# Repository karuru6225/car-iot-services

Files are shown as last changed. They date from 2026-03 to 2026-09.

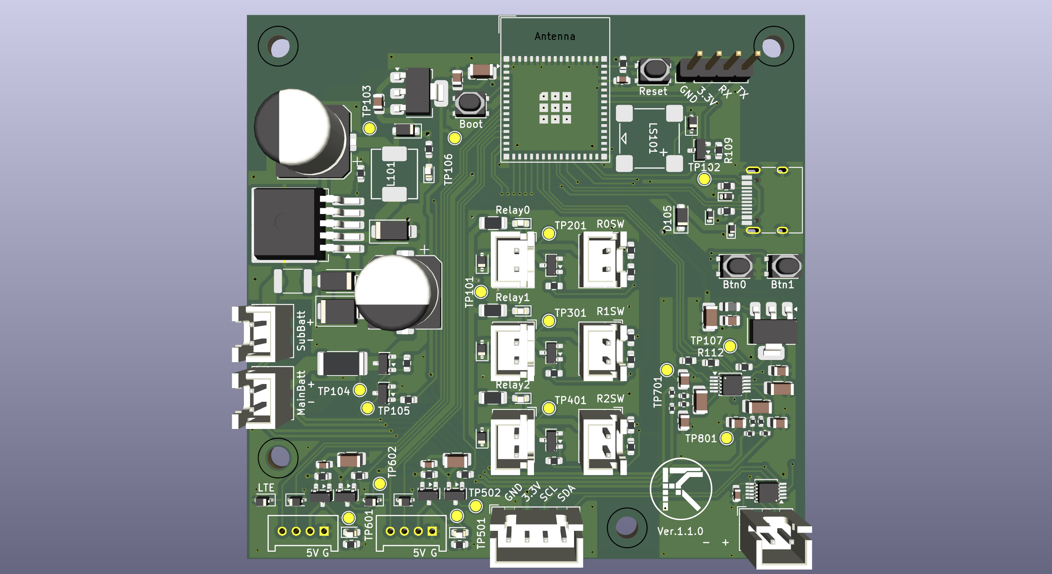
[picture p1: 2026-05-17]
test_board/m5atom_power_adc.png

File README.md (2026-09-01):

# car-iot-services

車載 IoT システム。ESP32-S3 が車載バッテリー電圧・電流・電力を計測し、
SORACOM Cat-M 経由で AWS IoT Core に送信する。
クラウド側では S3 + Athena でデータを蓄積し、CloudFront ホスティングの Web 管理画面でグラフ表示・削除操作を行える。

## システム構成

```text
ESP32-S3-MINI-1 (esp32_iot_gateway)
  ├── ADS1115 で 2 系統バッテリー電圧測定（サブ / メイン）
  ├── INA228 でサブバッテリー電流・電力・温度測定
  └── BLE スキャンで SwitchBot センサー（温湿度計 / CO2）受信
        ↓ MQTT over TLS
  SIM7080G (SORACOM Cat-M)
        ↓
  AWS IoT Core
  ├── Topic Rule → Lambda (ingest) → S3 (raw/year=.../month=.../day=.../hour=.../)
  │                                         ↓ Glue + Athena
  │                                   API Gateway → Lambda (query / delete)
  │                                         ↑ CloudFront → Web 管理画面 (index.html)
  ├── Shadow (desired/delta) → デバイス設定変更（充電制御・閾値等）
  └── IoT Jobs → OTA ファームウェア更新

  ※ 上記の LTE 経路とは別に、車内では BLE でスマートフォンと直接つながる
ESP32-S3-MINI-1 (esp32_iot_gateway)
        ↓ BLE (GATT Notify: 計測値・OBD-II)
  Android アプリ (car_iot_android)
    ├── Foreground Service で接続維持（アプリを閉じても受信継続）
    ├── Room に蓄積 → API Gateway へバッチアップロード（Cognito 認証）
    └── バッテリー / OBD / メーター表示・PiP
```

## ハードウェア

| 項目 | 内容 |
| ---- | ---- |
| MCU | ESP32-S3-MINI-1-N8（`m5atom_power_adc` 基板直付け） |
| ADC | ADS1115（I2C: SDA=GPIO17, SCL=GPIO18, ADDR=0x48） |
| 電流計 | INA228（I2C: SDA=GPIO17, SCL=GPIO18, ADDR=0x40） |
| OLED | SSD1306 128×64（I2C: SDA=GPIO17, SCL=GPIO18, ADDR=0x3C） |
| BLE | SwitchBot WoIOSensor（温湿度計）/ CO2センサー（アドバタイズ受信） |
| ボタン | GPIO26（Btn0）/ GPIO33（Btn1） |
| LTE | M5Stack U128（SIM7080G CAT-M/NB-IoT）、SORACOM SIM |
| 電源 | 車載 12V → LM2596（12V→5V）→ AMS1117-3.3（5V→3.3V）→ ESP32 |

## リポジトリ構成

```text
car-iot-services/
├── esp32_iot_gateway/     ESP32-S3-MINI-1 ゲートウェイ（アクティブ）
│   ├── ARCHITECTURE.md    レイヤー構成・依存ルール
│   ├── CONTEXT.md         実装詳細・設計決定・TODO
│   ├── OTA.md             OTA 仕様
│   ├── RELEASE.md         リリース手順（GitHub Actions）
│   └── MENU.md            OLED メニュー仕様
├── m5atom_iot_gateway/    M5Atom S3 ゲートウェイ（段階的廃止予定）
├── car_iot_android/       Android アプリ（Kotlin + Jetpack Compose、BLE 受信・アップロード）
│   └── CONTEXT.md         実装状態・実機検証メモ・UIデザインの設計判断
├── m5atom_power_adc/      新 PCB KiCad プロジェクト（電源・ADC・リレー・ESP32-S3 直付け）
│   ├── HARDWARE.md        ハードウェア設計仕様（BOM・回路・PCB レイアウト）
│   ├── CIRCUIT.md         回路設計仕様書
│   └── *.kicad_sch        階層シート構成（メイン + GroveUnit / RelayControl / VoltageSense）
├── infra/                 クラウドインフラ（Terraform）
│   ├── manage.ps1         デプロイスクリプト（plan / apply）
│   └── lambda_src/        Lambda ソースコード
│       └── TESTING.md     Lambdaユニットテストの実行方法（Docker + moto + pytest）
├── ops/                   運用スクリプト
│   ├── provision_device.ps1  ESP32 初回プロビジョニング（証明書発行・SPIFFS 書き込み）
│   ├── gen_certs.ps1      証明書生成
│   └── send_command.ps1   IoT Jobs コマンド送信
├── web/
│   ├── index.html         Web 管理画面（グラフ表示・データ削除）
│   └── admin.html         管理画面（デバイス一覧・Shadow 設定・充電制御）
├── docs/                  調査・設計メモ
├── tools/                 開発補助ツール（KiCad MCP サーバー等）
├── rtx830_filter_updater/ RTX830 フィルタ更新スクリプト
├── ARCHITECTURE.md
├── CONTEXT.md             開発引き継ぎ資料
└── SIM7080G.md            SIM7080G AT コマンドリファレンス
```

## デプロイ

### 前提

- Terraform >= 1.5
- AWS CLI（認証済み）
- 以下のファイルを `infra/` に配置（gitignore 済み）:
  - `backend.tfbackend` — S3 バックエンド設定
  - `terraform.tfvars` — 変数定義（`hosted_zone_id`, `web_subdomain` 等、`terraform.tfvars.example` を参照）

### インフラ + Lambda

`infra/` ディレクトリで PowerShell を実行:

```powershell
# 変更確認
.\manage.ps1 plan

# 適用（確認プロンプトあり）
.\manage.ps1 apply

# 確認なしで即適用
.\manage.ps1 apply -AutoApprove

# AWS プロファイルを指定する場合
.\manage.ps1 apply -Profile myprofile
```

Lambda コード（`lambda_src/`）の変更も `apply` で自動デプロイされる（`archive_file` の `source_code_hash` で変更検知）。

### Web 管理画面

`index.html` は `aws_s3_object` で Terraform 管理されているため、`manage.ps1 apply` で自動アップロードされる。
API エンドポイント・Cognito 設定はデプロイ時に Terraform が HTML 内のプレースホルダーを置換して埋め込む。

CloudFront のキャッシュ TTL はデフォルト 300 秒。URL は apply 後に確認できる:

```powershell
cd infra
terraform output web_url
```

## デバイスファームウェア

PlatformIO でビルド・書き込み。`esp32_iot_gateway/` を参照。

### 初回プロビジョニング

```powershell
cd ops
.\provision_device.ps1 -Port COM3
# AWS プロファイルを指定する場合
.\provision_device.ps1 -Port COM3 -Profile myprofile
# m5atom_power_adc v2 基板の場合（未指定時は v1 = 1）
.\provision_device.ps1 -Port COM3 -BoardVersion 2
```

スクリプトが MAC アドレスからデバイス ID（`esp32-gw-xxxxxxxxxxxx`）を生成し、AWS IoT Core に Thing を登録・証明書を発行・SPIFFS に書き込む。基板バージョンは NVS（`device/board_version`）にも書き込まれる。

同時に `-BoardVersion` に応じた Thing グループ（`ota-target-car-iot-gw-v1` または `-v2`）へも自動登録され、OTA の配信対象になる。グループに入っていないデバイスには OTA ジョブが届かない。

### OTA リリース

`vX.Y.Z` タグを push すると GitHub Actions が自動でビルド・S3 アップロード・IoT Job 作成・GitHub Release を実行する。MAJOR桁は基板シリーズ固定（1=v1基板、2=v2基板）。`src/config.h` の `FIRMWARE_VERSION_BASE` が正で、タグの数字と一致しないとビルドはエラーで停止する（先に `config.h` を更新してからタグを打つ）。

```powershell
git tag v1.2.3
git push origin main --tags
```

詳細は [esp32_iot_gateway/RELEASE.md](esp32_iot_gateway/RELEASE.md) および [esp32_iot_gateway/OTA.md](esp32_iot_gateway/OTA.md) を参照。

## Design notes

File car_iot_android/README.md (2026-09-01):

# car_iot_android

ESP32-S3ゲートウェイ（`esp32_iot_gateway`）とBLEで通信するAndroidネイティブアプリ（Kotlin + Jetpack Compose）。
バッテリー電圧・OBD-IIデータの表示に加え、Foreground Service化によりアプリを閉じてもBLE受信・データ
アップロードを継続する。Flutter版`mobile/`の後継（移植元として当面`mobile/`は残す）。

## 特徴

- **アプリを閉じてもBLE接続・受信が継続**（`CarIotForegroundService`、connectedDevice|location型）
- **CDM(Companion Device Manager)連携**でESP32のBLEアドバタイズを検知し、killed状態からでも自動起動
- **Room永続化**によるアップロードキュー（`CarIotUploadService`、dataSync型、Service強制終了への耐性）
- Cognito（Google連携）認証、位置情報付きOBD-IIデータのAPI Gatewayアップロード
- 4タブ構成（接続/バッテリー/OBD/メーター）、メータータブはゲージ4種・設定のJSON入出力に対応
- **ピクチャーインピクチャー(PiP)** 表示、計器盤ベースのナイト/デイ2テーマ

設計判断の経緯・実機検証メモは[CONTEXT.md](CONTEXT.md)、UIデザインの指針は[DESIGN.md](DESIGN.md)、
全体アーキテクチャ・フェーズ分割の計画書は[docs/car_iot_android_plan.md](../docs/car_iot_android_plan.md)を参照。

## 必要環境

- Android Studio（JBR同梱、Gradle実行に使う）
- Android実機またはエミュレータ（**BLE機能の検証には実機が必須**。エミュレータは物理Bluetoothアダプタを持たない）
- `minSdk = 36`（CompanionDeviceManagerの新API`startObservingDevicePresence(ObservingDevicePresenceRequest)`がAPI36必須のため）

## セットアップ

### 1. `infra/`を先にterraform applyしておく

Cognito（`mobile/`と同じApp Clientを共用）・API Gatewayエンドポイント一式が必要。`infra/README`または
`infra/manage.ps1`を参照。GoogleフェデレーテッドログインのOAuthクライアント作成手順は
[mobile/README.md](../mobile/README.md)の該当セクションを参照（`mobile/`と設定を共有するため一度作れば両方で使える）。

### 2. `AppConfig.kt`を作成

`app/src/main/kotlin/info/karuru/cariot/AppConfig.kt.example`をコピーして`AppConfig.kt`を作成し、
`terraform output`の値を埋める（`AppConfig.kt`はgitignore対象、実値をコミットしない）。

```bash
cd infra && ./manage.ps1 output -Profile default
```

必要な値: `cognito_mobile_client_id` / `aws_region` / `cognito_user_pool_id` / `api_endpoint`

### 3. ビルド

```bash
cd car_iot_android
./gradlew.bat assembleDebug
```

Gradle実行にはJDK（javacコンパイラ込み）が必要。システムの`JAVA_HOME`がJREのみの場合は`gradle.properties`の
`org.gradle.java.home`でAndroid Studio同梱のJBRを指す設定済み。

### 4. ユニットテスト

```bash
./gradlew.bat testDebugUnitTest
```

BLE非依存の純粋ロジック層（CRC8、OBDパーサー、チャンク再構成、アップロードスロットリング判定等）はTDDで実装済み。

### 5. 実機で起動

実機を接続し、Android Studioから実行するか：

```bash
./gradlew.bat installDebug
```

## 実車がなくてもBLE〜アップロードまで検証する（fakeobd）

OBD-IIケーブルを車両に物理接続していない環境でも、ESP32側に固定値+ランダムなダミーOBDデータを
BLE Notifyで送出させる派生env（`esp32-s3-devkitc-1-v1-develop-fakeobd`）が用意されている。

```bash
cd esp32_iot_gateway
~/.platformio/penv/Scripts/pio.exe run -e esp32-s3-devkitc-1-v1-develop-fakeobd -t upload
```

BLE接続・ゲージ表示・PiP・バックグラウンド継続・アップロードは、この構成で実機検証済み
（詳細は[CONTEXT.md](CONTEXT.md)の実機テスト結果を参照）。**実車のOBD-IIポートに接続しての動作確認はまだ**。
本番ファームに戻す時は`esp32-s3-devkitc-1-v1-develop`envで書き込み直すこと。

## 開発方針

- Android API非依存の純粋ロジック層（`obd/`, `ble/ObdChunkAssembler.kt`, `upload/`のスロットリング判定等）は
  TDD（Red→Green→Refactor）で実装する
- UI(Compose)描画・BLE実機接続・Foreground Serviceのライフサイクルは自動テストでの検証が困難なため、
  実機での動作確認を主軸とする

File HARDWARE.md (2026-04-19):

# ハードウェア設計メモ

## 概要

12V 車載バッテリー（サブバッテリー）から電源を取り、2系統のバッテリー電圧を監視する基板。
**案B（ESP32-S3-MINI-1 基板直付け）で設計確定。**

| 案 | MCU | 接続方式 | 状態 |
| -- | --- | --- | ---- |
| 案A（従来） | M5Atom S3（外付け） | Grove ケーブル 1 本（5V / GND / SDA / SCL） | 廃案 |
| **案B** | ESP32-S3-MINI-1-N8（基板直付け） | カステレーションはんだ付け | **採用** |

---

## システム構成

### 案A（M5Atom S3 外付け）

```text
[12V サブバッテリー]
        ↓
[本基板]
  保護回路（F1 → TVS1 → D1）
        ↓
  LM2596（12V → 5V）
        ↓
  CN4-A: GROVE コネクタ（5V + GND + SDA + SCL）
        ↓
[M5Atom S3] ← Grove ケーブル 1 本
  └── UART（GPIO5/6）→ U128（SIM7080G）← 別途 Grove 4線接続

[メインバッテリー +] → 分圧回路 → ADS1115 AIN0/AIN1
[サブバッテリー +]  → 分圧回路 → ADS1115 AIN2/AIN3
```

### 案B（ESP32-S3-MINI-1 基板直付け）

```text
[12V サブバッテリー]
        ↓
[本基板]
  保護回路（F1 → TVS1 → D1）
        ↓
  LM2596（12V → 5V）
        ↓
  ESP32-S3-MINI-1-N8（基板直付け）
    I2C ──→ ADS1115
    UART ──→ CN4-B: Grove コネクタ → U128（SIM7080G）

[メインバッテリー +] → 分圧回路 → ADS1115 AIN0/AIN1
[サブバッテリー +]  → 分圧回路 → ADS1115 AIN2/AIN3

[CN5: リレー出力] ←── FET × 3（GPIO 制御）※案B のみ
```

---

## 部品表（BOM）

### 電源回路（両案共通）

| Ref | 種別 | 仕様 | 数量 | 備考 |
| --- | ---- | ---- | ---- | ---- |
| F1 | ポリヒューズ | 1.5A | 1 | 過電流保護 |
| TVS1 | TVS ダイオード | P6KE18A | 1 | 車サージ対策（ロードダンプ最大60V） |
| D1 | ショットキーダイオード | SB360 | 1 | 逆接保護 |
| U1 | DC-DC コンバーター | LM2596-5.0 | 1 | 12V → 5V 固定出力 |
| L1 | インダクタ | 68μH / 1.5A 以上 | 1 | LM2596 必須部品 |
| D2 | ショットキーダイオード | SS34（3A/40V） | 1 | フリーホイールダイオード |
| C1 | 電解コンデンサ | 100μF / 35V | 1 | 入力平滑 |
| C2 | 電解コンデンサ | 220μF / 16V | 1 | 出力平滑 |
| C3 | セラミックコンデンサ | 100nF | 1 | 入力バイパス |
| C4 | セラミックコンデンサ | 100nF | 1 | 出力バイパス |

### 3.3V LDO 回路（両案共通）

| Ref | 種別 | 仕様 | 数量 | 備考 |
| --- | ---- | ---- | ---- | ---- |
| U3 | LDO レギュレーター | XC6206P332MR（SOT-23） | 1 | 5V → 3.3V、ADS1115 VDD・I2C プルアップ用 |
| C9 | セラミックコンデンサ | 100nF | 1 | U3 入力パスコン |
| C10 | セラミックコンデンサ | 100nF | 1 | U3 出力パスコン |

> 代替品: AMS1117-3.3（SOT-223）。XC6206 の方が Iq が低く（約 1μA）省電力。
> 案B では ESP32-S3-MINI-1 の 3V3 ピン（最大 ~700mA）で代替も可能だが、アナログ回路への影響を考慮して独立 LDO を推奨。

### MCU（案B のみ）

| Ref | 種別 | 仕様 | 数量 | 備考 |
| --- | ---- | ---- | ---- | ---- |
| U4 | MCU モジュール | ESP32-S3-MINI-1-N8 | 1 | LCC パッケージ、基板直付け（カステレーション） |
| R7 | チップ抵抗 | 10kΩ | 1 | EN ピンプルアップ（3.3V → EN）。省略すると起動しない |

### ADS1115 回路（両案共通）

| Ref | 種別 | 仕様 | 数量 | 備考 |
| --- | ---- | ---- | ---- | ---- |
| U2 | ADC | ADS1115 SSOP-10 | 1 | ADDR → GND でアドレス 0x48 |
| R1, R3 | チップ抵抗 | 680kΩ **1%** | 2 | 分圧上側（ch1 / ch2） |
| R2, R4 | チップ抵抗 | 22kΩ **1%** | 2 | 分圧下側（ch1 / ch2） |
| R5, R6 | チップ抵抗 | 10kΩ | 2 | SDA / SCL プルアップ（**3.3V = U3 出力**） |
| C5, C6 | セラミックコンデンサ | 100pF | 2 | AIN-GND ノイズフィルタ |
| C7 | セラミックコンデンサ | 100nF | 1 | VDD デカップリング |
| C8 | 電解 / タンタル | 10μF / 10V | 1 | VDD デカップリング |

### リレー制御回路（案B のみ）

外部リレー（最大 3 個）を GPIO で制御するための NPN BJT ドライバ回路。

| Ref | 種別 | 仕様 | 数量 | 備考 |
| --- | ---- | ---- | ---- | ---- |
| Q3, Q4, Q7 | NPN BJT | MMBT2222A（SOT-23） | 3 | hFE ≥ 100、Vceo = 40V |
| R（ベース） | チップ抵抗 | 1kΩ | 3 | Ib = (3.3−0.7)/1kΩ = 2.6mA、コイル電流 100mA に対して十分な飽和 |
| D（コイル並列） | 小信号ダイオード | 1N4148 | 3 | フライバックダイオード（リレーコイル並列、逆向き） |

```text
GPIO ──[1kΩ]──→ Base
                MMBT2222A
                Collector ──→ リレーコイル低電位側（コイル高電位側: +12V）
                Emitter  → GND

リレーコイル: +12V ─── コイル ─── Collector
                           │
                        [1N4148 逆向き]（フライバック）
```

### パワースイッチ回路（LTE モジュール・Grove 予備コネクタ電源）

AO3401A（P-ch MOSFET）+ MMBT2222A（NPN レベルシフタ）で 5V ラインを ESP32 GPIO でスイッチする。

```text
+5V ─── AO3401A(S) ─── AO3401A(D) ─── 負荷（LTE / Grove）
           ↑ Gate
         MMBT2222A(C) ── 10kΩ ── +5V
         MMBT2222A(B) ── 1kΩ ── ESP32 GPIO
         MMBT2222A(E) → GND
```

GPIO HIGH → MMBT2222A ON → Gate ≈ 0V（Vgs < −Vth）→ AO3401A ON → 電源供給  
GPIO LOW → MMBT2222A OFF → Gate ≈ +5V（Vgs = 0V）→ AO3401A OFF → 電源遮断

### ブザー回路（案B のみ）

AO3401A（P-ch MOSFET）ハイサイドスイッチで電磁パッシブブザーを駆動。

```text
+3.3V（U5出力） ─── Source(AO3401A/Q10)
                        │
                     Drain ─── LS1(+) ─── LS1(−) ─── GND
                                    │
                                [D19: 1N4148（フライバック）]
                                カソード → LS1(+)/Drain 側
                                アノード → LS1(−)/GND 側

GPIO34(SPEAKER) ──[R39: 10kΩ]──→ Gate(Q10)
```

GPIO LOW → Gate = 0V、Vgs = −3.3V → AO3401A ON → ブザー発音（**負論理**）  
GPIO HIGH → Gate = +3.3V、Vgs = 0V → AO3401A OFF → 消音

| 部品 | 値 | 備考 |
| ---- | -- | ---- |
| Q10 | AO3401A（SOT-23） | 既存 BOM 流用 |
| R39 | 10kΩ | ゲート直列抵抗（プルアップ兼用） |
| D19 | 1N4148（SOD-323 等） | フライバック保護 |
| LS1 | MLT-8530（LCSC: C94599） | 電磁パッシブ、8.5×8.5mm SMD、2.5〜4.5V |
| 電源 | +3.3V（U5 出力） | U3（+3.3VA）には接続しない |
| GPIO | GPIO34 | LEDC PWM 対応 |

**駆動条件（最大音量）：** 2700Hz（機械的共振周波数）、50% デューティ  
**最大電流：** 3.3V / ~52.6Ω（実効インピーダンス）≈ 63mA（MLT-8530 定格範囲内）

### リレーコイルセンシング回路

リレーに並列接続された外部スイッチによる ON をセンシングする分圧回路。

```text
+12V ─── 100kΩ ─── Vsense ─── 27kΩ ─── GND
                      │
               ESP32 GPIO（入力）
```

| 状態 | Vsense | 論理 |
| ---- | --- | ---- |
| リレーOFF（コイル断） | 12 × 27/(100+27) ≈ **2.55V** | HIGH（VIH = 2.475V ✓） |
| リレーON（Collector 引き込み） | ≈ 0V | LOW |

**負論理**（HIGH = リレー OFF）。コイル未接続時も 0V になる点に注意。

### コネクタ

| Ref | 種別 | 数量 | 案A | 案B | 備考 |
| --- | ---- | ---- | --- | --- | ---- |
| CN1 | JST-XH 2ピン | 1 | ○ | ○ | 12V 電源入力（+ / GND） |
| CN2 | JST-XH 2ピン | 1 | ○ | ○ | バッテリー 1 電圧入力（メインバッテリー） |
| CN3 | JST-XH 2ピン | 1 | ○ | ○ | バッテリー 2 電圧入力（サブバッテリー） |
| CN4-A | HY2.0-4P（Grove） | 1 | ○ | — | M5Atom S3 接続（5V / GND / SDA / SCL） |
| CN4-B | HY2.0-4P（Grove） | 1 | — | ○ | U128 接続（5V / GND / TX / RX） |
| CN5 | JST-XH 4ピン | 1 | — | ○ | リレー出力 × 3 + 予備 1 |

---

## 分圧回路

### 定数

| 定数 | 値 |
| ---- | -- |
| R1（上側） | 680kΩ 1% |
| R2（下側） | 22kΩ 1% |
| 分圧比 | 22k / (680k + 22k) ≒ 0.0313（1/31.9） |
| ADS1115 ゲイン | GAIN_EIGHT（±0.512V） |
| 理論分解能 | 約 1mV / LSB（バッテリー端換算） |

### 対応電圧範囲

- 最大: 約 16.4V（ADS1115 入力 0.512V = FSR）
- LiFePO4 4S: 10.0V（放電）～ 14.6V（充電）→ 0.313V ～ 0.457V
- 鉛バッテリー 12V: 10.5V ～ 14.7V → 0.329V ～ 0.460V

どちらも ±0.512V レンジ内に収まる。

---

## Grove コネクタ ピン配置

### CN4-A — M5Atom S3 接続（案A）

M5Atom S3 の Port A（HY2.0-4P）に直結する。

| ピン | 信号 | 備考 |
| ---- | ---- | ---- |
| 1 | GND | |
| 2 | VCC | 5V（LM2596 出力） |
| 3 | SDA | ADS1115 SDA（G38） |
| 4 | SCL | ADS1115 SCL（G39） |

Port A の VCC は 5V 出力であることを実機で確認済み。

### CN4-B — U128 接続（案B）

U128（SIM7080G）に Grove ケーブル 1 本で電源と UART を供給する。

| ピン | 信号 | 備考 |
| ---- | ---- | ---- |
| 1 | GND | |
| 2 | VCC | 5V（LM2596 出力） |
| 3 | TX | ESP32-S3 → U128 RXD |
| 4 | RX | ESP32-S3 ← U128 TXD |

---

## 消費電流（案B 参考値）

5V ラインのピーク電流（LTE 送信中 + BLE スキャン中の同時発生時）：

| 機器 | ピーク電流 |
| ---- | --- |
| ESP32-S3-MINI-1 | ~240mA |
| U128（SIM7080G） | ~250mA |
| ADS1115 | ~0.2mA（無視可） |
| **合計** | **~500mA** |

12V 入力電流（LM2596 効率 80% 想定）：約 260mA。F1 ポリヒューズ 1.5A は余裕あり。

---

## 予備 GPIO ジャンパランド（案B のみ）

ESP32-S3-MINI-1 の未使用 GPIO を将来の拡張向けにジャンパランドとして基板上に引き出す。
通常はオープン。使用時にハンダブリッジで導通させる。

| ランド | 想定用途 |
| --- | --- |
| JP1 | リレー 1 制御（Q1 GPIO） |
| JP2 | リレー 2 制御（Q2 GPIO） |
| JP3 | リレー 3 制御（Q3 GPIO） |
| JP4 | 予備 |
| JP5 | 予備 |

---

## PCB レイアウト指針

### ゾーン分離

```text
┌──────────────────────────────────────────────────┐
│ [CN1: 12V入力]                                   │
│      ↓                                           │
│ F1 → TVS1 → D1                                  │
│                                                  │
│ ┌─[スイッチング領域]──┐    ┌─[アナログ領域]──────┐ │
│ │ LM2596             │    │ ADS1115            │ │
│ │ L1（スイッチングノード近傍）│ │ C7/C8（VDD直近）  │ │
│ │ D2                 │    │ R5/R6（プルアップ） │ │
│ │ C1 / C2            │    │                    │ │
│ └────────────────────┘    └────────────────────┘ │
│           ↑ GND は 1 点で結合                     │
│                                                  │
│ [CN2: BAT1] → R1/R2 → ADS1115 AIN0/1            │
│ [CN3: BAT2] → R3/R4 → ADS1115 AIN2/3            │
│                                                  │
│ [CN4-A: Grove → M5Atom S3]  ※案A               │
│ [ESP32-S3-MINI-1 + CN4-B: Grove → U128]  ※案B  │
└──────────────────────────────────────────────────┘
```

### 重要ルール

1. **LM2596 のスイッチングノード**（L1・D2 が接続されるノード）のパターンは短く・面積を小さく保つ。最もノイズを放射する箇所。
2. ADS1115 は LM2596 から**基板の反対側**に配置する。
3. 分圧抵抗（R1～R4）は ADS1115 の近くに置き、パターンを短くする。
4. C7/C8（デカップリング）は ADS1115 の VDD ピン直近に配置する。
5. GND プレーン（ベタ）を使う場合も、スイッチング領域とアナログ領域の GND を **1 点で接続**する（スター GND）。
6. 案B: ESP32-S3-MINI-1 の**全 GND ピンは基板 GND に接続**する（放熱・ノイズ対策）。

---

## ファームウェアとの対応

| 設定 | 案A（M5Atom S3） | 案B（ESP32-S3-MINI-1） |
| ---- | --- | --- |
| I2C アドレス | `0x48`（ADDR → GND） | 同左 |
| SDA ピン | G38 | 要確定（ピン割り当てによる） |
| SCL ピン | G39 | 要確定（同上） |
| LTE RX ピン | GPIO6 | 要確定 |
| LTE TX ピン | GPIO5 | 要確定 |
| ゲイン | `GAIN_EIGHT`（±0.512V） | 同左 |
| 差動入力 ch1 | `readADC_Differential_0_1()` | 同左 |
| 差動入力 ch2 | `readADC_Differential_2_3()` | 同左 |

> 案B でピン番号確定後、`config.h` の `LTE_RX_PIN`, `LTE_TX_PIN` および I2C ピン定義を更新する。

---

## 精度向上のための推奨事項

- 分圧抵抗は **1% 精度品**を使用（5% 品は不可）
- 同一温度ドリフト品の抵抗を近傍配置してペア動作させる
- 必要に応じてソフトウェアでキャリブレーション補正を追加する
- 高精度が必要な場合は変換レートを 8SPS に設定し複数サンプル平均化を行う

---

## USB-C 受電回路

PC や充電器から 5V を受電するための USB-C レセプタクル回路。

| Ref | 種別 | 仕様 | 備考 |
| --- | ---- | ---- | ---- |
| CN_USB | USB-C レセプタクル | USB 2.0 | SBU1/SBU2 は NC |
| R_CC1, R_CC2 | チップ抵抗 | 5.1kΩ | CC1/CC2 → GND プルダウン（UFP 識別） |
| D_ESD | ESD 保護 | LESD5D5.0CT1G（SOT-23） | VBUS-GND 間 TVS、D+/D− 保護内蔵 |
| C_ESD | セラミックコンデンサ | 100nF | TVS と並列（高周波 ESD バイパス） |
| D4 | ショットキーダイオード | SSL36 | OR ダイオード（12V 電源と USB-C の電源切替） |

```text
USB-C VBUS ─── D_ESD ─── C_ESD(並列) ─── D4(SSL36) ─── +5V バス
                                              ↑
                              LM2596 出力も同じノードに接続（OR 接続）

CC1 ─── 5.1kΩ ─── GND
CC2 ─── 5.1kΩ ─── GND
```

USB-C から給電時は D4 のアノード側が VBUS 電圧、カソード側が +5V バス。  
LM2596 が動作中は +5V > VBUS の場合 D4 が逆バイアスになり USB-C 側への逆流を防ぐ。

---

## 回路検証結果（m5atom_power_adc.kicad_sch）

### リレー駆動トランジスタ（Q3/Q4/Q7）

MMBT2222A、`(mirror y)` 配置。ピン位置を座標計算で検証済み。

- **E（pin2） → GND2**（コモンエミッタ確認）
- **C（pin3） → リレーコイル低電位側 + LED陰極**
- LED点灯電流：I = (12 - Vce_sat - Vf) / 5.1kΩ ≈ **1.9mA**（正常点灯）

> kicad-happy / kicad-netlist-tool の解析ツールは `mirror` + `angle` 組み合わせ時に
> E/C を誤判定するバグがある。実回路はコモンエミッタで正しい。

### RelayXSense 回路（R27-R32）

| 状態 | V_sense | 論理 |
| ---- | --- | ---- |
| リレーOFF（コイル接続時） | 約 2.55V | HIGH |
| リレーON（Q または手動SW） | 約 0V | LOW |

**負論理**（HIGH=OFF）。コイル未接続時も 0V になる点に注意。

### USB-C SBU1/SBU2 ピン

USB 2.0 用途のみのため **NC（未接続）** が正しい。

---

## ADS1115 チャンネル割り当て

| チャンネル | 用途 | 測定方式 | ゲイン |
| --- | ---- | --- | --- |
| AIN0/AIN1 差動 | サブバッテリー電圧（J5） | 差動 | GAIN_EIGHT (±0.512V) |
| AIN2/AIN3 差動 | 車メインバッテリー電圧（J6） | 差動 | GAIN_EIGHT (±0.512V) |

分圧比: 22k / (680k + 22k) ≈ 0.0313。12V → 376mV、15V → 470mV（FSR内）。

複数チャンネル読み取り時は**チャンネル切り替え後に変換完了を待ってから読む**こと（`readADC_Differential_X_Y()` はシングルショットのため自動待機）。

---

## 拡張予定回路

### サブバッテリー電流計測・残量積算（LTC2944）

INA226 を廃案とし、LTC2944 を採用。DeepSleep 中もハードウェアでクーロン積算が継続できる。

| 項目 | 内容 |
| ---- | ---- |
| IC | **LTC2944IDD**（Industrial、−40〜85°C、DFN-10 3×3mm） |
| 接続 | ハイサイド（Battery+ と負荷の間）、既存 SDA/SCL に並列追加 |
| シャント | 0.625mΩ（±50mV / 80A） |
| 想定電流 | 最大 80A（常用 40A） |
| 特徴 | 16bit クーロンカウンタ、電圧・温度も計測、DeepSleep 中も積算継続 |
| フットプリント | `Package_DFN_QFN:DFN-10-1EP_3x3mm_P0.5mm_EP1.75x2.4mm` |
| 露出パッド | GND 接続必須（機械的固定）、サーマルビア 1〜2 本で GND プレーンへ |

```text
Battery(+) ─── R_SHUNT(0.625mΩ) ─── LTC2944(SENSE+/SENSE−) ─── 負荷
```

> IC の発熱は最大 1.8mW（20V × 90μA）のため、サーマルビアは熱対策ではなく機械的固定目的。

### サブ → メインバッテリー緊急充電回路

メインバッテリー電圧低下時にサブから一時的に補充する回路。

**回路構成（AO3401A + MMBT2222A 流用）：**

```text
Sub(+) ─── AO3401A(P-ch) ─── Schottkyダイオード ─── R_limit ─── Main(+)
               ↑ MMBT2222Aレベルシフタ経由
           ESP32 GPIO
```

| 部品 | 値 | 備考 |
| ---- | -- | ---- |
| Q（Pch MOSFET） | AO3401A | 既存 BOM 流用 |
| レベルシフタ | MMBT2222A | 既存 BOM 流用 |
| R_limit | **4.7Ω 3W**（C3924519、2512 SMD） | TE Connectivity 35224R7JT |

**制御ロジック：**

```text
開始: V_main < 11.5V かつ V_sub > 13.0V
停止: V_main > 12.3V または 経過時間 > 20分（安全タイマー）
間欠動作: 電圧差（ΔV = V_sub − V_main）に応じて ON 時間を変化（すべて 60秒 ON で統一可）
```

最大電流: 2.5V / 4.7Ω ≈ **0.53A**（ΔV_max = 14V - 11.5V 想定）。
最大発熱: 0.53² × 4.7 ≈ **1.3W**（定格 3W に対して余裕率 2.3 倍）。

充電電流は測定しない。制御はすべて ADS1115 で読んだ電圧値（V_main / V_sub）のみで行う。
LTC2944 はサブバッテリーの全出力電流（残量積算）を監視するが、充電回路の制御には使わない。

> 充電電流の推定値は `I ≈ ΔV / 4.7Ω` で計算できる（センサー実測ではなく計算値）。

### CAN Bus（将来検討）

ESP32-S3 内蔵 TWAI（CAN 2.0B）を使用。外付けトランシーバーのみ追加。

| 部品 | 内容 |
| ---- | ---- |
| トランシーバー | SN65HVD230（3.3V 動作、レベル変換不要） |
| 接続 | GPIO 2 本（TX/RX）+ CANH/CANL コネクタ（2 ピン） |
| 保護 | PESD1CAN 相当の TVS ダイオード推奨 |
| 終端 | 車両 CAN バスに既存終端があるため追加不要 |

---

## LED 選定

| 用途 | Ref | 色 | 選定品 | 動作電流 | 備考 |
| ---- | --- | -- | --- | --- | ---- |
| 電源インジケーター | D8 | 緑 | Würth 150060GS75000 | (5.0−3.2)/1kΩ = **1.8mA** | +5V ラインから給電、R16=1kΩ |
| リレーインジケーター | D15/D16/D18 | 黄 | Würth 150060YS75000 | (12−2.1)/5.1kΩ ≈ **1.9mA** | +12V ラインから給電、リレーコイル並列 |
| 汎用インジケーター | — | 赤 | XL-1608SURC-06（JLCPCB: C965799） | (12−2.3)/2kΩ ≈ **4.85mA** | +12V ラインから給電、1kΩ×2直列、225mcd@20mA |

> Würth 150060 シリーズ（0603）: Vf(green)=3.2V、Vf(yellow)=2.1V（typ, 20mA 時）。
> 動作電流が 2mA 前後のため、カタログ輝度（通常 20mA 時）の約 10% しか出ない。
> 明るい室内（30〜100mcd 必要）で視認するには **定格 300mcd 以上**の品を選ぶこと。
> XL-1608SURC-06（赤）は 5mA 時 ~54mcd。1kΩ を 2 個直列（各 23.5mW）で 0603 サイズ対応。

---

## PCB 配線太さ・ビアサイズ（電流パス）

1oz 銅箔（標準）、外層、温度上昇 10°C 基準。

### トレース幅

| レール / 用途 | 最大電流 | 推奨トレース幅 |
| --- | --- | --- |
| 充電回路 | ~0.5A | **0.5mm** |
| +12V 入力・LM2596 周辺 | ~1A | **1.5mm** |
| LM2596 スイッチングノード（出力ピン〜D2〜L1） | ~1A ピーク | **1.5mm**（ループ面積を最小に） |
| +5V バス | ~500mA | **0.8mm** |
| +3.3V デジタル | ~350mA | **0.5mm** |
| +3.3VA アナログ・信号・GPIO | <5mA | **0.3mm** |

### ビアサイズ

| 電流 | 穴径 | ランド径 | 備考 |
| ---- | ---- | --- | ---- |
| ~500mA | 0.4mm | 0.8mm | 充電回路 |
| ~1A | 0.4mm | 0.8mm | +12V・スイッチングノード |
| ~500mA | 0.4mm | 0.8mm | +5V バス |
| <100mA | 0.3mm | 0.6mm | 信号線・+3.3V |

### LM2596 スイッチングノードの注意

スイッチングノード（LM2596 出力ピン〜D2〜L1 の三角ループ）はノイズのアンテナになるため、**ループ面積を最小化**することを最優先にする。トレース幅よりもパターンの短さ・小ささが重要。

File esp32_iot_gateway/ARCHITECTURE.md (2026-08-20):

# アーキテクチャ概要

## 層構成

3層アーキテクチャ（device / domain / service）で `src/` 以下を管理する。

```
src/
├── main.cpp          エントリポイント。各層を組み合わせてユースケースを実行する
├── config.h          全層から参照可能な定数・宣言（FIRMWARE_VERSION, SLEEP_INTERVAL_SEC 等。FIRMWARE_VERSIONはBOARD_VERSIONで基板シリーズ別に分岐）
├── config.cpp        config.h の実装（デバイスID取得, NVS アクセス等）
├── board_pins.h      全層から参照可能なピン配置（BoardPins構造体、boardPins()）。BOARD_VERSIONに応じてboard_pins_v1.h/v2.hをinclude
├── board_pins_v1.h   m5atom_power_adc v1基板の実ピン値
├── board_pins_v2.h   m5atom_power_adc v2基板の実ピン値
├── logger.h/.cpp     全層から参照可能なシリアルデバッグ出力（横断的関心事。実装はservice/log_storage.hに委譲）
├── provision.cpp     プロビジョニング専用（provision env のみビルド。通常ビルドから除外）
├── device/           ハードウェアドライバ層
├── domain/           ビジネスロジック層
└── service/          ユースケース層
```

---

## 各層の役割

### device/

ハードウェアへの直接アクセス。I2C / UART / GPIO / ATコマンドの制御を担う。
上位層（domain / service）を include してはいけない。

| ファイル | 役割 |
|---|---|
| `lte.h/.cpp` | SIM7080G ATコマンド制御（GPRS接続, 証明書アップロード, 電源管理, ファイル読み取り・削除） |
| `ble_scan.h/.cpp` | BLE スキャナー（SwitchBot Manufacturer Data 受信、FreeRTOS キュー経由で domain に渡す）。`start()`はブロッキング版（menu.cppのBLE登録画面用）、`startAsync()`/`isScanning()`/`stop()`は非同期版（monitor.cpp/main.cppが使用） |
| `ble_peripheral.h/.cpp` | `BlePeripheral` クラス。GATT Peripheral（計測値 Notify + 設定 R/W）、Passkey ペアリング |
| `ads.h/.cpp` | ADS1115 I2Cドライバ（`adsReadDiffMain()` = AIN0/AIN1 = メイン、`adsReadDiffSub()` = AIN2/AIN3 = サブ） |
| `ina228.h/.cpp` | `Ina228` クラス。INA228 I2Cドライバ（電流・電力・温度・積算電荷量の読み取り、電荷リセット） |
| `oled.h/.cpp` | SSD1306 OLEDドライバ（表示制御） |
| `speaker.h/.cpp` | ブザー / スピーカードライバ（tone PWM制御） |
| `button.h/.cpp` | デバウンス・長押し検出（`ButtonEvent`: BTN0_SHORT / BTN0_LONG / BTN1_SHORT / BTN1_LONG）、ピンは`begin()`で`boardPins()`から取得 |
| `can.h/.cpp` | GU0コネクタ経由のTWAI（CAN）ドライバ。Honda N-VAN OBD-II Mode 01（29bit拡張アドレッシング）の送受信、バスオフリカバリ。ISO-TP（ISO 15765-2）マルチフレーム受信（Flow Control自動送信）、複数PIDをまとめて1フレームで要求する多PID送信に対応 |

### domain/

ハードウェアにもネットワークにも依存しないビジネスロジック。
device / service を include してはいけない。標準ライブラリのみ使用可。

| ファイル | 役割 |
|---|---|
| `measurement.h` | 計測値の構造体（VoltageReading, PowerReading） |
| `telemetry.h/.cpp`  | `buildConfigPayload`（Shadow reported用JSON）+ `ITelemetryEncoder`（テンプレートメソッド。`JsonTelemetryEncoder`/`MsgPackTelemetryEncoder`が`encodeBattery`/`encodeThermometer`/`encodeCo2`を提供）。MsgPack版は`[magic 0xC1][version][本体][CRC32 4B]`でラップしパケット破損を検知する |
| `sensor.h` | BLE センサー共通構造体（SensorBase） |
| `thermometer.h/.cpp`| SwitchBot 温湿度計パーサー（ThermometerData / ThermometerParser）|
| `co2meter.h/.cpp` | SwitchBot CO2センサーパーサー（Co2MeterData / Co2MeterParser）|
| `sensor_factory.h/.cpp` | センサー種別振り分け（SensorVariant = std::variant） |
| `ble_targets.h/.cpp`| 監視対象 BLE アドレスの NVS 永続化（BleTargets、NS: "switchbot"）|
| `sensor_filter.h/.cpp` | BLE センサー値のメディアンフィルタ（`BLE_MEDIAN_FILTER`ビルドフラグ時のみ有効、直近3件のアドレス別履歴を保持）|
| `obd.h/.cpp` | OBD-II Mode 01 PID（全29種）の構造体（`OBDReading`）とデコード関数群。BLE送信用の固定レイアウト構造体（`ObdBlePacket`）と変換関数、多PID応答をPIDセグメント単位に分解する`obdParseMultiResponse()`も含む |
| `charging.h/.cpp` | 充電ヒステリシス判定（`decideCharging()`）。電圧・現在の充電状態・閾値から次の充電状態を返す純粋関数。`main.cpp`の`updateChargingState()`から呼ばれる |
| `url.h/.cpp` | URL文字列をhost/pathに分解する`parseUrl()`。`service/https.cpp`から呼ばれる |

### service/

ユースケースの実装。device と domain を組み合わせて目的を達成する。
同層間（service ↔ service）の参照は許容する。

| ファイル | 役割 |
|---|---|
| `mqtt.h/.cpp` | MQTT publish / subscribe / pollMqtt（device/lte をトランスポートとして使用） |
| `https.h/.cpp` | HTTPS GET（AT+SH* ストリーミング）/ ファイルダウンロード（AT+HTTPTOFS → SIM FS） |
| `jobs.h/.cpp` | AWS IoT Jobs プロトコル層（subscribe / get-next / report）。OTA・コマンド共通 |
| `ota.h/.cpp` | OTA 固有ロジック（ファームウェア適用・ロールバック管理・前回結果報告）。Jobs プロトコルは jobs.h に委譲 |
| `command.h/.cpp` | Jobs コマンドのディスパッチと実行（`ah_reset`、`charge_main_batt`） |
| `shadow.h/.cpp` | Shadow config publish・delta subscribe・設定変更の適用 |
| `monitor.h/.cpp` | 計測サイクル（`measure()`＝非同期BLEスキャン開始＋アナログ計測 / `collectBle()`＝スキャン完了時のみ収集 / `publishBattery()` / `publishBle()`）・`MeasureResult` 定義 |
| `menu.h/.cpp` | OLED + 2ボタン設定メニュー、`enterMenuMode()` → `OperationMode` を返す |
| `menu_util.h/.cpp` | メニュー用パスユーティリティ（pathPush / pathPop / pathTitle 等） |
| `obdpoll.h/.cpp` | `obdPoll()`。全29PIDを6PIDずつ計5リクエストにバッチ化して問い合わせ（`canInit()`済み前提）。CONTINUOUSモードの1秒ティックから呼ばれる。末尾でMode22 UDS単発リクエスト（DID 0x2201 ATF油温）も実行する |
| `diddscan.h/.cpp` | `didScanRun()`。Mode22 (UDS) DID総当たりスキャン。指定範囲を`22XXYY`で問い合わせ、正常応答とNRC 0x22/0x33ヒットのみ記録する。燃料残量・油温等の未確定DIDを探すための一時的な調査機能で、OLEDメニュー「OBD > DID Scan」から手動実行する |
| `operation_mode.h/.cpp` | `IOperationModeHandler`（`beforeRun()`/`run()`を持つ抽象ハンドラ）+ `OperationModeManager`。`OperationMode` ごとにハンドラインスタンスを登録・ディスパッチするレジストリ（`main.cpp`のloop()分岐を集約）。モード状態自体は持たず`OperationModeContext`を参照する |
| `mode_context.h/.cpp` | `OperationModeContext`。動作モードハンドラ間で共有する実行時状態（現在モード・直近計測値・BLE昇格フラグ等）。状態遷移系プロパティはsetter経由でのみ変更させ、変更時に`[MODE_CTX]`ログを出す |
| `mode_common.h/.cpp` | 複数モードハンドラから呼ばれる横断ヘルパー（`updateChargingState()`/`secsToNextBoundary()`/`pollBleCollect()`/`checkAndHandleJob()`） |
| `mode_deep_sleep.h/.cpp` | `DeepSleepModeHandler`。BLE接続によるCONTINUOUSへの自動昇格判定（`beforeRun()`）とDeepSleep突入処理（`run()`） |
| `mode_continuous_base.h/.cpp` | `ContinuousModeHandlerBase`。CONTINUOUS/TIMED_CONTINUOUS共通の5分待機ループ（`continuousLoopCore()`）とBLE切断による降格判定（`beforeRun()`） |
| `mode_continuous.h/.cpp` | `ContinuousModeHandler`（`ContinuousModeHandlerBase`派生）。無期限CONTINUOUS |
| `mode_timed_continuous.h/.cpp` | `TimedContinuousModeHandler`（`ContinuousModeHandlerBase`派生）。`OperationModeContext`の継続期限まで繰り返し、期限到達で自動DEEP_SLEEP |
| `pubqueue.h/.cpp` | オフラインバッファ（RTC メモリ + SPIFFS）・MQTT publish キュー管理 |
| `log_storage.h/.cpp` | デバッグログの SPIFFS 保存（起動ごと1ファイル、最大12ファイルのリングバッファ）。`logger.h/.cpp`（src直下、横断的関心事）から呼ばれる |

---

## 依存ルール

**上位層が下位層を参照する。逆方向は禁止。**

```
main.cpp
   ↓ 全層を参照可
service/  ←→  service/ （同層間は可）
   ↓
device/
   ↓
config.h / board_pins.h / logger.h  （全層から参照可）

domain/   （どこからでも参照可。自身は何にも依存しない）
```

### include の向き（具体例）

```cpp
// service/mqtt.cpp — OK
#include "mqtt.h"
#include "../device/lte.h"   // 下位層を参照
#include "../config.h"        // 横断的定数を参照

// device/lte.cpp — OK
#include "lte.h"
#include "../config.h"
#include "../logger.h"         // 横断的関心事を参照

// device/lte.cpp — NG
#include "../service/mqtt.h"  // 上位層の参照は禁止
```

---

## 命名規則

| 対象 | 規則 | 例 |
|---|---|----|
| ファイル名 | `snake_case` | `battery.h`, `ota.cpp` |
| クラス名 | `PascalCase` | `Lte`, `BatteryState` |
| 関数名 | `camelCase` | `getMqttHost()`, `readVoltage()` |
| 定数 | `UPPER_SNAKE_CASE` | `SLEEP_INTERVAL_SEC`, `MQTT_PORT` |
| グローバルインスタンス | `camelCase`（型名を短縮） | `lte`, `logger`, `ota` |

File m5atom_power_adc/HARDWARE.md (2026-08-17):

# ハードウェア設計メモ

## 概要

12V 車載バッテリー（サブバッテリー）から電源を取り、2系統のバッテリー電圧を監視する基板。
**案B（ESP32-S3-MINI-1 基板直付け）で設計確定。**

| 案 | MCU | 接続方式 | 状態 |
| -- | --- | --- | ---- |
| 案A（従来） | M5Atom S3（外付け） | Grove ケーブル 1 本（5V / GND / SDA / SCL） | 廃案 |
| **案B** | ESP32-S3-MINI-1-N8（基板直付け） | カステレーションはんだ付け | **採用** |

---

## システム構成

### 案A（M5Atom S3 外付け）

```text
[12V サブバッテリー]
        ↓
[本基板]
  保護回路（F1 → TVS1 → D1）
        ↓
  LM2596（12V → 5V）
        ↓
  CN4-A: GROVE コネクタ（5V + GND + SDA + SCL）
        ↓
[M5Atom S3] ← Grove ケーブル 1 本
  └── UART（GPIO5/6）→ U128（SIM7080G）← 別途 Grove 4線接続

[メインバッテリー +] → 分圧回路 → ADS1115 AIN0/AIN1
[サブバッテリー +]  → 分圧回路 → ADS1115 AIN2/AIN3
```

### 案B（ESP32-S3-MINI-1 基板直付け）

```text
[12V サブバッテリー]
        ↓
[本基板]
  保護回路（F1 → TVS1 → D1）
        ↓
  LM2596（12V → 5V）
        ↓
  ESP32-S3-MINI-1-N8（基板直付け）
    I2C ──→ ADS1115
    UART ──→ CN4-B: Grove コネクタ → U128（SIM7080G）

[メインバッテリー +] → 分圧回路 → ADS1115 AIN0/AIN1
[サブバッテリー +]  → 分圧回路 → ADS1115 AIN2/AIN3

[CN5: リレー出力] ←── FET × 3（GPIO 制御）※案B のみ
```

---

## 部品表（BOM）

### 電源回路（両案共通）

| Ref | 種別 | 仕様 | 数量 | 備考 |
| --- | ---- | ---- | ---- | ---- |
| F1 | ポリヒューズ | 1.5A | 1 | 過電流保護 |
| TVS1 | TVS ダイオード | P6KE18A | 1 | 車サージ対策（ロードダンプ最大60V） |
| D1 | ショットキーダイオード | SB360 | 1 | 逆接保護 |
| U1 | DC-DC コンバーター | LM2596-5.0 | 1 | 12V → 5V 固定出力 |
| L1 | インダクタ | 68μH / 1.5A 以上 | 1 | LM2596 必須部品 |
| D2 | ショットキーダイオード | SS34（3A/40V） | 1 | フリーホイールダイオード |
| C1 | 電解コンデンサ | 100μF / 35V | 1 | 入力平滑 |
| C2 | 電解コンデンサ | 220μF / 16V | 1 | 出力平滑 |
| C3 | セラミックコンデンサ | 100nF | 1 | 入力バイパス |
| C4 | セラミックコンデンサ | 100nF | 1 | 出力バイパス |

### 3.3V LDO 回路（両案共通）

| Ref | 種別 | 仕様 | 数量 | 備考 |
| --- | ---- | ---- | ---- | ---- |
| U3 | LDO レギュレーター | XC6206P332MR（SOT-23） | 1 | 5V → 3.3V、ADS1115 VDD・I2C プルアップ用 |
| C9 | セラミックコンデンサ | 100nF | 1 | U3 入力パスコン |
| C10 | セラミックコンデンサ | 100nF | 1 | U3 出力パスコン |

> 代替品: AMS1117-3.3（SOT-223）。XC6206 の方が Iq が低く（約 1μA）省電力。
> 案B では ESP32-S3-MINI-1 の 3V3 ピン（最大 ~700mA）で代替も可能だが、アナログ回路への影響を考慮して独立 LDO を推奨。

### MCU（案B のみ）

| Ref | 種別 | 仕様 | 数量 | 備考 |
| --- | ---- | ---- | ---- | ---- |
| U4 | MCU モジュール | ESP32-S3-MINI-1-N8 | 1 | LCC パッケージ、基板直付け（カステレーション） |
| R7 | チップ抵抗 | 10kΩ | 1 | EN ピンプルアップ（3.3V → EN）。省略すると起動しない |

### ADS1115 回路（両案共通）

| Ref | 種別 | 仕様 | 数量 | 備考 |
| --- | ---- | ---- | ---- | ---- |
| U2 | ADC | ADS1115 SSOP-10 | 1 | ADDR → GND でアドレス 0x48 |
| R1, R3 | チップ抵抗 | 680kΩ **1%** | 2 | 分圧上側（ch1 / ch2） |
| R2, R4 | チップ抵抗 | 22kΩ **1%** | 2 | 分圧下側（ch1 / ch2） |
| R5, R6 | チップ抵抗 | 10kΩ | 2 | SDA / SCL プルアップ（**3.3V = U3 出力**） |
| C5, C6 | セラミックコンデンサ | 100pF | 2 | AIN-GND ノイズフィルタ |
| C7 | セラミックコンデンサ | 100nF | 1 | VDD デカップリング |
| C8 | 電解 / タンタル | 10μF / 10V | 1 | VDD デカップリング |

### リレー制御回路（案B のみ）

外部リレー（最大 3 個）を GPIO で制御するための NPN BJT ドライバ回路。

| Ref | 種別 | 仕様 | 数量 | 備考 |
| --- | ---- | ---- | ---- | ---- |
| Q3, Q4, Q7 | NPN BJT | MMBT2222A（SOT-23） | 3 | hFE ≥ 100、Vceo = 40V |
| R（ベース） | チップ抵抗 | 1kΩ | 3 | Ib = (3.3−0.7)/1kΩ = 2.6mA、コイル電流 100mA に対して十分な飽和 |
| D（コイル並列） | 小信号ダイオード | 1N4148 | 3 | フライバックダイオード（リレーコイル並列、逆向き） |

```text
GPIO ──[1kΩ]──→ Base
                MMBT2222A
                Collector ──→ リレーコイル低電位側（コイル高電位側: +12V）
                Emitter  → GND

リレーコイル: +12V ─── コイル ─── Collector
                           │
                        [1N4148 逆向き]（フライバック）
```

### パワースイッチ回路（LTE モジュール・Grove 予備コネクタ電源）

AO3401A（P-ch MOSFET）+ MMBT2222A（NPN レベルシフタ）で 5V ラインを ESP32 GPIO でスイッチする。

```text
+5V ─── AO3401A(S) ─── AO3401A(D) ─── 負荷（LTE / Grove）
           ↑ Gate
         MMBT2222A(C) ── 10kΩ ── +5V
         MMBT2222A(B) ── 1kΩ ── ESP32 GPIO
         MMBT2222A(E) → GND
```

GPIO HIGH → MMBT2222A ON → Gate ≈ 0V（Vgs < −Vth）→ AO3401A ON → 電源供給  
GPIO LOW → MMBT2222A OFF → Gate ≈ +5V（Vgs = 0V）→ AO3401A OFF → 電源遮断

### ブザー回路（案B のみ）

AO3401A（P-ch MOSFET）ハイサイドスイッチで電磁パッシブブザーを駆動。

```text
+3.3V（U5出力） ─── Source(AO3401A/Q10)
                        │
                     Drain ─── LS1(+) ─── LS1(−) ─── GND
                                    │
                                [D19: 1N4148（フライバック）]
                                カソード → LS1(+)/Drain 側
                                アノード → LS1(−)/GND 側

GPIO34(SPEAKER) ──[R39: 10kΩ]──→ Gate(Q10)
```

GPIO LOW → Gate = 0V、Vgs = −3.3V → AO3401A ON → ブザー発音（**負論理**）  
GPIO HIGH → Gate = +3.3V、Vgs = 0V → AO3401A OFF → 消音

| 部品 | 値 | 備考 |
| ---- | -- | ---- |
| Q10 | AO3401A（SOT-23） | 既存 BOM 流用 |
| R39 | 10kΩ | ゲート直列抵抗（プルアップ兼用） |
| D19 | 1N4148（SOD-323 等） | フライバック保護 |
| LS1 | MLT-8530（LCSC: C94599） | 電磁パッシブ、8.5×8.5mm SMD、2.5〜4.5V |
| 電源 | +3.3V（U5 出力） | U3（+3.3VA）には接続しない |
| GPIO | GPIO34 | LEDC PWM 対応 |

**駆動条件（最大音量）：** 2700Hz（機械的共振周波数）、50% デューティ  
**最大電流：** 3.3V / ~52.6Ω（実効インピーダンス）≈ 63mA（MLT-8530 定格範囲内）

### リレーコイルセンシング回路

リレーに並列接続された外部スイッチによる ON をセンシングする分圧回路。

```text
+12V ─── 100kΩ ─── Vsense ─── 27kΩ ─── GND
                      │
               ESP32 GPIO（入力）
```

| 状態 | Vsense | 論理 |
| ---- | --- | ---- |
| リレーOFF（コイル断） | 12 × 27/(100+27) ≈ **2.55V** | HIGH（VIH = 2.475V ✓） |
| リレーON（Collector 引き込み） | ≈ 0V | LOW |

**負論理**（HIGH = リレー OFF）。コイル未接続時も 0V になる点に注意。

### コネクタ

| Ref | 種別 | 数量 | 案A | 案B | 備考 |
| --- | ---- | ---- | --- | --- | ---- |
| CN1 | JST-XH 2ピン | 1 | ○ | ○ | 12V 電源入力（+ / GND） |
| CN2 | JST-XH 2ピン | 1 | ○ | ○ | バッテリー 1 電圧入力（メインバッテリー） |
| CN3 | JST-XH 2ピン | 1 | ○ | ○ | バッテリー 2 電圧入力（サブバッテリー） |
| CN4-A | HY2.0-4P（Grove） | 1 | ○ | — | M5Atom S3 接続（5V / GND / SDA / SCL） |
| CN4-B | HY2.0-4P（Grove） | 1 | — | ○ | U128 接続（5V / GND / TX / RX） |
| CN5 | JST-XH 4ピン | 1 | — | ○ | リレー出力 × 3 + 予備 1 |

ACC 検知入力はコネクタ用のスペースが確保できず、スルーホールパッド 1 点（直接ハンダ付け、ハウジングなし）で対応。詳細は後述の「ACC 検知回路」参照。

---

## 分圧回路

### 定数

| 定数 | 値 |
| ---- | -- |
| R1（上側） | 680kΩ 1% |
| R2（下側） | 22kΩ 1% |
| 分圧比 | 22k / (680k + 22k) ≒ 0.0313（1/31.9） |
| ADS1115 ゲイン | GAIN_EIGHT（±0.512V） |
| 理論分解能 | 約 1mV / LSB（バッテリー端換算） |

### 対応電圧範囲

- 最大: 約 16.4V（ADS1115 入力 0.512V = FSR）
- LiFePO4 4S: 10.0V（放電）～ 14.6V（充電）→ 0.313V ～ 0.457V
- 鉛バッテリー 12V: 10.5V ～ 14.7V → 0.329V ～ 0.460V

どちらも ±0.512V レンジ内に収まる。

---

## Grove コネクタ ピン配置

### CN4-A — M5Atom S3 接続（案A）

M5Atom S3 の Port A（HY2.0-4P）に直結する。

| ピン | 信号 | 備考 |
| ---- | ---- | ---- |
| 1 | GND | |
| 2 | VCC | 5V（LM2596 出力） |
| 3 | SDA | ADS1115 SDA（G38） |
| 4 | SCL | ADS1115 SCL（G39） |

Port A の VCC は 5V 出力であることを実機で確認済み。

### CN4-B — U128 接続（案B）

U128（SIM7080G）に Grove ケーブル 1 本で電源と UART を供給する。

| ピン | 信号 | 備考 |
| ---- | ---- | ---- |
| 1 | GND | |
| 2 | VCC | 5V（LM2596 出力） |
| 3 | TX | ESP32-S3 → U128 RXD |
| 4 | RX | ESP32-S3 ← U128 TXD |

---

## 消費電流（案B 参考値）

5V ラインのピーク電流（LTE 送信中 + BLE スキャン中の同時発生時）：

| 機器 | ピーク電流 |
| ---- | --- |
| ESP32-S3-MINI-1 | ~240mA |
| U128（SIM7080G） | ~250mA |
| ADS1115 | ~0.2mA（無視可） |
| **合計** | **~500mA** |

12V 入力電流（LM2596 効率 80% 想定）：約 260mA。F1 ポリヒューズ 1.5A は余裕あり。

---

## 予備 GPIO ジャンパランド（案B のみ）

ESP32-S3-MINI-1 の未使用 GPIO を将来の拡張向けにジャンパランドとして基板上に引き出す。
通常はオープン。使用時にハンダブリッジで導通させる。

| ランド | 想定用途 |
| --- | --- |
| JP1 | リレー 1 制御（Q1 GPIO） |
| JP2 | リレー 2 制御（Q2 GPIO） |
| JP3 | リレー 3 制御（Q3 GPIO） |
| JP4 | 予備 |
| JP5 | 予備 |

---

## PCB レイアウト指針

### ゾーン分離

```text
┌──────────────────────────────────────────────────┐
│ [CN1: 12V入力]                                   │
│      ↓                                           │
│ F1 → TVS1 → D1                                  │
│                                                  │
│ ┌─[スイッチング領域]──┐    ┌─[アナログ領域]──────┐ │
│ │ LM2596             │    │ ADS1115            │ │
│ │ L1（スイッチングノード近傍）│ │ C7/C8（VDD直近）  │ │
│ │ D2                 │    │ R5/R6（プルアップ） │ │
│ │ C1 / C2            │    │                    │ │
│ └────────────────────┘    └────────────────────┘ │
│           ↑ GND は 1 点で結合                     │
│                                                  │
│ [CN2: BAT1] → R1/R2 → ADS1115 AIN0/1            │
│ [CN3: BAT2] → R3/R4 → ADS1115 AIN2/3            │
│                                                  │
│ [CN4-A: Grove → M5Atom S3]  ※案A               │
│ [ESP32-S3-MINI-1 + CN4-B: Grove → U128]  ※案B  │
└──────────────────────────────────────────────────┘
```

### 重要ルール

1. **LM2596 のスイッチングノード**（L1・D2 が接続されるノード）のパターンは短く・面積を小さく保つ。最もノイズを放射する箇所。
2. ADS1115 は LM2596 から**基板の反対側**に配置する。
3. 分圧抵抗（R1～R4）は ADS1115 の近くに置き、パターンを短くする。
4. C7/C8（デカップリング）は ADS1115 の VDD ピン直近に配置する。
5. GND プレーン（ベタ）を使う場合も、スイッチング領域とアナログ領域の GND を **1 点で接続**する（スター GND）。
6. 案B: ESP32-S3-MINI-1 の**全 GND ピンは基板 GND に接続**する（放熱・ノイズ対策）。

---

## ファームウェアとの対応

| 設定 | 案A（M5Atom S3） | 案B（ESP32-S3-MINI-1） |
| ---- | --- | --- |
| I2C アドレス | `0x48`（ADDR → GND） | 同左 |
| SDA ピン | G38 | GPIO17 |
| SCL ピン | G39 | GPIO18 |
| LTE RX ピン | GPIO6 | GPIO4（← U128 TXD） |
| LTE TX ピン | GPIO5 | GPIO5（→ U128 RXD） |
| ゲイン | `GAIN_EIGHT`（±0.512V） | 同左 |
| 差動入力 ch1 | `readADC_Differential_0_1()` | 同左 |
| 差動入力 ch2 | `readADC_Differential_2_3()` | 同左 |

---

## 精度向上のための推奨事項

- 分圧抵抗は **1% 精度品**を使用（5% 品は不可）
- 同一温度ドリフト品の抵抗を近傍配置してペア動作させる
- 必要に応じてソフトウェアでキャリブレーション補正を追加する
- 高精度が必要な場合は変換レートを 8SPS に設定し複数サンプル平均化を行う

---

## USB-C 受電回路

PC や充電器から 5V を受電するための USB-C レセプタクル回路。

| Ref | 種別 | 仕様 | 備考 |
| --- | ---- | ---- | ---- |
| CN_USB | USB-C レセプタクル | USB 2.0 | SBU1/SBU2 は NC |
| R_CC1, R_CC2 | チップ抵抗 | 5.1kΩ | CC1/CC2 → GND プルダウン（UFP 識別） |
| D_ESD | ESD 保護 | LESD5D5.0CT1G（SOT-23） | VBUS-GND 間 TVS、D+/D− 保護内蔵 |
| C_ESD | セラミックコンデンサ | 100nF | TVS と並列（高周波 ESD バイパス） |
| D4 | ショットキーダイオード | SSL36 | OR ダイオード（12V 電源と USB-C の電源切替） |

```text
USB-C VBUS ─── D_ESD ─── C_ESD(並列) ─── D4(SSL36) ─── +5V バス
                                              ↑
                              LM2596 出力も同じノードに接続（OR 接続）

CC1 ─── 5.1kΩ ─── GND
CC2 ─── 5.1kΩ ─── GND
```

USB-C から給電時は D4 のアノード側が VBUS 電圧、カソード側が +5V バス。  
LM2596 が動作中は +5V > VBUS の場合 D4 が逆バイアスになり USB-C 側への逆流を防ぐ。

---

## 回路検証結果（m5atom_power_adc.kicad_sch）

### リレー駆動トランジスタ（Q3/Q4/Q7）

MMBT2222A、`(mirror y)` 配置。ピン位置を座標計算で検証済み。

- **E（pin2） → GND2**（コモンエミッタ確認）
- **C（pin3） → リレーコイル低電位側 + LED陰極**
- LED点灯電流：I = (12 - Vce_sat - Vf) / 5.1kΩ ≈ **1.9mA**（正常点灯）

> kicad-happy / kicad-netlist-tool の解析ツールは `mirror` + `angle` 組み合わせ時に
> E/C を誤判定するバグがある。実回路はコモンエミッタで正しい。

### RelayXSense 回路（R27-R32）

| 状態 | V_sense | 論理 |
| ---- | --- | ---- |
| リレーOFF（コイル接続時） | 約 2.55V | HIGH |
| リレーON（Q または手動SW） | 約 0V | LOW |

**負論理**（HIGH=OFF）。コイル未接続時も 0V になる点に注意。

### USB-C SBU1/SBU2 ピン

USB 2.0 用途のみのため **NC（未接続）** が正しい。

### ACC 検知回路（deep sleep 復帰トリガー、案B のみ）

分圧を使わず、車の ACC（12V）ON/OFF を ESP32-S3 の GPIO で直接検知する回路。ACC ON で deep sleep から復帰させる用途。

```text
ACC(12V) ──┬──────────────── D109(BZT52C15, カソードをACC側) ──[R115: 1kΩ]── GND1
           │                        （サージ保護クランプ、R115でD109通過電流を制限）
           └──────────────── Q105(PDTC114YU,115) Base
                              +3.3V ──[R111: 10kΩ]── Collector ── GPIO1
                                                       Emitter ── GND1（配線都合、当初GND2予定から変更）

J109（ACC信号入力、1x1ピンヘッダー footprint、DNP）── ACC
```

| Ref | 種別 | 型番 | パッケージ | LCSC | 備考 |
| --- | ---- | ---- | --- | ---- | ---- |
| D109 | ツェナーダイオード | BZT52C15（15V） | SOD-123 | C2932746 | サージクランプ。カソード=ACC側、アノード=GND1側（座標検証済み） |
| Q105 | デジタルトランジスタ | PDTC114YU,115（NPN、内蔵 R1=10kΩ、R2=47kΩ） | SOT-323 | C80495 | ROHM DTC114EUA は新規設計非推奨のため他社品に変更。Emitter は配線都合で GND1（電源系）接続。VCEO=VCBO=50V、VEBO=6V、IC=100mA、Ptot=200mW（Nexperia公式データシート） |
| R111 | チップ抵抗 | 10kΩ | 0603 | — | Collector プルアップ |
| R115 | チップ抵抗 | 1kΩ | 0603 | C21190 | D109アノード-GND1間のサージ電流制限。ロードダンプサージ（最大60V級）時の D109 通過電流を制限。Q105 ベース駆動経路（ACC→内蔵R1）には挟まないため通常動作への影響なし |
| J109 | ピンヘッダー | Conn_01x01 | PinHeader_1x01_P2.54mm | — | ACC 信号入力。**DNP**（部品は実装せず、footprint のスルーホールパッドのみ使用して直接ハンダ付け） |

- ACC ON → Q105 ON → GPIO1 が **LOW**（オープンコレクタ、プルアップ構成）
- GPIO1 選定理由: ESP32-S3 の strapping pin（GPIO0/3/45/46）に該当せず、RTC GPIO対応。`esp_sleep_enable_ext1_wakeup()` の `ESP_EXT1_WAKEUP_ANY_LOW` で deep sleep 復帰に使う想定（未実装）
- GND は車体アースとサブバッテリー GND が NT101〜103（NetTie）で 1 点結合されているため、ACC 入力側の GND 配線は省略可（車から引くのは ACC 信号線 1 本のみ）
- ACC 入力はコネクタ用スペースが確保できず、J109（1x1 ピンヘッダー footprint）を DNP 設定にしてスルーホールパッドのみ使用。直接ハンダ付け＋熱収縮チューブで対応
- PCB配置: F.Cu（表面）、ESP32-S3-MINI-1 モジュール直下・アンテナキープアウトエリアは回避済み。DRC エラー 0 件確認済み（2026-08-17）。U103 の footprint（`RF_Module:ESP32-S2-MINI-1`、型番違い）は実績ありのため許容
- **ファームウェア未実装**。電源保持回路・理想ダイオード回路の検証用テストボード製造・テストが先。本製造後にファーム着手予定

---

## ADS1115 チャンネル割り当て

| チャンネル | 用途 | 測定方式 | ゲイン |
| --- | ---- | --- | --- |
| AIN0/AIN1 差動 | サブバッテリー電圧（J5） | 差動 | GAIN_EIGHT (±0.512V) |
| AIN2/AIN3 差動 | 車メインバッテリー電圧（J6） | 差動 | GAIN_EIGHT (±0.512V) |

分圧比: 22k / (680k + 22k) ≈ 0.0313。12V → 376mV、15V → 470mV（FSR内）。

複数チャンネル読み取り時は**チャンネル切り替え後に変換完了を待ってから読む**こと（`readADC_Differential_X_Y()` はシングルショットのため自動待機）。

---

## 拡張予定回路

### U128（SIM7080G）電源デカップリング

- U128 モジュール内部に 5V 側 22μF が搭載済み
- 外付けコンデンサ推奨値: **47μF + 100nF**（コネクタ端、X5R/X7R、16V 以上）
- 100nF は 50V 品でも問題なし

### サブバッテリー電流計測（INA228）

INA226 → LTC2944 と検討を経て、最終的に **INA228 を採用・実装済み**。

#### 部品比較

| 項目 | LTC2944 (C683672) | INA228 (C2862904) |
| ---- | --- | --- |
| パッケージ | DFN-8 (2×3mm) | VSSOP-10 |
| 自己電源 | SENSE+ から自己給電（3.6〜60V） | VS ピン必要（2.7〜5.5V） |
| 高圧側耐圧 | 60V | 85V |
| ADC | 16-bit | 20-bit |
| クーロンカウンタ | 16-bit | 40-bit |
| 電荷精度 | ±0.6% | ±1.0% FSR (max) |
| 電流精度 | ±0.4% | ±0.05% (max) |
| 温度測定 | あり（±3°C） | あり（±1°C） |
| I2C アドレス | 固定 0x64 | 16 通り（0x40〜0x4F） |
| LCSC 価格 | ~$12.4 | ~$3.0 |

**LTC2944 から INA228 への移行時の変更点:**

- フットプリント変更必須（DFN-8 → VSSOP-10）
- VS ピンに 3.3V 供給が必要
- I2C アドレス: 0x64 → 0x40（A0/A1=GND）※ 競合なし
- レジスタマップが異なる → ドライバ要書き直し

**INA228 注意事項（データシートより）:**

- 起動時に `SHUNT_CAL` レジスタを毎回書き込む必要あり（VS リセットで消える）
- ADCRANGE=1 使用時は `SHUNT_CAL` の計算値を×4する
- VS ピン直近に 100nF デカップリング必須
- IN+/IN- はケルビン接続推奨
- A0/A1 はフローティング禁止（GND/SCL/SDA/VS のいずれかに接続）
- VBUS は IN+ と同ノードに接続（PCB 上で直結可）

#### シャント抵抗選定

- バッテリー: LiFePO4 100Ah × 2 並列
- 配線: 14sq → 許容電流 約 80A（ボトルネック）
- シャント抵抗は**コネクタ経由で外付け**
- **ADCRANGE=1**（±40.96mV）採用
- 推奨シャント: **200A 75mV 品**（R = 0.375mΩ）
  - フルスケール電流: ±109A
  - 80A 時使用率: 73%
  - 電流 LSB: 208μA
- ログフォーマット: `x.xxA`（%.2f）
- 実用精度下限: 10mA 以上

### サブ → メインバッテリー緊急充電回路

メインバッテリー電圧低下時にサブから一時的に補充する回路。

**回路構成（AO3401A + MMBT2222A 流用）：**

```text
Sub(+) ─── AO3401A(P-ch) ─── Schottkyダイオード ─── R_limit ─── Main(+)
               ↑ MMBT2222Aレベルシフタ経由
           ESP32 GPIO
```

| 部品 | 値 | 備考 |
| ---- | -- | ---- |
| Q（Pch MOSFET） | AO3401A | 既存 BOM 流用 |
| レベルシフタ | MMBT2222A | 既存 BOM 流用 |
| R_limit | **4.7Ω 3W**（C3924519、2512 SMD） | TE Connectivity 35224R7JT |

**制御ロジック：**

```text
開始: V_main < 11.5V かつ V_sub > 13.0V
停止: V_main > 12.3V または 経過時間 > 20分（安全タイマー）
間欠動作: 電圧差（ΔV = V_sub − V_main）に応じて ON 時間を変化（すべて 60秒 ON で統一可）
```

最大電流: 2.5V / 4.7Ω ≈ **0.53A**（ΔV_max = 14V - 11.5V 想定）。
最大発熱: 0.53² × 4.7 ≈ **1.3W**（定格 3W に対して余裕率 2.3 倍）。

充電電流は測定しない。制御はすべて ADS1115 で読んだ電圧値（V_main / V_sub）のみで行う。
INA228 はサブバッテリーの全出力電流（残量積算）を監視するが、充電回路の制御には使わない。

> 充電電流の推定値は `I ≈ ΔV / 4.7Ω` で計算できる（センサー実測ではなく計算値）。

### CAN Bus（将来検討）

ESP32-S3 内蔵 TWAI（CAN 2.0B）を使用。外付けトランシーバーのみ追加。

| 部品 | 内容 |
| ---- | ---- |
| トランシーバー | SN65HVD230（3.3V 動作、レベル変換不要） |
| 接続 | GPIO 2 本（TX/RX）+ CANH/CANL コネクタ（2 ピン） |
| 保護 | PESD1CAN 相当の TVS ダイオード推奨 |
| 終端 | 車両 CAN バスに既存終端があるため追加不要 |

---

## LED 選定

| 用途 | Ref | 色 | 選定品 | 動作電流 | 備考 |
| ---- | --- | -- | --- | --- | ---- |
| 電源インジケーター | D8 | 緑 | Würth 150060GS75000 | (5.0−3.2)/1kΩ = **1.8mA** | +5V ラインから給電、R16=1kΩ |
| リレーインジケーター | D15/D16/D18 | 黄 | Würth 150060YS75000 | (12−2.1)/5.1kΩ ≈ **1.9mA** | +12V ラインから給電、リレーコイル並列 |
| 汎用インジケーター | — | 赤 | XL-1608SURC-06（JLCPCB: C965799） | (12−2.3)/2kΩ ≈ **4.85mA** | +12V ラインから給電、1kΩ×2直列、225mcd@20mA |

> Würth 150060 シリーズ（0603）: Vf(green)=3.2V、Vf(yellow)=2.1V（typ, 20mA 時）。
> 動作電流が 2mA 前後のため、カタログ輝度（通常 20mA 時）の約 10% しか出ない。
> 明るい室内（30〜100mcd 必要）で視認するには **定格 300mcd 以上**の品を選ぶこと。
> XL-1608SURC-06（赤）は 5mA 時 ~54mcd。1kΩ を 2 個直列（各 23.5mW）で 0603 サイズ対応。

---

## PCB 配線太さ・ビアサイズ（電流パス）

1oz 銅箔（標準）、外層、温度上昇 10°C 基準。

### トレース幅

| レール / 用途 | 最大電流 | 推奨トレース幅 |
| --- | --- | --- |
| 充電回路 | ~0.5A | **0.5mm** |
| +12V 入力・LM2596 周辺 | ~1A | **1.5mm** |
| LM2596 スイッチングノード（出力ピン〜D2〜L1） | ~1A ピーク | **1.5mm**（ループ面積を最小に） |
| +5V バス | ~500mA | **0.8mm** |
| +3.3V デジタル | ~350mA | **0.5mm** |
| +3.3VA アナログ・信号・GPIO | <5mA | **0.3mm** |

### ビアサイズ

| 電流 | 穴径 | ランド径 | 備考 |
| ---- | ---- | --- | ---- |
| ~500mA | 0.4mm | 0.8mm | 充電回路 |
| ~1A | 0.4mm | 0.8mm | +12V・スイッチングノード |
| ~500mA | 0.4mm | 0.8mm | +5V バス |
| <100mA | 0.3mm | 0.6mm | 信号線・+3.3V |

### LM2596 スイッチングノードの注意

スイッチングノード（LM2596 出力ピン〜D2〜L1 の三角ループ）はノイズのアンテナになるため、**ループ面積を最小化**することを最優先にする。トレース幅よりもパターンの短さ・小ささが重要。

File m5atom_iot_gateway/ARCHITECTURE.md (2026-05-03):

# アーキテクチャ概要（m5atom_iot_gateway）

> **注意**: このデバイスは段階的廃止予定。アクティブな開発は `esp32_iot_gateway` で行う。

## 層構成

```text
┌─────────────────────────────────────────┐
│          Application 層                  │
│   m5atom_iot_gateway.ino                │
│   app/register_mode.h / .cpp            │
├──────────────────┬──────────────────────┤
│   Domain 層      │   Presentation 層    │
│   domain/*       │   app/view.h / .cpp  │
├──────────────────┴──────────────────────┤
│         Infrastructure 層               │
│  infra/ble_scan, infra/button           │
│  infra/lte, infra/logger               │
├─────────────────────────────────────────┤
│              設定                        │
│           config.h / certs.h            │
└─────────────────────────────────────────┘
```

## ディレクトリ構成

```text
src/
├── m5atom_iot_gateway.ino   Application: メインループ・モード管理
├── config.h                 コンパイル時定数
├── certs.h                  AWS IoT Core 証明書（gitignore）
├── domain/                  Domain 層: Value Object・Repository
│   ├── sensor.h             SensorBase 基底 struct
│   ├── thermometer.h/.cpp   温湿度計データ・パーサー
│   ├── co2meter.h/.cpp      CO2センサーデータ・パーサー
│   ├── sensor_factory.h/.cpp  センサー種別判定・パーサー振り分け
│   └── targets.h/.cpp       監視対象リスト（NVS 永続化）
├── infra/                   Infrastructure 層: ハードウェア・外部アダプター
│   ├── ble_scan.h/.cpp      BLE スキャン・FreeRTOS キュー
│   ├── button.h/.cpp        GPIO ISR ボタン
│   ├── lte.h/.cpp           SIM7080G MQTT over TLS
│   └── logger.h/.cpp        Serial デバッグ出力
└── app/                     Application / Presentation 層
    ├── view.h/.cpp          Serial + Display 出力
    ├── register_mode.h/.cpp 登録ユースケース
    └── bypass_mode.h/.cpp   AT コマンド透過モード（デバッグ用）
```

## 各ファイルの責務

| ファイル | クラス / インスタンス | 責務 |
|---|---|---|
| `domain/sensor.h` | `SensorBase` (struct) | FreeRTOS キュー安全な基底（virtual 禁止） |
| `domain/thermometer` | `ThermometerData`, `ThermometerParser` | 温湿度計データ・パース |
| `domain/co2meter` | `Co2MeterData`, `Co2MeterParser` | CO2センサーデータ・パース |
| `domain/sensor_factory` | `SensorParserFactory` | センサー種別判定・パーサー振り分け |
| `domain/targets` | `Targets targets` | 監視対象アドレスの管理・NVS 永続化 |
| `infra/ble_scan` | `BleScanner scanner` | BLE スキャン・FreeRTOS キュー管理 |
| `infra/button` | `Button button` | GPIO ISR・ボタンイベント管理 |
| `infra/lte` | `Lte lte` | SIM7080G 制御・MQTT over TLS publish |
| `infra/logger` | `Logger logger` | Serial デバッグ出力 |
| `app/register_mode` | `RegisterMode regMode` | 登録ユースケースの制御フロー |
| `app/view` | `View view` | Serial + Display への出力 |
| `config.h` | — | コンパイル時定数 |
| `certs.h` | — | AWS IoT Core X.509 証明書・秘密鍵 |

### DDD 用語との対応

| DDD 用語 | 実体 |
|---|---|
| Value Object | `ThermometerData`, `Co2MeterData`（`SensorBase` 基底） |
| Aggregate + Repository | `Targets` |
| Application Service | `RegisterMode`, `.ino loop()` |
| Infrastructure Adapter | `BleScanner`, `Button`, `Lte`, `Logger` |
| Output Adapter | `View` |

## 依存ルール

依存方向は **上の層 → 下の層** のみ許可。

```text
.ino / app/register_mode
  └── domain/targets        (Targets)
  └── infra/*               (BleScanner, Button, Lte, Logger)
  └── app/view

app/view
  └── infra/ble_scan        (SensorVariant の型参照のみ)
  └── app/register_mode     (RegEntry の型参照のみ)

infra/ble_scan
  └── domain/sensor_factory (parse() 呼び出し)
  └── domain/targets        (targets.isTarget())
  └── app/register_mode     (regMode.isScanning/foundDevice)

infra/lte
  └── config.h + certs.h のみ

domain/* → config.h のみ
infra/*  → config.h + domain/* のみ（lte は certs.h も参照）
```

**禁止事項:**

- `domain/*` が `infra/*` や `app/view` を参照してはならない
- `infra/*` が `app/view` を参照してはならない

## グローバルインスタンス規則

各モジュールは `.cpp` にシングルトンインスタンスを定義し、`.h` で `extern` 宣言する。

```cpp
// domain/targets.cpp
Targets targets;

// domain/targets.h
extern Targets targets;
```

呼び出し元は `targets.load()`, `scanner.start()` のようなメソッド形式で使用し、
どのモジュールの機能かをコードで明示する。

## include 順序ルール

M5Unified は BLE ヘッダより**必ず先に** include しなければならない。
`view.h` が `<M5Unified.h>` を先頭で include しているため、`view.h` を最初に include することでこの順序を保証できる。

```cpp
#include "view.h"            // ← M5Unified をここで取り込む
#include "infra/ble_scan.h"  // ← BLE はその後
```

TinyGSM の define（`TINY_GSM_MODEM_SIM7080` 等）は `infra/lte.h` の include より**前に**書かなければならない。`infra/lte.h` 自体が先頭で define しているため、他ファイルで個別に define する必要はない。

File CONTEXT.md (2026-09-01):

# プロジェクトコンテキスト

## 概要

車載 IoT システム。ESP32-S3 が ADS1115 で 2 系統の車載バッテリー電圧を、
INA228 でサブバッテリーの電流・電力・温度を計測し、
SIM7080G（SORACOM Cat-M）経由で AWS IoT Core に MQTT over TLS で送信する。

クラウド側では S3 + Athena でデータを蓄積し、API Gateway + Lambda 経由で
CloudFront ホスティングの Web 管理画面からグラフ表示・削除操作を行える。

> **旧機種**: M5Atom S3 ベースの `m5atom_iot_gateway` は段階的廃止予定。
> アクティブな開発は `esp32_iot_gateway` で行う。

## データフロー

```text
ESP32-S3
  → MQTT over TLS（SIM7080G）
  → AWS IoT Core  topic①: sensors/{device_id}/data_bin  （バッテリーテレメトリ + BLE センサー、MessagePack）
                  topic②: $aws/things/{device_id}/shadow/update  （デバイス設定値の reported）
  → Topic Rule ingest_bin: SELECT encode(*,'base64') AS payload, topic(2) AS device_id FROM 'sensors/+/data_bin'
    → Lambda ingest（base64 decode → msgpack decode）→ S3: raw/.../{device_id}-{uuid8}.json

クラウド → デバイス（リモート設定変更）
  → Shadow desired を更新 → delta トピック → デバイスが NVS に適用

Web 管理画面（index.html）
  → GET /data?hours=24  → Lambda query → Athena（非同期ポーリング）→ S3
      ※ 各行に s3_key（Athena $path 疑似カラム）を含む
  → DELETE /data  body: {"s3_keys": [...]}  → Lambda delete → S3 直接削除
  → GET /status  → Lambda status → IoT Shadow（デバイス設定値の現在値）
  ※ 認証: Cognito JWT（API Gateway JWT Authorizer）、Hosted UI でログイン
  ※ タイムスタンプは JST 表示（Web 側で変換）

Admin コンソール（admin.html、admin グループユーザーのみ）
  → GET /admin/devices      → 全 esp32-gw-* デバイス一覧 + Shadow reported + Thing Groups
  → PUT /admin/shadow/{id}  → Shadow desired 更新（chg_start_v, chg_stop_v 等）
  → POST /admin/command/{id} → IoT Job 発行（ah_reset / charge_main_batt）
  → PUT /admin/groups/{id}  → Thing Group メンバーシップ変更

Android アプリ（car_iot_android）— 上記 LTE 経路とは独立した第2の経路
  ESP32-S3 → BLE GATT Notify（計測値・OBD-II）→ スマートフォン
  → CarIotForegroundService が接続維持（アプリを閉じても受信継続）
  → Room（pending_obd_reading）に蓄積
  → CarIotUploadService が API Gateway へバッチ POST（Cognito JWT、Web 管理画面と同じ認証基盤）
  ※ LTE 経路と違い車内でのリアルタイム表示が主目的。OBD-II データはこちらの経路のみ
```

## MQTT ペイロード形式

### バッテリーテレメトリ（esp32_iot_gateway）

トピック: `sensors/{device_id}/data_bin`（**v1.15.0 以降 MessagePack 形式**）

通信経路上のフィールド名は短縮形を使用。`ingest` Lambda が base64 decode → MessagePack decode → キー展開して S3 に保存する。実測ペイロード: **59 bytes**（旧 JSON ~96 bytes → 約 38% 削減）。

フィールド構成（MessagePack map。キーは下記 JSON 表記と同一）:

```json
{"t":"battery","m":12.34,"s":12.10,"i":5.2100,"p":62.500,"tp":28.5,"ah":200.001234,"ts":1746143400}
```

| 通信上のキー | S3 保存キー | 型 | 内容 |
| --- | --- | --- | --- |
| `t` | `type` | string | `"battery"` 固定 |
| `m` | `main` | float | メインバッテリー電圧（V） |
| `s` | `sub` | float | サブバッテリー電圧（V） |
| `i` | `current` | float | サブバッテリー電流（A） |
| `p` | `power` | float | サブバッテリー電力（W） |
| `tp` | `temp` | float | INA228 内蔵温度センサー（°C） |
| `ah` | `ah` | float | 積算電荷量（Ah）= INA228 積算値 + Ah オフセット |
| `ts` | `ts` | int | UNIX タイムスタンプ（秒） |

### デバイスシャドウ（設定値 reported）

トピック: `$aws/things/{device_id}/shadow/update`

```json
{"state":{"reported":{"ah_offset":200,"relay_mode":"sleep_indicator","chg_start_v":11.70,"chg_stop_v":12.50,"fw_version":"1.15.0+xxxxxxxx"}}}
```

### デバイスシャドウ（リモート設定変更）

クラウドから `desired` を更新するとデバイスが次回起動時に delta を受け取り適用する。

```json
{"state":{"desired":{"ah_offset":200}}}
{"state":{"desired":{"relay_mode":"off"}}}
{"state":{"desired":{"chg_start_v":11.5,"chg_stop_v":12.8}}}
```

対応フィールド:

- `ah_offset`（int）— Ah オフセット
- `relay_mode`（`"sleep_indicator"` or `"off"`）— リレー動作モード
- `chg_start_v`（float）— 自動充電開始電圧（V）、デフォルト 11.7
- `chg_stop_v`（float）— 自動充電停止電圧（V）、デフォルト 12.5

### 旧形式（m5atom_iot_gateway、段階的廃止予定）

```json
{"type":"thermometer","addr":"AA:BB:CC:DD:EE:FF","temp":25.0,"humidity":60,"battery":80,"rssi":-70,"mf":"09b0e9...","fw":"1.0.0+a364343b","ts":"2026-03-05T12:00:00Z"}
{"type":"co2meter","addr":"AA:BB:CC:DD:EE:FF","temp":25.0,"humidity":60,"co2":612,"battery":80,"rssi":-70,"mf":"09b0e9...","fw":"1.0.0+a364343b","ts":"2026-03-05T12:00:00Z"}
```

## S3 / Glue テーブルスキーマ

| カラム | 型 | 説明 |
| --- | --- | --- |
| `ts` | string | ISO8601 UTC タイムスタンプ |
| `type` | string | `"battery"` / `"thermometer"` / `"co2meter"` |
| `device_id` | string | IoT Thing 名（topic から抽出） |
| `main` | double | メインバッテリー電圧（V）※ battery のみ |
| `sub` | double | サブバッテリー電圧（V）※ battery のみ |
| `current` | double | 電流（A）※ battery のみ |
| `power` | double | 電力（W）※ battery のみ |
| `ah` | double | 積算電荷量（Ah）※ battery のみ |
| `addr` | string | BLE MAC アドレス ※ thermometer / co2meter のみ |
| `temp` | double | 温度（°C） |
| `humidity` | int | 湿度（%）※ thermometer / co2meter のみ |
| `battery` | int | BLE デバイスバッテリー（%）※ thermometer / co2meter のみ |
| `rssi` | int | RSSI（dBm）※ thermometer / co2meter のみ |
| `co2` | int | CO2 濃度（ppm）※ co2meter のみ |
| `voltage` | double | 電圧（V）※ 旧 m5atom battery 形式のみ |
| `id` | string | 電圧センサー識別子 ※ 旧 m5atom battery 形式のみ |
| `mf` | string | Manufacturer Data hex ※ 旧 m5atom 形式のみ |
| `fw` | string | ファームウェアバージョン ※ 旧 m5atom 形式のみ |
| `year/month/day/hour` | string | Hive パーティション（プロジェクション） |

## 重要な設計決定

### Athena 非同期クエリ（query Lambda）

1. `GET /data?hours=24[&type=battery|thermometer|co2meter]` で execution_id を返す
2. Web 側が 2 秒ポーリングで `GET /data?execution_id=xxx` を叩く
3. `SUCCEEDED` になったら結果を返す。各行に `s3_key`（Athena の `$path` 疑似カラム）を含む

### 行単位削除（delete Lambda）

`DELETE /data` に JSON body `{"s3_keys": ["s3://bucket/raw/..."]}` を渡すと、
Athena を使わず指定キーを直接 S3 削除する。
クエリ結果の `s3_key` を使うため、選択した行だけを正確に削除できる。

### LTE / MQTT（SIM7080G + AWS IoT Core）

- SIM7080G 内蔵 MQTT クライアント（AT+SMCONN / AT+SMPUB）を使用
- TLS 証明書は SPIFFS に保存（`/certs/ca.crt` 等）、起動時に CRC チェックして変更時のみモデムへ再アップロード
- DeepSleep 前に必ず `lte.disconnect()`（MQTT+GPRS 切断）を呼ぶ
- APN 設定は `CFUN=0 → CGDCONT → CFUN=1` の順（必須）
- `modem.restart()` は使わず `modem.init()` を使う

## 将来の拡張候補

- **BLE スキャン**: 基盤実装済み（`device/ble_scan`・`domain/sensor*`）。MQTT 送信も有効化済み
- **Jobs コマンド**: `ah_reset` 実装済み。リレー制御（`relay_on` / `relay_off`）は未実装
- **Web からのリモート設定**: Shadow desired 更新は Console/CLI から可能。Web ダッシュボードの設定 UI は未実装
- **DDoS・コスト対策強化**（不特定多数公開時）:
  - API も CloudFront 経由に統一し、API Gateway に Resource Policy で直接アクセスを禁止
  - CloudFront に AWS WAF を付けてレートリミットを適用（$5/月〜）
  - 現状は API GW スロットリングのみ適用（個人用途では十分）

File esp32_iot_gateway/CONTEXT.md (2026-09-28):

# プロジェクトコンテキスト

## 概要

車載 IoT システム。ESP32-S3-MINI-1 が ADS1115 でサブ/メイン 2 系統のバッテリー電圧を測定し、
INA228 でサブバッテリーの電流・電力・積算電力量を測定し、
SwitchBot BLE センサー（WoIOSensor 防水温湿度計 / CO2センサー）の BLE アドバタイズをスキャンして、
SIM7080G（SORACOM Cat-M）経由で AWS IoT Core に MQTT over TLS で送信する。

クラウド側は m5atom_iot_gateway と共通（S3 + Athena + API Gateway + Lambda + CloudFront）。

## ハードウェア

| 項目 | 内容 |
| ---- | ---- |
| MCU | ESP32-S3-MINI-1-N8（KiCad プロジェクト `m5atom_power_adc` 基板直付け） |
| ディスプレイ | なし |
| ボタン | GPIO26（Btn0）/ GPIO33（Btn1）（Active-LOW、外部プルアップ） |
| ADC | ADS1115（I2C: SDA=GPIO17, SCL=GPIO18, ADDR=0x48） |
| 電圧測定回路 ch0 | 差動入力（AIN0-AIN1）、分圧回路 R_upper=680kΩ / R_lower=22kΩ、GAIN_EIGHT(±0.512V)、**メインバッテリー** |
| 電圧測定回路 ch1 | 差動入力（AIN2-AIN3）、分圧回路 R_upper=680kΩ / R_lower=22kΩ、GAIN_EIGHT(±0.512V)、**サブバッテリー** |
| ADC_READY | GPIO16（ADS1115 ALERT/RDY、変換完了割り込み） |
| 電流計 | INA228（I2C: SDA=GPIO17, SCL=GPIO18, ADDR=0x40、A0/A1=GND） |
| 電流計対象 | サブバッテリー電流・電力・積算電力量・温度 |
| 電流計シャント | コネクタ経由外付け、200A 75mV 品（R=0.375mΩ）、ADCRANGE=1（±40.96mV） |
| OLED | I2C 接続予定（コネクタ経由、SDA=GPIO17, SCL=GPIO18）※未実装 |
| センサー | SwitchBot WoIOSensor（温湿度計）/ CO2センサー（BLE アドバタイズのみ、接続不要） |
| LTE | M5Stack U128（SIM7080G CAT-M/NB-IoT）、SORACOM SIM |
| LTE ピン | RX=GPIO7 ← U128 TXD、TX=GPIO8 → U128 RXD（筐体都合によりGrove Unit 1経由。基板シルク上のLTE_RX/TX/ENラベルとは不一致） |
| LTE 電源 | GPIO9（LTE_EN: HIGH=ON、AO3401A パワースイッチ経由） |
| 電源 | 車載 12V バッテリー → LM2596（12V→5V）→ AMS1117-3.3（5V→3.3V）→ ESP32 |

> **参照**: 回路詳細は `m5atom_power_adc/CIRCUIT.md`、部品・GPIO設計は `HARDWARE.md` を参照。

## 動作モード

### 起動フロー（共通）

1. 周辺機器初期化（OLED / ADS / INA228 / スピーカー / ボタン / BLE スキャナー）
2. DeepSleep 復帰かどうかを `esp_sleep_get_wakeup_cause()` で判定（復帰時はメロディをスキップ）
3. BTN0 を押しながら起動 → `enterMenuMode()` → `OperationMode` を返す（LTE 未起動のままオフライン動作）
4. LTE 接続 → OTA チェック → `loop()` へ

### DEEP_SLEEP モード（`#define DEBUG_MODE` コメントアウト時のデフォルト）

`loop()` が1サイクルで完結し DeepSleep に入る：

1. `measure()`: BLE スキャン（10秒）+ ADS1115/INA228 読み取り → `MeasureResult` を返す
2. `publish()`: Shadow + BLE センサーペイロードを MQTT publish
3. OLED に計測値を表示
4. LTE 切断 → `lte.radioOff()`（LTE_EN=LOW）→ DeepSleep 5分 → `setup()` から再起動

### CONTINUOUS モード（`#define DEBUG_MODE` 有効時のデフォルト、またはメニューで選択）

`loop()` が繰り返す：

1. `measure()` → `publish()` → OLED 表示（DEEP_SLEEP モードと同じ計測・送信処理）
2. SLEEP_INTERVAL_SEC（300秒）待機しながらボタン監視・カウントダウン表示
   - BTN0 短押し: メニューを開く（終了後 OLED を計測値画面に復元）
   - BTN1 長押し: DEEP_SLEEP モードへ切り替え（次ループで DeepSleep）

### メニューモード（起動時 BTN0 長押し、または CONTINUOUS 待機中 BTN0 短押し）

OLED + 2ボタンの設定メニュー。詳細は `MENU.md` 参照。

- `BLE Settings/Register` — BLE スキャンして SwitchBot デバイスを NVS 登録
- `BLE Settings/Remove` — 登録済みデバイスを NVS から削除
- `Battery/Ah Offset` — 積算電荷量のオフセット設定（BTN0 短押し +50Ah / 長押し -50Ah、0〜300Ah）
- `Battery/Ah Reset` — INA228 積算電荷量リセット（Yes/No 確認あり）
- `Battery/Chg Timeout` — 充電タイムアウト設定（10/20/30/60 分、BTN0 で循環、デフォルト 20 分）
- `Battery/Start Charge` — メインバッテリー充電開始（V_sub > V_main を確認。カウントダウン中は任意ボタンで停止）
- `Sensor View` — ADS1115/INA228 リアルタイム表示（50ms 更新）
- `System/Info` — FW バージョン・デバイス ID 表示
- `System/Device QR` — デバイス ID の QR コード表示
- `System/NVS Clear` — 全 NVS 消去して再起動（MQTT ホストは保持）
- `Continuous` — CONTINUOUS モードで起動（LTE を開始して loop へ）
- `Restart` — `esp_restart()`

## ファイル構成

3層アーキテクチャ（device / domain / service）。詳細は `ARCHITECTURE.md` 参照。

```text
esp32_iot_gateway/
├── platformio.ini                     PlatformIO ビルド設定
├── extra_scripts.py                   ビルド前フック: git hash を GIT_HASH マクロとして注入
├── CONTEXT.md                         本ファイル
├── ARCHITECTURE.md                    レイヤー構成・依存ルール・命名規則
└── src/
    ├── main.cpp                       エントリポイント: 初期化・起動モード判定・loop() で計測/送信サイクル
    ├── config.h / config.cpp          全層共通定数・NVS アクセス（デバイスID / MQTT ホスト / 証明書 CRC / OTA ジョブID）
    ├── provision.cpp                  プロビジョニング専用（provision env のみビルド）
    ├── device/
    │   ├── lte.h/.cpp                 SIM7080G ATコマンド制御（GPRS接続・証明書アップロード・電源管理・ファイル読み取り・削除）
    │   ├── ble_scan.h/.cpp            BLE スキャナー（SwitchBot デバイス受信・FreeRTOS キュー）
    │   ├── ble_peripheral.h/.cpp     BLE Peripheral（GATT 計測 Notify + 設定 R/W・Passkey ペアリング）
    │   ├── ads.h/.cpp                 ADS1115 I2Cドライバ（差動電圧読み取り）
    │   ├── ina228.h/.cpp              INA228 I2Cドライバ（電流・電力・温度読み取り）
    │   ├── oled.h/.cpp                SSD1306 OLEDドライバ（表示制御）
    │   ├── speaker.h/.cpp             ブザードライバ（tone PWM制御・ノンブロッキング playTone() 含む）
    │   └── button.h/.cpp              デバウンス・長押し検出（BTN0/BTN1 ピン定数内包、フィードバック音内蔵）
    ├── domain/
    │   ├── measurement.h              計測値構造体（VoltageReading, PowerReading）
    │   ├── telemetry.h/.cpp           Shadow設定ペイロード組み立て + ITelemetryEncoder（Json/MsgPack、MsgPackはmagic+CRC32付与）
    │   ├── sensor.h                   BLE センサー共通構造体（SensorBase）
    │   ├── thermometer.h/.cpp         SwitchBot 温湿度計パーサー
    │   ├── co2meter.h/.cpp            SwitchBot CO2センサーパーサー
    │   ├── sensor_factory.h/.cpp      センサー種別振り分け（SensorVariant）
    │   ├── sensor_filter.h/.cpp       BLE センサー値のメディアンフィルタ（BLE_MEDIAN_FILTER時のみ）
    │   └── ble_targets.h/.cpp         監視対象 BLE アドレスの NVS 永続化
    └── service/
        ├── mqtt.h/.cpp                MQTT publish / subscribe / pollMqtt（device/lte をトランスポートとして使用）
        ├── https.h/.cpp               HTTPS GET/PUT（AT+SH*）/ ファイルダウンロード（AT+HTTPTOFS）
        ├── ota.h/.cpp                 AWS IoT Jobs 確認・ファームウェア適用・ロールバック管理
        ├── jobs.h/.cpp                AWS IoT Jobs プロトコル層（subscribe / get-next / report）
        ├── command.h/.cpp             Jobs コマンドのディスパッチと実行（ah_reset, charge_main_batt）
        ├── shadow.h/.cpp              Shadow config publish・delta subscribe・設定変更の適用
        ├── monitor.h/.cpp             計測サイクル（measure() / publish()）・MeasureResult 定義
        ├── menu.h/.cpp                OLED + 2ボタン設定メニュー（enterMenuMode() → OperationMode）
        ├── menu_util.h/.cpp           メニュー用パスユーティリティ（pathPush / pathPop / pathTitle 等）
        ├── pubqueue.h/.cpp            オフラインバッファ（RTC メモリ + SPIFFS）・MQTT publish キュー管理
        ├── log_storage.h/.cpp         デバッグログ SPIFFS 保存（起動ごと 1 ファイル、最大 12 ファイル循環）
        └── logger.h/.cpp              シリアルデバッグ出力
└── lib/
    └── uzlib/                         gzip 圧縮・解凍ライブラリ（ESP32-targz 同梱版）
```

## データフロー

```text
ESP32-S3-MINI-1
  → MQTT over TLS（SIM7080G）
  → AWS IoT Core  topic①: sensors/{device_id}/data_bin  （バッテリーテレメトリ + BLE センサー、MessagePack）
                  topic②: $aws/things/{device_id}/shadow/update  （設定値 reported）
  → Topic Rule ingest_bin: SELECT encode(*,'base64') AS payload, topic(2) AS device_id FROM 'sensors/+/data_bin'
    → Lambda ingest（base64 decode → msgpack decode）→ S3: raw/year=YYYY/month=MM/day=DD/hour=HH/{device_id}-{uuid8}.json

クラウド → デバイス
  Shadow desired 更新 → $aws/things/{device_id}/shadow/update/delta → 設定値を NVS に適用
  IoT Jobs → ota.handleJob() / commandHandleJob()
```

## MQTT ペイロード形式

### バッテリーテレメトリ（sensors/{device_id}/data_bin）

**v1.15.0 以降は MessagePack 形式**でトピック `sensors/{device_id}/data_bin` に送信する。
通信経路上のフィールド名は短縮形を使用。`ingest` Lambda が base64 decode → MessagePack decode → キー展開して S3 に保存するため、Glue / Athena / Web 側は変更不要。

実測ペイロードサイズ: **59 bytes**（旧 JSON + フィールド名短縮 ~96 bytes → 約 38% 削減）

フィールド構成（MessagePack map。キーは下記 JSON 表記と同一）:

```json
{"t":"battery","m":12.34,"s":12.10,"i":5.2100,"p":62.500,"tp":28.5,"ah":200.001234,"ts":1746143400}
```

| 通信上のキー | S3 保存キー | 型 | 内容 |
| --- | --- | --- | --- |
| `t` | `type` | string | `"battery"` 固定 |
| `m` | `main` | float | メインバッテリー電圧（V）、ADS1115 ch0（AIN0-AIN1 差動） |
| `s` | `sub` | float | サブバッテリー電圧（V）、ADS1115 ch1（AIN2-AIN3 差動） |
| `i` | `current` | float | サブバッテリー電流（A）、INA228 |
| `p` | `power` | float | サブバッテリー電力（W）、INA228 |
| `tp` | `temp` | float | INA228 内蔵温度センサー（°C） |
| `ah` | `ah` | float | 積算電荷量（Ah）= INA228 積算値 + Ah オフセット（NVS） |
| `ts` | `ts` | int | UNIX タイムスタンプ（秒） |

#### バイナリフレーミング（v1.18.0以降・パケット破損対策）

`sensors/{device_id}/data_bin` の実際の送信バイト列は、上記 MessagePack map をさらに以下でラップする:

```text
[magic 1B: 0xC1][version 1B][MessagePack本体（上記map）][CRC32 4B（little-endian、magic~本体まで）]
```

- **背景**: ESP32↔SIM7080G間のUARTにパリティ・CRCが無く、稀に1ビット化けがそのままクラウドまで届く問題があった。Shadow reportedのキー名が化けて大量蓄積する形で発覚（Shadow設定値は本節で後述の通りJSONテキストのため同種の対策は未実装。破損が疑われる場合はDevice Shadowを一度`delete-thing-shadow`すれば次サイクルで自動再構築される）
- **magic 0xC1**: MessagePack仕様で「未使用」と規定されたバイト値。本体（常にfixmap: `0x80`-`0x8F`始まり）と衝突しないため、`ingest` Lambda はこのバイトの有無だけで新旧フォーマットを自動判別できる（**ファーム/Lambdaのデプロイ順序に依存しない**）
- **旧フォーマット（v1.17.0以前）**: ヘッダ無し、MessagePack本体のみ。`ingest` Lambda は今後も後方互換としてサポートし続ける
- **CRC不一致時**: `raw/`（Athenaスキーマ）には保存せず、生バイナリのまま専用バケット（`corrupted`、30日で自動削除）に退避する。`ingest` Lambda のログに `[CORRUPT]` として理由を出力
- S3保存JSONには検出したフォーマットバージョンを `"ver"`（0=旧形式、1=新形式）として追加する

### 診断テレメトリ（sensors/{device_id}/data_bin、`t:"diag"`）

シリアルにしか出ていなかった「デバイス自身の状態」をクラウドに時系列で残す。データ欠測時に
電源断・再起動ループ（ブラウンアウト/WDT/パニック）・圏外・オフラインキュー溢れを切り分けるのが目的。

- **送信タイミング**: `loop()` の1サイクルにつき1回（DEEP_SLEEPなら起床ごと、CONTINUOUSなら5分境界ごと）。バッテリーテレメトリの直後に `publishDiagnostics()`（`service/diagnostics.cpp`）がオフラインキューへ積む
- **専用トピックを作らない理由**: 既存の `data_bin` に載せればCRC検証・圏外時のSPIFFS退避・IoTポリシー/ルールをそのまま使える。`ingest` は `type` を問わず `raw/` に保存し、query/battery_rollup 等の下流は `type` で絞っているため混在しても影響しない
- **オフラインキュー容量**: 1サイクルあたりのエントリが1件増えるため、圏外時にバッテリー/BLEデータを保持できるサイクル数はその分減る（`OFFLINE_BUFFER_MAX`=200件共有）
- **`/buffer.bin` 互換**: `DiagData` は `QueueEntry` union にそのまま載る。`BatteryEntry`（28バイト）を超えると保存形式が変わるため、`pubqueue.h` の `static_assert` で縛っている

```json
{"t":"diag","ts":1746143400,"rr":1,"wc":4,"bc":12,"up":35,"hf":151234,"hm":120456,"csq":18,"ql":2,"qd":0,"md":"DEEP_SLEEP","fw":"2.3.0+abc1234"}
```

| 通信上のキー | S3 保存キー | 型 | 内容 |
| --- | --- | --- | --- |
| `t` | `type` | string | `"diag"` 固定 |
| `ts` | `ts` | int | UNIX タイムスタンプ（秒） |
| `rr` | `reset_reason` | int | `esp_reset_reason()`。1=POWERON, 3=SW, 4=PANIC, 5=INT_WDT, 6=TASK_WDT, 7=WDT, 8=DEEPSLEEP, 9=BROWNOUT |
| `wc` | `wakeup_cause` | int | `esp_sleep_get_wakeup_cause()`。0=UNDEFINED（DeepSleep以外からの起動）, 4=TIMER 等 |
| `bc` | `boot_count` | int | 起動回数（RTCメモリ保持。電源投入・ブラウンアウト等でリセット）。LIGHT_SLEEPの短周期ピークは数えない |
| `up` | `uptime` | int | 起動からの経過秒（DeepSleep運用では1サイクルの所要時間に相当） |
| `hf` | `heap_free` | int | 空きヒープ（バイト） |
| `hm` | `heap_min` | int | 起動以降の空きヒープ最小値（バイト） |
| `csq` | `csq` | int | AT+CSQ（0〜31、99=不明/取得失敗） |
| `ql` | `queue_len` | int | 計測時点のオフラインキュー滞留件数 |
| `qd` | `queue_dropped` | int | キュー溢れで捨てた件数の累計（RTCメモリ保持、飽和カウンタ） |
| `md` | `mode` | string | 動作モード（`operationModeName()`） |
| `fw` | `fw` | string | ファームウェアバージョン |

### Shadow 設定値（reported / desired）

`$aws/things/{device_id}/shadow/update` に reported として publish する。

```json
{"state":{"reported":{"ah_offset":200,"chg_start_v":11.70,"chg_stop_v":12.50,"chg_min_diff_v":0.30,"debug_log":false,"charging":false,"override_next_mode":null,"continuous_until_time":null,"default_mode":null,"fw_version":"1.25.0+xxxxxxxx"}}}
```

クラウドから desired を設定するとデバイスが次回起動時に delta を受け取り NVS に適用する。

```json
{"state":{"desired":{"ah_offset":200}}}
{"state":{"desired":{"chg_start_v":11.5,"chg_stop_v":12.8}}}
{"state":{"desired":{"chg_min_diff_v":0.5}}}
{"state":{"desired":{"charging":true}}}
{"state":{"desired":{"override_next_mode":"timed_continuous","continuous_until_time":1746143700}}}
```

`override_next_mode: "timed_continuous"` を `continuous_until_time`（継続期限、絶対UNIXタイムスタンプ）と同時に設定すると、次回起動時からその時刻に達するまで CONTINUOUS サイクルを繰り返し、期限到達後に自動で DEEP_SLEEP に戻る（BTN1 長押しでも即座に DEEP_SLEEP へ切り替え可能）。`continuous_until_time` 未指定時はデフォルト30分後。上限は現在時刻から1440分（24時間）後にクランプされる（無期限化を防ぐ安全策）。管理画面では「今から何分後」を入力し、送信時にJS側で絶対時刻へ変換してPUTする。

`continuous_until_time` は `ah_offset` 等と同様に**TIMED_CONTINUOUS中は継続してreportedに反映され続ける**（`shadowPublishConfig()`が呼ばれるたびに現在の期限を送る）ため、管理画面を開き直しても「今設定されている期限」を確認できる。DEEP_SLEEP等TIMED_CONTINUOUS以外のモードになった時点で自動的に`null`が送られる（期限到達・BTN1長押し・BLE切断のいずれの経路でDEEP_SLEEPに戻っても、次にshadow publishされたタイミングでnullになる）。

デバイスが ACK として reported に `"timed_continuous"` を送信したタイミングで desired も自動クリアされる。`override_next_mode` は `setup()` 時にしか反映されない（稼働中の即時切り替えは非対応）。CONTINUOUS/TIMED_CONTINUOUS中も5分サイクルごとにOTA/コマンドJobsを確認するため（`checkAndHandleJob()`、[main.cpp](esp32_iot_gateway/src/main.cpp)参照）、長時間の継続中でもOTAは通常通り届く。

shadow publish はスリープ直前に1回だけ行う（起動時は行わない）。電源断で状態がズレた場合でも次サイクル（最大5分）で補正される。

### Jobs / OTA トピック（service/jobs が使用）

| トピック | 方向 | 用途 |
| --- | --- | --- |
| `$aws/things/{id}/jobs/$next/get` | publish | 次ジョブ取得リクエスト |
| `$aws/things/{id}/jobs/$next/get/accepted` | subscribe | ジョブ取得レスポンス |
| `$aws/things/{id}/jobs/{jobId}/update` | publish | ジョブ状態更新（IN_PROGRESS / SUCCEEDED / FAILED） |
| `$aws/things/{id}/shadow/update/delta` | subscribe | Shadow desired 変更の受信 |

## 主要クラスとインスタンス

| インスタンス | 型 | 役割 |
| --- | --- | --- |
| `lte` | `Lte` | SIM7080G ATコマンド制御・GPRS接続・証明書管理・ファイル読み取り・削除 |
| `mqtt` | `Mqtt` | MQTT publish / subscribe / pollMqtt |
| `https` | `Https` | AT+SH* 経由 HTTPS GET / ダウンロード |
| `ota` | `Ota` | AWS IoT Jobs 確認・FW 適用・ロールバック管理 |
| `bleScanner` | `BleScanner` | BLE スキャン・FreeRTOS キューへの書き込み |
| `blePeripheral` | `BlePeripheral` | BLE Peripheral（計測値 Notify・設定 R/W・Passkey ペアリング） |
| `bleTargets` | `BleTargets` | 監視対象 BLE アドレスの NVS 管理 |
| `button` | `Button` | BTN0/BTN1 デバウンス・長押し検出（`ButtonEvent`）・フィードバック音 |
| `logger` | `Logger` | Serial デバッグ出力（`printf`/`println`） |
| `ina228` | `Ina228` | INA228 I2Cドライバ（電流・電力・温度・積算電荷量の読み取り） |

ドメイン型:

| 型 | 役割 |
| --- | --- |
| `VoltageReading` | 電圧計測値（`float voltage`） |
| `PowerReading` | 電力計測値（`float current, power, temp, ah`） |
| `SensorReading` | アナログ計測値まとめ（`VoltageReading main, sub` + `PowerReading pwr` + `time_t ts`） |
| `MeasureResult` | 1サイクルの全計測結果（`SensorReading reading` + `SensorVariant ble[QUEUE_SIZE]` + `int bleCount`） |
| `ThermometerData` | SwitchBot 温湿度計データ（SensorBase + temp/humidity/battery） |
| `Co2MeterData` | SwitchBot CO2センサーデータ（ThermometerData + co2） |
| `SensorVariant` | `std::variant<ThermometerData, Co2MeterData>` |
| `ITelemetryEncoder` | テレメトリエンコーダ基底クラス（`encodeBattery`/`encodeThermometer`/`encodeCo2`を実装、`serialize`は派生クラスに委譲） |
| `JsonTelemetryEncoder` | JSON形式エンコーダ（トピック`data`） |
| `MsgPackTelemetryEncoder` | MessagePack形式エンコーダ（トピック`data_bin`）。`[magic 0xC1][version][本体][CRC32 4B]`でラップ |

## 重要な設計決定

### INA228 設計ノート

INA228 は VSSOP-10 パッケージ、I2C アドレス `0x40`（A0/A1=GND）。
ADS1115 と同じ I2C バス（SDA=GPIO17, SCL=GPIO18）に並列接続。

**起動時の初期化手順（毎回必須）：**

1. `CONFIG` レジスタを書き込む（ADCRANGE=1 + 変換時間 4120us + 平均化 1024 samples）
2. `SHUNT_CAL` レジスタを書き込む（VS リセットで消えるため DeepSleep 復帰後も必要）

**CONFIG レジスタ設定値：**

| フィールド | 設定値 | 内容 |
| --- | --- | --- |
| ADCRANGE (bit4) | 1 | ±40.96mV 入力レンジ |
| VBUSCT (bits[11:9]) | 0b111 | VBUS 変換時間 4120μs |
| VSHCT (bits[8:6]) | 0b111 | シャント電圧変換時間 4120μs |
| VTCT (bits[5:3]) | 0b111 | 温度変換時間 4120μs |
| AVG (bits[2:0]) | 0b111 | 平均化 1024 サンプル |

**SHUNT_CAL 計算（ADCRANGE=1）：**

```text
R_shunt = 75mV / 200A = 0.375mΩ
CURRENT_LSB = 208μA
SHUNT_CAL = 819.2×10^6 × CURRENT_LSB × R_shunt × 4（ADCRANGE=1 のため×4）
           = 819.2e6 × 208e-6 × 0.375e-3 × 4 ≒ 4096
ADCRANGE=1 → ±40.96mV、フルスケール電流 ±109A (I = V/R_shunt = 40.96mV / 0.375mΩ = 109A)
```

**注意事項：**

- A0/A1 はフローティング禁止（GND/SCL/SDA/VS のいずれかに接続）
- VS ピン直近に 100nF デカップリング必須
- VBUSはIN+と同ノードに接続（PCB上で直結）
- 起動時に CONFIG・SHUNT_CAL を毎回書き込む（電源 OFF でリセット）
- `readCurrent()` は符号反転済み（レジスタの増減方向が直感と逆のため）

詳細（部品比較・シャント設計）: `m5atom_power_adc/HARDWARE.md` の「サブバッテリー電流計測（INA228）」セクション参照。

### OLED ディスプレイ

`device/oled.h/.cpp` に SSD1306 ドライバを実装済み（I2C アドレス `0x3C`、SDA=GPIO17, SCL=GPIO18）。

| 関数 | 用途 |
| --- | --- |
| `oledInit()` | I2C 初期化・画面クリア |
| `oledPrint(text)` | 1行テキスト表示 |
| `oledShowSensorData(SensorReading&)` | 計測値全表示（main/sub/電流/電力/温度） |
| `oledUpdateCountdown(remainSec)` | 計測値画面下部のカウントダウン行のみ部分更新（CONTINUOUS モード用） |
| `oledShowMessage(line1, line2)` | 2行メッセージ表示 |
| `oledShowMenu(title, items, count, cursor)` | スクロール付きメニュー表示 |
| `oledShowConfirm(message, item, cursor)` | Yes/No 確認ダイアログ |
| `oledShowOtaProgress(stage, current, total)` | OTA 進捗バー表示 |

### ADS1115 2 チャンネル読み取り

ch0 = `readADC_Differential_0_1()`（サブバッテリー）、ch1 = `readADC_Differential_2_3()`（メインバッテリー）。
チャンネル切り替え後、変換完了を待ってから読む（`readADC_Differential_X_Y()` はシングルショットのため自動待機）。

分圧比: `22 / (680 + 22) ≒ 0.03134`。変換式: `V = -adcV / DIV_RATIO`（差動測定のため符号反転）。

### LTE 電源スイッチ（LTE_EN）

`setup()` で `LTE_EN=HIGH`（GPIO9）にしてから SIM7080G を起動する。
DeepSleep 前に MQTT/GPRS 切断 → `lte.radioOff()` → `LTE_EN=LOW` の順で電源を落とす。
スリープ中の SIM7080G 消費電流を遮断できる。

### NVS 永続化

`nvs.h` を直接使用。namespace は用途ごとに分離:

| namespace | キー | 用途 |
| --- | --- | --- |
| `"device"` | `mqtt_host`, `board_version`, `debug_log` | MQTT ホスト、基板バージョン（provisioning時に書き込み、`getBoardVersion()`。未設定時は1）、デバッグログ有効フラグ |
| `"lte"` | `cert_crc` | 証明書 CRC |
| `"ota"` | `job_id` | 保留中 OTA ジョブ ID |
| `"battery"` | `ah_offset`, `chg_timeout`, `chg_start_v`, `chg_stop_v`, `chg_min_diff_v` | Ah オフセット、充電タイムアウト（分）、充電開始電圧（V）、充電停止電圧（V）、最小 sub-main 電圧差（V） |
| `"switchbot"` | BLE アドレスキー | 監視対象 BLE デバイス一覧 |

### LTE / MQTT（SIM7080G + AWS IoT Core）

m5atom_iot_gateway と同一設計。以下の注意事項も継承:

- `modem.restart()` は使わず `modem.init()` を使う
- APN 設定は `CFUN=0 → CGDCONT → CFUN=1` の順（必須）
- DeepSleep 前に必ず `lte.disconnect()` → `lte.radioOff()` を呼ぶ

## config.h 定数一覧

| 定数 | 値 | 用途 |
| --- | --- | --- |
| `FIRMWARE_VERSION` | `FIRMWARE_VERSION_BASE "+" GIT_HASH` | ファームウェアバージョン。`FIRMWARE_VERSION_BASE`はBOARD_VERSIONで基板シリーズ別に分岐（1=v1基板、2=v2基板）し、ソースが正。gitタグはCI発火・GitHub Release表示用のみ。詳細は`RELEASE.md`参照 |
| `GIT_HASH` | ビルド時注入（8文字 hex） | `extra_scripts.py` が `-DGIT_HASH` で定義 |
| `OperationMode` | enum class | `DEEP_SLEEP` / `CONTINUOUS` / `TIMED_CONTINUOUS`（動作モード） |
| `SLEEP_INTERVAL_SEC` | `300` | DeepSleep 間隔 / CONTINUOUS モード待機間隔（秒） |
| `CERT_PATH_CA` | `"/certs/ca.crt"` | SPIFFS 上の CA 証明書パス |
| `CERT_PATH_DEVICE` | `"/certs/device.crt"` | SPIFFS 上のデバイス証明書パス |
| `CERT_PATH_KEY` | `"/certs/device.key"` | SPIFFS 上の秘密鍵パス |
| `MQTT_PORT` | `8883` | AWS IoT Core MQTT ポート |
| `SWITCHBOT_COMPANY_ID` | `0x0969` | SwitchBot BLE Manufacturer ID |
| `SCAN_TIME` | `10` | BLE スキャン時間（秒） |
| `QUEUE_SIZE` | `20` | BLE キュー最大サイズ |
| `MAX_TARGETS` | `10` | 監視対象 BLE デバイス最大数 |
| `PAYLOAD_SENSOR_SIZE` | `256` | BLE センサーペイロードバッファ（バイト） |

device/lte.h の定数（ピン番号は `board_pins.h` 経由、下記参照）:

| 定数 | 値 | 用途 |
| --- | --- | --- |
| `APN` | `"soracom.io"` | SORACOM APN |
| `APN_USER` | `"sora"` | SORACOM APN ユーザー |
| `APN_PASS` | `"sora"` | SORACOM APN パスワード |
| `SEND_INTERVAL_SEC` | `60` | デバッグモード送信間隔（秒） |

## board_pins.h / 基板バージョン切り替え

ピン番号は `src/board_pins.h` の `BoardPins` 構造体に集約し、`boardPins()` で取得する（`config.h` と同格で全層から参照可）。
`m5atom_power_adc` の基板バージョン（v1/v2）ごとに `board_pins_v1.h` / `board_pins_v2.h` が実値を持ち、
`board_pins.h` が `BOARD_VERSION`（`platformio.ini` の `build_flags` で指定、未指定時は `1`）に応じて該当ヘッダを `#include` する（選ばれなかった方はコンパイラに一切渡らない）。

| 基板 | gu0x系（未使用） | gu1x系（LTE接続） | Relay0/1/2 | PWR_HOLD | GP2/GP3・GP11/GP12 |
| --- | --- | --- | --- | --- | --- |
| v1 | GPIO4/5/6 | GPIO7/8/9 | GPIO11/13/15 | 非搭載（`PIN_UNUSED`） | 非搭載 |
| v2 | GPIO4/5/6 | GPIO7/8/9 | GPIO13/14/15 | GPIO10 | GPIO2/3・GPIO11/12 |

LTEモジュールは筐体都合で実際には gu1x 系ピン（GPIO7/8/9）に接続されており、回路図上の `LTE_RX`/`LTE_TX`/`LTE_EN` ラベル（IO4-6）とは一致しない。

## ビルド環境

| 項目 | 内容 |
| ---- | ---- |
| IDE | PlatformIO |
| プラットフォーム | espressif32 |
| ボード | esp32-s3-devkitc-1（ESP32-S3-MINI-1 互換） |
| C++ 標準 | C++17（`-std=gnu++17`） |
| env | `esp32-s3-devkitc-1-v1-develop` / `-v2-develop` / `-v1-release` / `-v2-release`（デフォルトは `v2-develop`。release envはOTA配信もv1/v2で別パイプライン、`RELEASE.md`参照） |
| ビルドフック | `extra_scripts.py`（`pre:`）— git hash を `GIT_HASH` マクロとして注入 |
| 主要ライブラリ | TinyGSM, ArduinoJson, Adafruit SSD1306, Adafruit GFX, Adafruit ADS1X15, NimBLE-Arduino, QRCode |

## 作業中・引き継ぎ事項

> 実装済み/対応済みになったTODOは `CONTEXT_ARCHIVE.md` に移動している。

### uzlib 圧縮・解凍 API（実機検証済み）

`lib/uzlib/` に圧縮・解凍両方の実装がある。

#### 解凍（gzip ファイルを展開）

```cpp
#include "../../lib/uzlib/uzlib.h"

static uint8_t dict[32768]; // 32KB スライディングウィンドウ（必須）
static uint8_t out[OUTPUT_SIZE];

TINF_DATA d = {};
d.source       = gzData;
d.source_limit = gzData + gzLen;
d.dest         = out;

uzlib_uncompress_init(&d, dict, sizeof(dict));
if (uzlib_gzip_parse_header(&d) != TINF_OK) { /* エラー */ }

int ret;
do { ret = uzlib_uncompress_chksum(&d); } while (ret == TINF_OK);
if (ret != TINF_DONE) { /* エラー */ }

size_t decompLen = d.dest - out;
```

#### 圧縮（gzip ファイルを生成）

`uzlib_compress` はデータのみ圧縮し、ブロックヘッダ・フッターは書かない。
**必ず `zlib_start_block` → `uzlib_compress` → `zlib_finish_block` の順で呼ぶ。**

```cpp
#include "../../lib/uzlib/uzlib.h"
#include "../../lib/uzlib/defl_static.h"

// 出力バイトを受け取るコールバック（writeDestByte が NULL だと出力が捨てられる）
static uint8_t s_deflateBuf[512];
static uint32_t s_deflateLen = 0;
static unsigned int deflateWriter(struct uzlib_comp *, unsigned char byte) {
    s_deflateBuf[s_deflateLen++] = byte;
    return 0;
}

// ハッシュテーブル（hash_bits=12 → 16KB）
static uzlib_hash_entry_t hashTable[1 << 12];
memset(hashTable, 0, sizeof(hashTable));
s_deflateLen = 0;

struct uzlib_comp comp = {};
comp.writeDestByte = deflateWriter; // 必須
comp.hash_table    = hashTable;
comp.hash_bits     = 12;

zlib_start_block(&comp);               // BFINAL=1, static Huffman ヘッダを書く
uzlib_compress(&comp, data, dataLen);  // LZ77+静的ハフマン圧縮
zlib_finish_block(&comp);             // end-of-block + バイト境界フラッシュ

// s_deflateBuf[0..s_deflateLen-1] に deflate ストリームが入っている
```

#### gzip ファイルの組み立て

```text
[10 bytes] gzip ヘッダ: 1F 8B 08 00 00 00 00 00 00 FF
[N bytes]  deflate ストリーム（上記の出力）
[4 bytes]  CRC32（LE）: uzlib_crc32(data, len, 0xffffffff) ^ 0xffffffff
[4 bytes]  元データサイズ（LE）: sizeof(data)
```

#### 注意事項

- `writeDestByte` が NULL だと出力が **完全に捨てられる**（outbuf に書かれない）
- `grow_buffer=1` にすると outbuf に書かれるが malloc/realloc が必要（組み込みには不向き）
- `zlib_start_block` を省くと BFINAL=0 の非終端ブロックになり、PC の解凍ツールが拒否する
- 0x00-0xFF の非圧縮データはほぼ圧縮できず deflate 出力が入力より大きくなる（正常動作）

---

### TODO: INA228 設定メニューの追加（未着手）

INA228 ドライバを `Ina228` クラスに移行済み（`device/ina228.h/.cpp`）。
今後の機能拡張に備えて、OLED + 2ボタンメニューから INA228 の設定変更を行えるようにする。

**想定する設定項目（未確定）**:

- SHUNT_CAL の手動調整（シャント抵抗値の校正）
- 平均化サンプル数の変更（AVG: 1/4/16/64/128/256/512/1024）
- 変換時間の変更（VBUSCT / VSHCT）
- 積算電荷量のリセット（メニューの `Battery/Ah Reset` から手動実行可能）

**実装方針**:

- `service/menu.cpp` の `MenuState` に `INA228_SETTINGS` を追加
- メインメニューに "INA228 Config" 項目を追加
- 設定値は NVS に永続化する（`config.cpp` の `nvs` 操作パターンに倣う）

### フェーズ 5: リレー・ブザー制御（未着手）

| 機能 | GPIO | 概要 |
| ---- | ---- | ---- |
| リレー制御 × 3 | IO11/IO13/IO15 | NPN BJT（MMBT2222A）ドライバ、HIGH = ON |
| リレーセンシング × 3 | IO10/IO12/IO14 | 外部スイッチ検出、負論理（HIGH = OFF） |
| ブザー | IO35 | AO3401A ハイサイドスイッチ、LEDC PWM 2700Hz、負論理 |

### TODO: BLE ダッシュボード表示器（ESP32-S3側は実装済み・CYD側は未着手）

運転席から視認できる外付けディスプレイに計測値をリアルタイム表示する。ESP32-S3 が BLE Peripheral、外付けディスプレイが BLE Central として動かす。

**現状**: ESP32-S3側のBLE Peripheral（GATT Server）は、当初モバイルアプリ向けに実装済み（`device/ble_peripheral.cpp`）。VoltMain/Curr/Pwr/VoltSub/Temp/Ah/Ts/Lte/Obd の各CharacteristicがNOTIFY対応で、`BlePeripheral::notify()`/`notifyObd()`から計測値を送信できる。この基盤はCYD等のBLE Central側からもそのまま購読可能なはずで、ESP32-S3側の追加実装は原則不要。残っているのはCYD側（BLE Central + TFT描画）のみ。

**ハードウェア候補**:

- **CYD（ESP32-2432S028）**: 2.8インチTFT、ESP32内蔵、~$15、PlatformIO 対応済み。視認性・価格のバランスが良くファーストチョイス
- LilyGO T-Display-S3 AMOLED（2.41インチ）: 輝度・発色が高く直射日光に強い

**表示項目（案）**:

- バッテリー電圧 / 電流 / 電力（INA228 計測値）
- 接続状態（BLE / LTE）

**実装方針（CYD側）**:

- CYD 側: NimBLE で BLE Central（GATT Client）を実装。既存の `device/ble_peripheral.cpp` のMEAS_SERVICE_UUID経由で受信し、TFT に描画
- 既存の LTE / MQTT 処理とは非同期で動作させる（`millis()` ベースで一定周期受信）

### TODO: ULP による低電圧アラート起動（未着手）

ULP RISC-V コプロセッサで DeepSleep 中もバッテリー電圧を監視し、閾値以下になったらメインCPU を起こして LTE でアラートを送信する。

**ハードウェア**:

- Grove コネクタ（GPIO7/GPIO8）に抵抗分圧回路を接続（100k + 27k、12V → 2.55V）
- GPIO7 = ADC1 ch6 → ULP RISC-V から直接読める

**実装方針**:

- `ulp/main.c` に ULP RISC-V コードを追加（C で記述）
- 30秒ごとに ADC1 ch6 を読み取り、閾値以下なら `ulp_riscv_wakeup_main_processor()`
- `platformio.ini` に `board_build.ulp_type = ulp_riscv` を追加
- DeepSleep 移行時に ULP を起動し `esp_sleep_enable_ulp_wakeup()` を設定
- `setup()` の wakeup 判定に `ESP_SLEEP_WAKEUP_ULP` を追加 → 低電圧アラート送信

**閾値（案）**: ADC raw 値 1800 ≈ 11V（要キャリブレーション）

### TODO: corrupted バケットの破損データをCRC32ブルートフォースで訂正（未着手）

これまで観測した破損は一貫して1パケットにつき1ビットだけ反転するパターン（Shadow reportedで化けたキー名も元のキーと1〜2ビットしか違わない）。この特性を利用し、**ファーム変更・ペイロード増量なしで既存のCRC32だけを使った訂正**が可能。

**方式**: `corrupted` バケットに退避された生バイナリ（`raw`）に対し、`raw[:-4]`（magic+version+本体）の全ビット位置を1つずつ反転させて再計算し、末尾4バイトのCRC32と一致する候補を探す。ペイロードは高々500〜700ビット程度なので探索コストは無視できるレベル。候補が一意に一致すれば、CRC32が偶然一致する確率（候補数 × 2^-32 ≈ 10^-7）はほぼゼロなのでその訂正はほぼ確実に正しい。2ビット以上の破損だった場合は一致候補が見つからず、現状通り「訂正不可・`corrupted`に残る」に自然にフォールバックする（誤訂正のリスクなし）。

**実装方針（案）**:

- `ingest` Lambda の `_save_corrupted` 呼び出し箇所（またはオフライン解析スクリプト）に訂正トライを追加
- 既に `corrupted` バケットに溜まっている過去データにも遡って適用可能
- Hamming/Reed-Solomon等の本格的なECCをファームに実装する案もあったが、テレメトリは5分おき送信で1件欠損の実害が小さいこと、実装コスト・新規依存追加のリスクを考えると見合わないため不採用

### TODO: ストリーミング OTA（塩漬け）

現在の OTA は「SIM7080G FS にフル DL してから読み返す」2フェーズ構成。`AT+HTTPREAD` を使ってチャンクを HTTP レスポンスから直接読み出し、解凍→フラッシュ書き込みを同時進行させることで Phase2 の往復を丸ごと削減できる。

**現行 2フェーズの利点（塩漬けの理由）**: DL 完了後に書き込みを開始するため、通信断が起きてもフラッシュは一切汚れない。ストリーミング化すると DL 中断時に `esp_ota_abort()` 処理が必要になりエラーパスが増える。

**実装方針**:

- `service/https.cpp` の download API を廃止し、ストリーミングコールバック API を追加
- `AT+HTTPTOFS` → `AT+HTTPACTION` + `AT+HTTPREAD` に変更し、受信チャンクをそのまま uzlib へ渡す
- SIM7080G の `AT+HTTPREAD` の最大チャンクサイズ（1460 bytes）に合わせてバッファを調整

### TODO: バッテリー上がりアラート（未着手）

**実装方針**: ingest Lambda 内で条件評価 → SNS 通知

MsgPack decode が既に済んだ状態で全フィールドが展開されているため、条件判定を数行追加するだけで実装できる。SNS トピックを追加して通知先（メール等）を繋ぐ。

アラート状態（OK / WARNING / CRITICAL）は **SSM パラメータストア**に保存し、状態変化（OK→ALARM）のときのみ SNS を発火する。条件解消時は回復通知も送る。5分ごとの read/write は月 720 回程度でスタンダードパラメータの無料枠（10,000 回/月）内に収まる（DynamoDB はコストが見合わないため不採用）。

閾値も SSM パラメータストアで管理し、Lambda 環境変数 `ALERT_PROFILE`（`prod` / `test`）でプロファイルを切り替える。

| パラメータ | prod | test（現在の実測値が発火するよう設定） |
| --- | --- | --- |
| `ah_low` | 20 | 195 |
| `ah_high` | 40 | 200 |
| `m_high` | 12.2 | 13.5 |
| `m_low` | 12.0 | 13.0 |

SSM パスの例: `/car-iot/alert/{profile}/ah_low`

**発火条件**:

| 条件 | レベル |
| --- | --- |
| `ah < 20` | 緊急 |
| `ah < 40 AND m < 12.2 AND (s - m) >= 0` | 警告 |
| `m < 12.0 AND (s - m) >= 0` | 緊急 |

- `s - m >= 0`（= B V >= 0）はエンジンOFF状態の判定。エンジンON時はオルタネーター充電でmain電圧が14V台になるため誤検知を防ぐ
- 警告条件（`ah < 40 AND m < 12.2`）は sub・main ともに低下中で緊急充電回路が diff 不足により機能していない可能性がある
- 緊急条件（`m < 12.0`）は充電回路が機能しないまま main が警戒ライン（エンジン始動リスク）に達した状態
- フィールド名は MsgPack キー（`m`=main電圧, `s`=sub電圧, `ah`=サブAh）

**不採用案**:

- Grafana Alerting：アラートチェックのたびに Athena クエリが発行されコストがかかる。Grafana の可用性依存も懸念
- IoT Core ルールエンジン直接評価：MsgPack（バイナリ）を直接パースできないため不可
- EventBridge Scheduler + 専用 Lambda + SNS：柔軟で既存コードと分離できるが、別 Lambda の実装コストがかかる

**背景**: sub（LiFePO4）が深放電に至ると、v1.1.0基板のMOSFETボディダイオード経由でmain（鉛バッテリー）が12Vバスの負荷を供給し続け、mainが上がるリスクがある。梅雨期間の長期曇天でソーラー発電が途絶えた場合に現実的なリスクとなる。

### TODO: OTA中のBLE無効化（IPCタスクスタックオーバーフロー対策・未着手）

現状、OTA（`ota.handleJob()` → `apply()`）中も BLE（`blePeripheral` / `bleScanner`）は動いたまま。`esp_ota_write` によるフラッシュ書き込みとBLEスタックが同時に動くと、ESP32/ESP32-S3で知られる "IPC task has overflowed its stack" の要因になり得る。

[CONTINUOUSモード中はOTAジョブを再チェックしない問題](CONTEXT_ARCHIVE.md#todo-continuousモード中はotaジョブを再チェックしない問題-対応済み)が対応済みになり、`CONTINUOUS`/`TIMED_CONTINUOUS`中も5分サイクルごとにOTAを検知するようになったため、このBLE無効化未対応リスクが顕在化する頻度は以前より上がっている。

**実装方針**:

- `blePeripheral.stop()`（`NimBLEDevice::stopAdvertising()` のみ、`device/ble_peripheral.cpp`）と
  `bleScanner.deinit()`（Peripheral と共存するため no-op、`device/ble_scan.cpp`）は、
  どちらも NimBLE ホストタスク・コントローラ自体は停止しないため、この対策には**使えない**（レビュー指摘済み）
- 実際に BLE スタックを完全停止するには `NimBLEDevice::deinit(true)`（引数 true でコントローラも解放）を呼ぶ必要がある。
  `service/ota.cpp` の `handleJob()` 冒頭（`jobsReport(job.id, "IN_PROGRESS")` 直後あたり）で呼ぶ想定
- `NimBLEDevice::deinit(true)` の後に BLE を再開するには `BleScanner::setup()` 相当
  （`NimBLEDevice::init()` からのアドバタイズコールバック再設定を含む）をやり直す必要がある。
  現状の `setup()` は起動時 1 回のみの呼び出しを想定した作りのため、再入可能にする見直しが必要
- OTA成功時は `esp_restart()` するため再開処理は不要。失敗時に呼び出し元へ処理が戻るケースでBLEを再開すべきか、
  その場合の再初期化方法が検討課題として残る

### v2.0.0 基板 — 電源ボタン＋自己保持回路（ファームウェア側は実装済み、電源断ロジックは未着手）

緊急時（main 電圧が危機的水準に達したとき）に ESP32 から回路全体の電源を完全に断てるよう、次世代基板（v2.0.0）に自己保持回路を追加する。
PWR_HOLD は `board_pins.h`（`BoardPins::pwrHoldPin`、v2 = GPIO10）で管理し、`main.cpp` の `setup()` 冒頭での HIGH アサート・`enterDeepSleepMode()` での `gpio_hold_en()` は実装済み（`BOARD_VERSION == 2` でのみ有効）。
main 電圧低下時に PWR_HOLD を LOW にして能動的に電源を落とす判定ロジックは未実装。

**回路構成（案）**:

```text
Sub(+) 12-13V
  │
  ├────────────────────── FET [S]
  │                            ↓ (P-ch: G が S より低いと ON)
  R1(100k)                FET [D] ── VIN ── [LM2596S] ── 5V ── [ESP32]
  │                                                                  │
  ●─┬─ FET [G]                                         GPIO(PWR_HOLD)
    ├─ NPN [C]                                                       │
    │  NPN [B] ──── R2(10k) ─────────────────────────────────────── ┘
    │  NPN [E] ── GND
    │
    ├─ [電源SW] ── GND
    │
    └─ R3(100Ω) ── C1(47μF) ── GND
```

> ●（ゲートノード）に R1・FET[G]・NPN[C]・電源 SW・R3+C1 が合流する。
> C1 は ● に常時接続することで SW 解放後もゲート上昇を遅延させ（τ = R1×C1 ≈ 5秒）、ESP32 が自己保持を確立するまでの時間を稼ぐ。R3 は SW 押下時に C1 が SW 接点経由で急放電するのを防ぐ電流制限（ピーク 12V/100Ω = 120mA）。
> R1 は通電中ずっと Sub(+)→GND に電流を流す（0.12mA、1.4mW）。完全電源断後はこの電流もゼロになる。

**動作シーケンス**:

```text
【起動】電源SW押下 → ●(Gate) が GND へ → FET ON → VIN供給 → LM2596S → 5V → ESP32起動
        → setup() 冒頭で PWR_HOLD = HIGH → NPN 導通 → Gate を GND に保持（自己保持）
        → SW 離してもゲートは NPN で GND に固定 → FET ON 維持

【停止】PWR_HOLD = LOW → NPN オフ
        → R1 が Gate を Sub(+) へ引き上げ → FET OFF → VIN断 → ESP32停止
        → NPN も自然オフ → 状態維持（発振しない）

【復帰】電源SW押下のみ（手動）
```

> LM2596S の ON/OFF ピン制御は「ESP32が落ちると ON/OFF ピンが GND に戻り再起動する」発振問題があるため不採用。VIN 自体を FET で遮断するこの構成が正しい。

**FET 選定条件**:

| パラメータ | 要件 | 根拠 |
| --- | --- | --- |
| Vgs(max) | **±20V 以上**（または Zener クランプ） | LiFePO4 満充電時 Sub(+) ≈ 14.6V → Vgs = -14.6V。AO3401A の ±12V では破損する |
| Id(cont.) | 1A 以上 | ボード全体のピーク消費：ESP32+SIM7080G TX+リレー ≈ 500mA |
| Rds(on) | 問題にならない | 500mA × 0.1Ω = 50mW 程度。SOT-23 で十分放熱できる |
| パッケージ | SOT-23 可 | 500mA 以下であれば SOT-23 の熱抵抗（500℃/W）でも問題ない |

**候補 A（FET 変更）**: Vgs(max) = ±20V の P-ch FET（例: DMG3415U など）に変える。

**候補 B（AO3401A 流用 + Zener クランプ）**: Gate-Source 間に 12V Zener（BZX84C12 等、SOT-23）を追加して Vgs を -12V に制限する。R1 = 100kΩ のためツェナー電流 ≈ (14.6-12)/100k = 26μA と微小で発熱なし。

**実装上の注意**（`main.cpp` に実装済み）:

- PWR_HOLD は RTC 対応ピン（ESP32-S3: GPIO 0〜21、v2 = GPIO10）を使う。deep sleep 前に `gpio_hold_en()` で HIGH を維持し、起動直後に `gpio_hold_dis()` で解除する（CHG_ON_PIN と同じパターン）
- `digitalWrite(PWR_HOLD_PIN, HIGH)` を `setup()` 冒頭（`delay()` より前）に置き、C1 の遅延時間内に自己保持を確立する

**目的**: DeepSleep では ESP32 の消費はほぼゼロになるが LM2596S は動き続けるため、ボディダイオード経由の電流パスが残る。完全電源断によって 12V バスへの消費を完全に止め、main バッテリーへの影響をゼロにする。

**前提**: アラートが機能すれば main 12V 以下になる前に人が対処できる。この回路はアラートが届かなかった最悪ケースへの安全ネット。製造コスト上の制約から、BJT 化（ボディダイオード解消）と同一ロットで発注する。

### TODO: SIM7080G AT コマンドの書き込み検証（コマンド化け対策・未着手）

参考: [necobit/UWB-module-test の sleep-recovery.md](https://github.com/necobit/UWB-module-test/blob/master/docs/sleep-recovery.md)。
REYAX RYUW122（UWBモジュール）で `AT+MODE=1` を送ったつもりが UART のビット化けで `AT+MODE=2`（スリープ）として受理され、
フラッシュに永続化されて再起動後も無応答（文鎮化したように見える）になった事例。予防策として「読んでから書く（既に正しい値なら書き込みを省略）」
「書いたら `?` 照会で読み戻して検証する」の2点が紹介されている。

`device/lte.cpp` の `Lte::setup()` にある `sendCmd("AT+CSCLK=0")`（[lte.cpp:358](esp32_iot_gateway/src/device/lte.cpp#L358)、スリープ無効化）が同じ構造のリスクを持つ。
`AT+CFUN` や `AT+CGDCONT` は後続の接続確認・SMS Ready 待ちが間接的な検証になっているが、CSCLK には化けを検知する後段のチェックが一切ない。
化けて `AT+CSCLK=1`/`2` のまま通ると、走行中に SIM7080G が勝手にスリープして UART 無応答になり得る（原因究明が難しい）。

**実装方針（案）**:

- `Lte` に検証付き設定用のメソッドを追加（例: `ensureSleepDisabled()`）
- `AT+CSCLK?` で現在値を照会 → 既に `+CSCLK: 0` ならスキップ
- 異なれば `AT+CSCLK=0` を送信 → 再度 `AT+CSCLK?` で読み戻し確認
- 一定回数（例: 3回）試行しても検証できなければログに警告を残す（現状ログのみ、リカバリー動作は未検討）

**スコープ**: 他のコマンド（`AT+CGDCONT` 等）への拡張は、CSCLK での効果を見てから検討する。

### TODO: mobileアプリのrelease署名を専用keystoreに切り替え（未着手）

`mobile/android/app/build.gradle:36-41` の `release` ビルドタイプが `signingConfigs.getByName("debug")` を使っている（`flutter run --release` を通すための暫定対応、コード中のTODOコメント参照）。debugキーストア（`%USERPROFILE%\.android\debug.keystore`）はPCごとに自動生成される使い捨ての鍵のため、別PCでビルドしたAPKは署名が一致せず、端末への上書きインストール時に `INSTALL_FAILED_UPDATE_INCOMPATIBLE` が発生する（現状はflutter/adbが自動でアンインストール→再インストールするため実害はないが、ローカルデータは消える）。

**実装方針（案）**:

- `keytool` で専用のreleaseキーストアを新規作成
- `key.properties`（`.gitignore` 対象、パス・パスワードを記載）を作成し、`build.gradle` の `signingConfigs.release` から参照する構成に変更
- keystoreファイル自体はGitに含めず、USBやパスワードマネージャー等の安全な方法でPC間共有する

### TODO: developビルドでOTA Jobsが「ジョブなし」を返し続けた原因不明のバグ（未解決・原因不明）

2026-08-07、実車（develop ビルド、fw 1.20.0）に対する1.21.0のOTAジョブが、Restartを4回試しても毎回シリアルログに `[JOBS] ジョブなし` を出力して失敗し続けた。同一デバイスに `v1-release` env でビルドしたファームを書き込んだところ、初回起動で即座にジョブを受信し、AWS IoT Jobs側も成功（SUCCEEDED）した。

**確認して除外した原因**:

- AWS側のIoT Jobs Publish/Subscribe用IAMポリシー（`infra/iot.tf`）: `terraform plan` で差分なし、適用済みと確認
- Thing Groupのターゲット対象: ジョブの「ターゲット」一覧にこのデバイスが含まれていることを確認済み
- `getDeviceId()`（MACアドレスから `esp32-gw-{mac}` を生成、`config.cpp:17-28`）: 決定的な処理で develop/release 間で値が変わる要素がない
- `DEBUG_MODE` マクロ: `main.cpp:59-63` の動作モード初期値以外どこにも影響しないことを確認済み（`jobsGetNext()`/`mqtt.cpp`/`getDeviceId()`のいずれも参照していない）
- ログが `[JOBS] レスポンスなし`（タイムアウト）ではなく `[JOBS] ジョブなし`（`exec.isNull()`）だったため、MQTT subscribe自体は成功しAWSからの正規応答は受信できていた

**未解決**: develop/releaseのコード差分は実質 `DEBUG_MODE` の有無（Jobs関連コードに無関係と確認済み）と最適化レベル（`-Os`有無、release env）のみで、`jobsGetNext()`自体のロジックは共通。にもかかわらず何が結果を変えたのか特定できていない。「developのまま再度Restartしたら直る可能性」も検証できておらず、develop固有の問題なのか、単なるタイミング/AWS側の一時的な状態だったのかも未確定（後者を裏付ける根拠はなく、憶測に留まる）。

**次にできること**: 次回developビルドで同様の事象が起きたら、`pio device monitor`でログを見ながら同じdevelopビルドのまま複数回Restartして再現するか確認する。再現すれば develop 固有（`-Os`有無等のビルド差）を疑う根拠になる。

### TODO: SPIFFSログ永続化が既知の未解決問題により無効化中（原因未特定・対応は無効化のみ）

`logStorageWrite()`（[log_storage.cpp:98](esp32_iot_gateway/src/service/log_storage.cpp#L98)）の`SPIFFS.open(s_currentPath, FILE_APPEND)`が、`logStorageInit()`で一度`FILE_WRITE`モードで作成・closeした直後から毎回失敗し続ける事象を実機で確認（2026-08-09）。`[E][vfs_api.cpp:301] VFSFileImpl(): fopen(...) failed`がSerialに大量出力される。

**調査結果**: ESP-IDF/arduino-esp32双方のリポジトリに同一症状の未解決issueが複数存在する（[esp-idf#1012](https://github.com/espressif/esp-idf/issues/1012) "File append not working with SPIFFS"、[esp-idf#9915](https://github.com/espressif/esp-idf/issues/9915)、[arduino-esp32#5250](https://github.com/espressif/arduino-esp32/issues/5250)）が、いずれも`Resolution: More info needed`のまま未解決で、根本原因（`spiffs_open()`内部の何が失敗しているか）は特定できていない。`vfs_api.cpp`のソース自体にもappendモード固有の特別扱いは無い。公式SPIFFSドキュメントにはappendモード特有の言及はないが、GC性能・電源断での破損リスク・利用効率75%程度という一般的な脆弱性は明記されている。

**影響範囲（重要）**: この問題により`logStorageWrite()`は事実上ずっと機能しておらず、SPIFFS上のデバッグログファイルへの永続化が全て失敗していた可能性がある。シリアルモニタ接続時は`[E]`ログで気づけるが、実運用中（車載・モニタなし）は完全に不可視。**過去にSPIFFS上のログファイルを根拠にした調査結果があれば信頼できない**（他のTODOでは幸い`pio device monitor`でのシリアル直接確認を使っており、この問題の影響は受けていない）。

**対応**: 原因が未解明のため修正は行わず、ビルドオプションで無効化した。`platformio.ini`の実機4env（v1/v2 × release/develop）に`-D LOG_STORAGE_DISABLED`を追加し、`log_storage.cpp`を`#ifdef LOG_STORAGE_DISABLED`で分岐させて`logStorageInit()`/`logStorageWrite()`/`logStorageClear()`全てをスタブ化した（元の実装は`#else`側にそのまま残してあり、削除していない）。`getDebugLogEnabled()`/Shadowの`debug_log`設定自体は残るが、現状は効果を持たない。原因が判明・修正されたら`platformio.ini`から`LOG_STORAGE_DISABLED`を外すだけで復元できる。

### TODO: LIGHT_SLEEP モードの追加（実装済み・実機未検証）

既存の `OperationMode`（`DEEP_SLEEP` / `CONTINUOUS` / `TIMED_CONTINUOUS`）に加え、CAN応答・BLE接続の有無でCONTINUOUSへの昇格を判定する新モード `LIGHT_SLEEP` を追加した。目的はエンジン始動・スマホ接続をESP32が素早く把握すること。DEEP_SLEEPは変更せず、LIGHT_SLEEPはメニューから手動選択する別モードとして追加した（`Continuous`の隣に`Light Sleep`項目）。

**方式（当初案からの変更点）**: 検討段階ではESP32の light sleep API（`esp_light_sleep_start()`）でCPU/RAMを保持したまま10秒間隔ポーリングする案だったが、以下2点で不採用にした:

- ESP-IDFのautomatic light sleep（`esp_pm_configure()`）はこのプロジェクトの `framework = arduino` では機能しない（[arduino-esp32#2240](https://github.com/espressif/arduino-esp32/issues/2240): プリビルド版コアで`CONFIG_FREERTOS_USE_TICKLESS_IDLE`が無効）
- 手動 `esp_light_sleep_start()` はBLE(NimBLE)稼働中の安全性が文献だけでは確証を持てず、実機ソークテストなしに信頼できない

代わりに、**既にDEEP_SLEEPで実績のある「`esp_deep_sleep_start()`で完全リブート」パターンをそのまま流用し、間隔だけ20秒に短縮する**方式を採用した。LTE・OLED・ADS1115・INA228の初期化はスキップし、CANとBLEだけ初期化して応答/接続を確認する。

**実装**:

- `main.cpp`の`setup()`冒頭（OLED/ADS/INA228/LTEより前）でCAN/BLEを初期化し、`lightSleepShortWakeGate()`（`service/mode_light_sleep.cpp`）を呼ぶ。RTC_DATA_ATTR変数（`s_lightSleepPeeking`/`s_lightSleepBoundaryWake`、deep sleepを跨いで保持）でピーク状態を管理し、検知なし・5分境界未到達ならその場で`esp_deep_sleep_start()`して戻らない（＝それ以降の初期化を毎回スキップ）
- 検知ロジック（BLE接続 or CAN応答）は`DeepSleepModeHandler::beforeRun()`と共通化し、`mode_common.cpp`の`detectContinuousPromotionTrigger()`にまとめた。CAN生存確認は`obdPoll()`の29PID+DID調査ではなく、PID 0x0C単発の軽量版`obdCheckCanAlive()`を使う
- CONTINUOUSへの昇格元（DEEP_SLEEP or LIGHT_SLEEP）を`OperationModeContext::promotedFromMode()`で記録し、復帰先（BLE切断・CAN無応答どちらも）を昇格元へ汎用化した。復帰条件はDEEP_SLEEP起源・LIGHT_SLEEP起源とも同じ「1回無応答/切断で即復帰」
- GPIO hold（v2基板の自己保持回路・充電中のリレー制御ピン）＋起床設定＋`esp_deep_sleep_start()`は`mode_common.cpp`の`enterDeepSleepFor()`に共通化し、`DeepSleepModeHandler::run()`と両方から使う

**実機未検証の項目**: 実際にエンジン始動・BLE接続からの昇格レイテンシ、5分境界での通常サイクルへの復帰、v2基板でのGPIO hold動作、CAN/BLEの20秒間隔リブートに対するハードウェア耐性（MCP2562FDトランシーバー・AO3401A電源スイッチの頻繁な電源断入）。

### TODO: LIGHT_SLEEP昇格時、5分境界を待たずにフル送信が走ってしまう問題（未着手・回避策あり）

LIGHT_SLEEPからCONTINUOUSへ昇格した直後（`lightSleepShortWakeGate()`が検知してフォールスルーした回）は、5分境界を待たずにLTE接続・`measure()`/`publishBattery()`・`shadowPublishConfig()`・OTAチェック等のフル送信が走ってしまう（`secsToNextBoundary()`による境界揃えが効くのはそれ以降のCONTINUOUSサイクルから）。DEEP_SLEEPは5分に1回しか昇格判定をしないため、この「境界からズレる」問題自体がこれまで表面化していなかった。

**回避策（未実装）**: 境界外での昇格時はLTE接続・shadow同期・OTAチェックを伴うフル送信を行わず、ADS1115/INA228/OLED（CAN/BLEは`lightSleepShortWakeGate()`の時点で初期化済み）だけ用意して、`ContinuousModeHandlerBase::onTick()`相当（`obdPoll()` → `blePeripheral.notifyObd()`）とBLE notify（`blePeripheral.notify()`）だけのループにいきなり入る。LTEを一切使わないため、境界に達するまでは「境界を待たない送信」問題自体が発生しない。境界に達した時点で初めてLTE接続・フル送信の通常サイクルに入る。

実装には`ContinuousModeHandlerBase`/`main.cpp`のsetup()フロー周りの構造変更が必要（LTE接続をCONTINUOUS突入と切り離し、境界到達まで遅延させる仕組みが要る）。

### TODO: 電源断をまたいで積算電荷量を引き継ぐ（ah_offset の小数精度対応を含む・未着手）

INA228 の CHARGE レジスタは本体の電源が完全に切れると 0 にリセットされる。送信している
`ah` は `ina228.readCharge() + (float)getAhOffset()` なので（`service/monitor.cpp`・
`service/mode_continuous_base.cpp`）、電源断のあと `ah` は「その時点の ah_offset の値
そのもの」に飛ぶ。クラウド側の `battery_rollup` は隣接行の ah 差分を充放電量とみなす
ため、このジャンプがまるごと偽の充電量・放電量として日次集計に乗る。

**実際に起きた事象（2026-09-20）**: 車載ボードの電源を完全に OFF にしたことで CHARGE が
リセットされ、`ah` が UTC 08:59:55 に 79.178 → 199.999（当時の ah_offset = 200）へ
ジャンプした。その後 UTC 10:20:32 に offset をリセット前の値 79.17813 へ戻そうとしたが、
`ah_offset` は `int32_t` のため 79 として保存され、0.17813 Ah のズレが残った。
S3 の `raw/` 側は該当区間（UTC 08:59:55〜10:15:56 の 19 レコード）の `ah` から 121
（= offset 200 と 79 の差）を引いて系列を連結し、`battery_rollup` を対象日指定で
再実行して復旧済み。元データは
`s3://iot-monitor-369403882068/backup/2026-09-20-ah-fix/` に退避してある。
0.17813 Ah 分は実在のズレなのでそのまま放電量として残した。

**同じレコードの main=0.0618V について（実測値・後から上書き済み）**: UTC 08:59:55 の
レコードは `main` も 0.0618 V になっていたが、これは作業中にメインバッテリーと繋がる
コネクタを外していたための実測値であり、ADS1115 や起動シーケンスの不具合ではない
（分圧前換算で約 1.94 mV = 2 LSB 相当）。同じレコードの `sub` は 13.13 V、INA228 の
`power` / `current` から逆算した電圧も 13.125 V で正常。main（ADS1115 の AIN0/AIN1、
J104）と sub（AIN2/AIN3、J103）は別系統のため食い違って見えていた。
グラフ上のスパイクを消すため、`main` は直後 UTC 09:05:23 の値 12.610074 で上書きした
（書き換え前は `s3://iot-monitor-369403882068/backup/2026-09-20-main-fix/` に退避）。
このため S3 の生データからはコネクタを外していた事実が読み取れなくなっている。
`battery_rollup` は `ah` しか参照しないので日次集計への影響はない。

**対応方針**: 最新の `ah`（= `readCharge() + ah_offset`）を NVS の別キー `last_ah` へ
定期保存し、電源断を検知した起動時にだけ `ah_offset` へ反映する。`ah_offset` を直接
上書きしないのは、(1) メニュー・BLE・Shadow から人が設定した値を自動保存値が潰して
しまう、(2) DeepSleep 復帰では INA228 の電源は入ったままで CHARGE が保持されており、
そこで offset を上書きすると保持分が二重に乗る、の 2 点による。

**電源断の検知条件（AND で取る）**:

- RTC メモリに置いた magic が消えている（`service/pubqueue.cpp` の `RTC_MAGIC` と同じ手法）
- かつ `ina228.readCharge()` が ≈ 0（|CHARGE| < 0.01 Ah 程度）

RTC メモリ単独では不十分。EN pin リセット・ブラウンアウト・WDT でも RTC メモリは
クリアされるが、その場合 INA228 の電源は切れておらず CHARGE は生きている
（`service/pubqueue.cpp` 冒頭コメント参照）。2026-09-20 の実データでも、電源断後の
最初のレコード（UTC 08:59:55）の CHARGE は -0.00076 Ah だった。

**保存頻度と NVS 摩耗**: 送信と同じ 5 分間隔（CONTINUOUS も `secsToNextBoundary()` で
5 分境界に揃っている）で書いて問題ない。ESP-IDF の NVS は 4096 B ページ = ヘッダ 32 B +
エントリ状態ビットマップ 32 B + 126 エントリ × 32 B で、同一キーの更新は追記
（append-only）・旧エントリは erased マークのみ。フラッシュ消去はページが埋まって
コンパクションが走るときだけなので、消去回数 ≒ 書き込み回数 ÷ 126 になる。
5 分ごと（288 回/日）なら 10 年で書き込み 1,051,200 回 → 消去 8,343 回で、典型寿命
10 万消去の 8.3%。nvs パーティションは 0x5000 = 5 ページ（`partitions_two_ota.csv`）
あるため実際はさらに複数セクタへ分散する。
出典: <https://docs.espressif.com/projects/esp-idf/en/stable/esp32/api-reference/storage/nvs_flash.html>

残る誤差は最後の保存から電源断までの最大 5 分ぶん（走行中 -3.3 A なら約 0.28 Ah）。

**あわせて ah_offset に小数精度を持たせる**: 上記の 0.17813 Ah のズレは `ah_offset` が
`int32_t` で整数 Ah 単位しか扱えないことに起因する。`last_ah` を持たせる際に、
`ah_offset` も mAh 単位の `int32_t`（例 `ah_offset_mah`）か、既存の `nvsSetFloat()`
と同じ float ビットパターン保存に変える。既存キーからの移行が必要
（`ah_offset` が残っていたら 1000 倍して新キーへ書き、旧キーを消す）。

**影響する呼び出し元**:

- `service/menu.cpp` の `tickAhOffset()` — 小数第 3 位まで編集できる UI が要る
- `device/ble_peripheral.cpp` の `CfgAhOffsetCb` — characteristic の値の型・バイト長
- `service/shadow.cpp` — Shadow desired の `ah_offset` を float で受ける
- `domain/telemetry.cpp` — `"ah_offset":%d` のフォーマット指定子

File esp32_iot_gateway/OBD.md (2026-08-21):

# OBD-II 統合設計

フェーズ1（実車接続確認・PID スキャン）の結果と、フェーズ2以降の実装設計をまとめる。  
プロトコル詳細・ブレッドボード試験手順は `CAN_REFERENCE.md` を参照。

---

## 実車スキャン結果

**スキャン実施日:** 2026-05-23  
**電源状態:** IGN ON（エンジン未始動）  
**車種:** Honda N-VAN JJ1/JJ2  

**ビットマスク raw 値（getSupportedPidMask で取得）:**

| 問い合わせ PID | 取得マスク | 対象範囲 |
|---|---|---|
| 0x00 | `0xB63CA813` | 0x01〜0x20 |
| 0x20 | `0x9005A011` | 0x21〜0x40 |
| 0x40 | `0x72C08C01` | 0x41〜0x60 |
| 0x60 | `0x07114001` | 0x61〜0x80 |

**Priority 1 スキャン結果:**

| PID | 名称 | 結果 | 値（IGN ON） |
|-----|---|---|---|
| 0x04 | Engine Load | **✓ OK** | 0% |
| 0x05 | Coolant Temp | ✗ 非対応 | — |
| 0x0B | MAP | **✓ OK** | 101 kPa (boost: 0 kPa) |
| 0x0C | RPM | **✓ OK** | 0 rpm |
| 0x0D | Speed | **✓ OK** | 0 km/h |
| 0x11 | Throttle | **✓ OK** | 17% |

**Priority 2 スキャン結果:**

| PID | 名称 | 結果 | 値（IGN ON） |
|-----|---|---|---|
| 0x0A | Fuel Pressure | ✗ 非対応 | — |
| 0x0E | Ignition Adv | **✓ OK** | 0.0° BTDC |
| 0x0F | Intake Temp | ✗ 非対応 | — |
| 0x10 | MAF | ✗ 非対応 | — |
| 0x2F | Fuel Level | ✗ 非対応 | — |
| 0x33 | Baro | **✓ OK** | 101 kPa |
| 0x42 | ECU Voltage | **✓ OK** | 11.692 V |
| 0x5C | Oil Temp | ✗ 非対応 | — |
| 0x5E | Fuel Rate | ✗ 非対応 | — |

**ビットマスクから確認できるその他のサポート PID（未クエリ）:**

| PID | 名称 |
|-----|---|
| 0x06 | Short Term Fuel Trim Bank 1 |
| 0x07 | Long Term Fuel Trim Bank 1 |
| 0x13 | O2 Sensors Present |
| 0x15 | O2 Sensor B1S2 |
| 0x1C | OBD Standards |
| 0x1F | Time Since Engine Start |
| 0x21 | Distance Traveled with MIL On |
| 0x24 | O2 Sensor 1 (Equivalence Ratio / Voltage) |
| 0x2E | Commanded Evap Purge |
| 0x30 | Warm-ups Since Codes Cleared |
| 0x31 | Distance Since Codes Cleared |
| 0x3C | Catalyst Temperature Bank 1 |
| 0x43 | Absolute Load Value |
| 0x44 | Commanded Air-Fuel Equivalence Ratio |
| 0x47 | Absolute Throttle Position B |
| 0x49 | Accelerator Pedal Position D |
| 0x4A | Accelerator Pedal Position E |
| 0x51 | Fuel Type |
| 0x55 | Short-term Secondary O2 Trim |
| 0x56 | Long-term Secondary O2 Trim |

**Priority 3 スキャン結果（0x61〜0x80）:**

Mask[0x60]=0x07114001 （エンジン始動後、949 rpm 時に取得）

| PID | 名称 | 結果 | 値 |
|-----|---|---|---|
| 0x61 | Torque Demand | ✗ 非対応 | — |
| 0x62 | Torque Actual | ✗ 非対応 | — |
| 0x63 | Torque Reference | ✗ 非対応 | — |
| 0x66 | MAF Alt | **✓ OK** | sensors=0x01, MAF1=**1.69 g/s**（アイドル 949 rpm） |
| 0x67 | Coolant Temp Alt | **✓ OK** | sensors=0x03, **S1=72°C**（冷却水）, S2=17°C（外気？） |
| 0x68 | Charge Air Cooler Temp | !! マスク対応だが応答なし（※後述） | — |
| 0x6C | Commanded Throttle Actuator | !! マスク対応だが応答なし | — |
| 0x6E | Boost Ctrl | ✗ 非対応 | — |
| 0x70 | Boost Pressure Control | !! マスク対応だが応答なし | — |
| 0x72 | Turbocharger RPM | !! マスク対応だが応答なし | — |
| 0x7F | Engine Run Time | ✗ 非対応 | — |

**Priority 4 スキャン結果（0x81〜0xA0）:**

Mask[0x80]=0x00000002 → 0x9F のみマスク対応

| PID | 名称 | 結果 | 備考 |
|-----|---|---|---|
| 0x9F | Emission Req | !! マスク対応だが応答なし | — |
| 他全て | — | ✗ 非対応 | — |

**「!! マスク対応だが応答なし」について:**  
Honda ECU が variant 共通のビットマスクを返しているが、この個体（JJ1/JJ2）では実際のデータを持たない PID が含まれている可能性が高い。timeout を延ばしても変わらない可能性がある。

**※0x68について（`CONTEXT_ARCHIVE.md`の「ISO-TPマルチフレーム対応・多PID要求」参照）:** 上記「応答なし」はISO-TP（ISO 15765-2）
マルチフレーム受信未実装が原因と判明。0x68の応答ペイロードは9バイトでSF上限（7バイト）を
超えるため、Flow Control未送信でECUが送信を打ち切っていた。マルチフレーム受信実装後は
`41 68 03 4A 49 00 00 00 00`（Sensor1=34°C, Sensor2=33°C）が取得できることを実車で確認済み。

**確定した取得可能データ一覧（フェーズ2 実装対象・新基板 2026-06-01 実機確認済み）:**

**全29PID実装済み**（`domain/obd.h/.cpp`・`service/obdpoll.cpp`、実装差分は本ドキュメント後半の「domain/obd.h データ構造・デコード関数」参照）。

| PID | 名称 | デコード式 | 備考 |
|-----|---|---|---|
| 0x04 | Engine Load | A×100/255 % | 負荷監視 |
| 0x06 | Short Term Fuel Trim | (A-128)×100/128 % | 空燃比補正（短期） |
| 0x07 | Long Term Fuel Trim | (A-128)×100/128 % | 空燃比補正（長期） |
| 0x0B | MAP | A kPa | ブースト計算のベース |
| 0x0C | RPM | (A×256+B)/4 rpm | 全体制御 |
| 0x0D | Speed | A km/h | — |
| 0x0E | Ignition Timing | A/2-64 °BTDC | — |
| 0x0F | — | — | 非対応 |
| 0x11 | Throttle A | A×100/255 % | — |
| 0x15 | O2 Sensor B1S2 (NB) | A=電圧(A/200 V), B=燃料トリム | — |
| 0x1F | Time Since Engine Start | A×256+B 秒 | — |
| 0x21 | Distance with MIL | A×256+B km | DTC 点灯時走行距離 |
| 0x24 | O2 Sensor 1 (WB) | ratio=(A×256+B)×2/65536, V=(C×256+D)×8/65536 | ワイドバンドセンサー |
| 0x2E | Evap Purge | A×100/255 % | — |
| 0x30 | Warmups Since Cleared | A 回 | — |
| 0x31 | Distance Since Cleared | A×256+B km | — |
| 0x33 | Baro | A kPa | ブースト=MAP-Baro |
| 0x3C | Catalyst Temp B1S1 | (A×256+B)/10-40 °C | — |
| 0x42 | ECU Voltage | (A×256+B)/1000 V | — |
| 0x43 | Absolute Load | (A×256+B)×100/255 % | 0x04 の絶対値版 |
| 0x44 | Commanded AFR (Lambda) | (A×256+B)×2/65536 | — |
| 0x47 | Throttle B | A×100/255 % | — |
| 0x49 | Accel Pedal D | A×100/255 % | アクセル物理開度 |
| 0x4A | Accel Pedal E | A×100/255 % | アクセル物理開度 |
| 0x51 | Fuel Type | A (1=ガソリン) | — |
| 0x55 | Sec O2 Trim B1 (ST) | (A-128)×100/128 % | — |
| 0x56 | Sec O2 Trim B1 (LT) | (A-128)×100/128 % | — |
| 0x66 | MAF Alt | (B×256+C)/32 g/s | **燃費推算のソース**（0x10 の代替） |
| 0x67 | Coolant Temp Alt | B-40 °C (Sensor1) | **0x05 の代替** |
| 0x68 | Charge Air Cooler Temp | B-40 / C-40 °C (Sensor1/2) | 吸気温。ISO-TPマルチフレーム必須。IC前後どちらがSensor1/2かは未確定 |

燃費推算: `fuelRateLph = mafGs / (14.7 × λ × 0.745) × 3.6`（λ=commandedAfr、0.5〜2.0の範囲外はλ=1固定）

---

## プロトコル確認事項（実車で確認済み）

### 1. 29ビット拡張アドレッシングが必須

Honda N-VAN は標準の 11ビット OBD-II アドレス（0x7DF）に応答しない。  
29ビット SAE J1939 形式を使う必要がある。

| 項目 | 値 |
|---|---|
| リクエスト CAN ID | `0x18DB33F1`（extd=1, functional addressing） |
| 応答 CAN ID | `0x18DAF10E`（extd=1, Honda エンジン ECU = アドレス 0x0E） |
| ビットレート | 500 kbps |

### 2. 11ビットアドレッシングは無応答

`0x7DF` 機能的アドレッシングは TX 自体は成功（car が CAN レベルでは ACK する）するが、  
OBD-II 応答フレームは一切来ない（確認済み）。

### 3. IGN ON が必須

| 電源状態 | 動作 |
|---|---|
| 電源 OFF / ロック | CAN ゲートウェイが起きない。TX エラーカウンタが急増（bus_err が数秒で数万件）。RX は一切得られない |
| **IGN ON（エンジン未始動）** | **通信安定。全 PID への応答あり（RPM=0、速度=0）。スキャンに最適** |
| エンジン始動後 | 実測値が取得可能 |

### 4. 取得できないデータの代替手段

冷却水温（0x05）・MAF（0x10）・燃料流量（0x5E）・燃料残量（0x2F）・油温（0x5C）は Mode 01 非対応。  
ただし以下の代替で対応済み:

| 非対応 PID | 代替 | 状態 |
| --- | --- | --- |
| 0x05 Coolant Temp | 0x67 Sensor1 (B-40°C) | **取得可能・確認済み** |
| 0x10 MAF | 0x66 MAF Alt ((B×256+C)/32 g/s) | **取得可能・確認済み** |
| 0x5E Fuel Rate | 0x66 から推算: `mafGs/(14.7×λ×0.745)×3.6` | **推算で対応** |
| 0x2F Fuel Level | Mode 22 探索が必要 | 未対応 |
| 0x5C Oil Temp | Mode 22 探索が必要 | 未対応 |

Mode 22（Honda 独自拡張）で燃料残量・油温を取得できる可能性があるが未確認。フェーズ2では Mode 01 で取得できる値のみを実装する。

### Mode 22 実機テスト候補

Mode 22 は UDS（ISO 14229）サービス 0x22（ReadDataByIdentifier）。  
リクエスト: `03 22 [DID_HI] [DID_LO] 00 00 00 00`  
正常レスポンス先頭: `04 62 [DID_HI] [DID_LO] [VALUE]`  
否定レスポンス: `03 7F 22 31`（NRC=0x31 = DID 非サポート）

**アドレッシングは物理宛てに切り替える**: Mode 01 が使う `0x18DB33F1`（機能アドレッシング＝
ブロードキャスト）はどの ECU が応答するか不明な探索に向くが、UDS サービス（ReadDataByIdentifier
含む）は機能アドレッシングに応答しない ECU 実装が多い。エンジン ECU のアドレスは応答 ID から
`0x0E` と判明済みのため、Mode 22 リクエストは物理アドレッシング `0x18DA0EF1`
（`0x18DA` | 対象ECU`0x0E` | 送信元`0xF1`）を使うのが定石。応答 ID は変わらず
`0x18DAF10E`（`can.cpp` の `CAN_RESP_MASK`/FC 宛先組み立てと同じ形）。

| DID | データ | デコード式（暫定） | 優先度 | 状態 |
| --- | --- | --- | --- | ---- |
| `0x2201` | ATF 温度 | byte27(AA) - 40 [°C] | 高 | **実装済み・実車未テスト**（`domain/obd.cpp` の `obdDecodeAtfTemp()`、`obdPoll()` から常時問い合わせ） |
| 未確定 | 燃料残量 | 不明 | 高 | DID スキャン要 |
| 未確定 | 油温 | 不明 | 中 | DID スキャン要 |

**DID スキャン機能（実装済み・全域一括スキャンに簡略化済み）**: `service/diddscan.h/.cpp` に `didScanRun()`
を実装。指定範囲を `22XXYY` で総当たりし、正常応答（`62`）と NRC `0x22`/`0x33`（存在するが今は読めない／
認証必要）のみを記録する（`0x31` 非対応・タイムアウトは件数カウントのみ）。OLED メニュー「OBD > DID Scan」
選択で即座に全域 `0x0000`〜`0xFFFF` を一括スキャンする（プリセット範囲選択メニューは全域スキャンを既に
完走済みのため2026-08-20に廃止、`kDidScanPresets[]`・`DidScanPreset`・`DID_SCAN_SELECT`状態も削除した）。
スキャン中は BTN1 長押しで中断可能。正常応答（OK）のみシリアルログに出力し、NRC ヒットはログに出さない
（OLED上のヒット一覧には引き続き両方表示する）。  
燃料補給前後・冷間/暖機後でデータが変化する DID を絞り込む運用は今後の課題（差分比較の自動化は未実装）。

---

## フェーズ1.5: 生 CAN 探索（完了・OBD-II ポートでは不可と判明）

**OBD-II（Mode 01/22）では公開されないデータが F-CAN バス上を流れている可能性がある。**  
フェーズ2 の実装に入る前に LISTEN_ONLY で生フレームを観察し、取得可能なデータを確定させる。

### 目的

- OBD-II 非対応データ（燃料残量・油温・エアコン等）が生フレームで流れているか確認
- 既知 CAN ID（みんカら N-VAN 実測）の存在を確認
- 未知フレームの CAN ID とデータパターンを記録し、将来的なデコードの足がかりにする

### 既知の N-VAN F-CAN フレーム（みんカラ実測、信頼性: 実測）

| CAN ID  | 内容 | デコード（暫定） | 備考 |
|---|---|---|---|
| `0x158` | 車速 | 推定: バイト値 ÷ 定数 | OBD 0x0D と突き合わせで確認可能 |
| `0x1DC` | エンジン RPM | 推定: 2バイト ÷ 定数 | OBD 0x0C と突き合わせで確認可能 |
| `0x324` | 冷却水温 | 推定: `d0 - 40` [°C] | OBD 0x67 と突き合わせで確認可能 |

OBD で既に取れる値と突き合わせることでデコード式を検証できる。

### blank.cpp の変更点

```diff
- #define CAN_MODE TWAI_MODE_NO_ACK
+ #define CAN_MODE TWAI_MODE_LISTEN_ONLY
```

送信ロジック（1秒ごとの TX 部分）を削除し、受信のみにする。  
全フレームをシリアルに出力して観察する。

```cpp
void loop() {
  twai_message_t rx = {};
  if (twai_receive(&rx, pdMS_TO_TICKS(10)) == ESP_OK) {
    Serial.printf("%s id=0x%08lX len=%d  ",
      rx.extd ? "EXT" : "STD", rx.identifier, rx.data_length_code);
    for (int i = 0; i < rx.data_length_code; i++)
      Serial.printf("%02X ", rx.data[i]);
    Serial.println();
  }
}
```

### 確認手順

1. blank env でビルド・書き込み
2. シリアルモニタを開く（115200 bps）
3. 車の IGN ON（エンジン未始動）
4. 出力される CAN ID を記録する
5. エンジン始動・アクセル操作・エアコン ON/OFF などで変化するフレームを観察

### 記録すべき項目

- 観測された CAN ID 一覧（STD/EXT 別）
- 既知 ID（0x158/0x1DC/0x324）の存在確認
- RPM・車速・水温と突き合わせて一致したフレーム
- エアコン・ターボ・燃料系に関係すると思われる変化パターン

### 実施結果（2026-06-01）

**結論: OBD-II ポートでは生 F-CAN トラフィックは観察できない。**

LISTEN_ONLY モードおよびスキャン後の receive-only モードで、アンビエントな CAN フレームはゼロ。
OBD-II ポートは CAN ゲートウェイ経由で診断専用に隔離されており、ECU への OBD リクエスト送信時のみ応答フレームが返ってくる構成。
みんカラ実測の 0x158 / 0x1DC / 0x324 等は OBD-II ポートからは見えない。

**生 F-CAN 観察には OBD-II ポートではなく、車内の F-CAN バス配線に直接タップする必要がある。**

---

## アーキテクチャ統合概要（実装済み）

既存の 3 層構造への追加。依存ルール（device ← domain ← service）を守る。GU0 コネクタ
（GPIO4/5/6）に接続した MCP2562FD 経由で通信する。GU1（GPIO7/8/9）は LTE（SIM7080G）が
使用中のため触らない（当初ドラフトは GU1 想定だったが、実配線確認の結果 GU0 に変更）。

導入当初は専用モード `OperationMode::CONTINUOUS_OBD`（メニュー "Continuous OBD" または Shadow
`override_next_mode: "continuous_obd"` から入る）として実装したが、後日の整理で既存 CONTINUOUS
モードにOBDポーリングが統合された。専用モード・専用メニュー項目・専用Shadow override値は廃止
されており、現在は `CONTINUOUS`（5分境界待機ループ・BLE notify）に入れば自動でOBDポーリングも
1秒間隔で動作する。

```
config.h               変更  （導入時のみ）OperationMode に CONTINUOUS_OBD を追加、後日 CONTINUOUS に統合され廃止
device/can.h/.cpp      新規  TWAI ラッパー（GPIO4=RX, GPIO5=TX, GPIO6=EN, 500kbps）
domain/obd.h/.cpp      新規  OBDReading 構造体・PID デコード関数
service/obdpoll.h/.cpp 新規  全PID逐次ポーリング（canInit()済み前提）
device/oled.h/.cpp     変更  oledShowObdData() を追加（1画面）
main.cpp               変更  setOperationMode() でモード遷移集約・CAN init/deinit・1秒間隔ポーリング
```

**今回のスコープ: OBD 取得データは AWS へ publish しない。** ログ出力（`logger.printf()`）と
OLED 表示にのみ使う。`domain/telemetry.h/.cpp` ・ `service/pubqueue.h/.cpp` は変更していない。
AWS への送信方法（既存パイプライン統合が妥当か等）は別途検討する。

---
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

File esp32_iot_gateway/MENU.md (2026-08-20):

# メニュー画面 実装仕様

OLED と 2 ボタンで操作できる設定メニュー。主目的は BLE 機器の登録・削除。**実装済み。**

---

## ハードウェア前提

| 項目 | 内容 |
|---|---|
| OLED | SSD1306 128×64（I2C 0x3C）、`device/oled.h/.cpp` |
| BTN0 | GPIO26、INPUT_PULLUP、LOW = 押下 |
| BTN1 | GPIO33、INPUT_PULLUP、LOW = 押下 |
| ブザー | GPIO34、負論理（HIGH = 無音）、`device/speaker.h/.cpp` |
| BLE 登録先 | `BleTargets`（NVS、最大 `MAX_TARGETS=10` 件）|

---

## ボタン UX

| ボタン | 短押し（< 1s） | 長押し（≥ 1s） |
|---|---|---|
| BTN0 | カーソル移動（下へ） | — |
| BTN1 | 決定 / 選択 | 戻る / キャンセル |

`device/button.h/.cpp` の `Button` クラスが `millis()` ベースで判定する。
`button.begin()` は `setup()` 内で呼ぶ（ピン設定も内部で行う）。

---
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

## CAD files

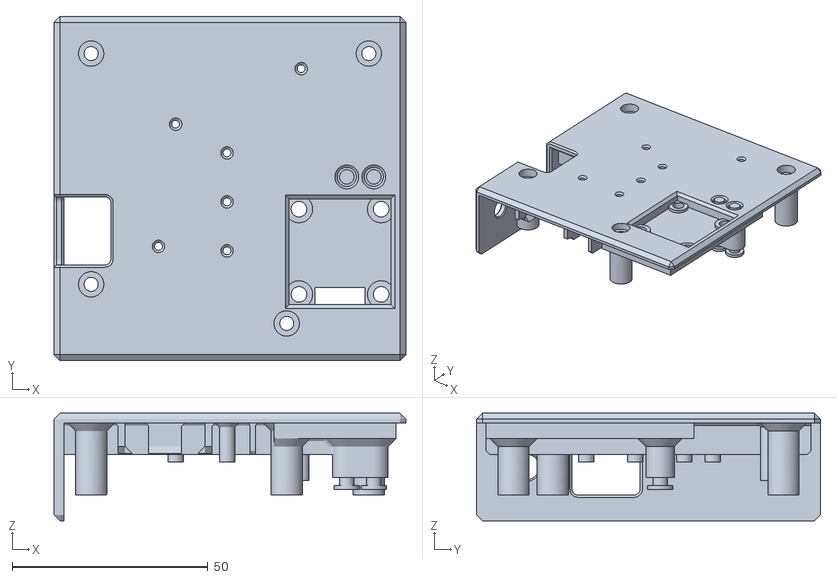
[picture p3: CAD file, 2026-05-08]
case/esp32_case_top.stl
90.0 x 88.0 x 27.5

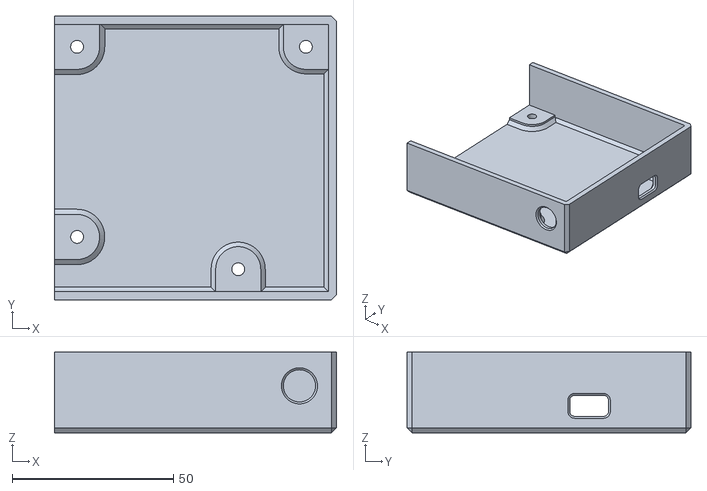
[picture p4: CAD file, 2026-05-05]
case/esp32_case_base.stl
87.5 x 88.0 x 25.0

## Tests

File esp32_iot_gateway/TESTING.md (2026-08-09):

# テスト

## 対象範囲

`domain/` 層（ハードウェア・ネットワークに依存しない純粋ロジック、詳細は [ARCHITECTURE.md](ARCHITECTURE.md)）のみを、PlatformIOの `native` platform でホストPC上でユニットテストする。

`device/` / `service/` 層は Arduino/ESP-IDF API（`Wire`, `SerialAT`, NimBLE等）に直接依存しており、モック化しないとホスト上では動かせないためテスト対象外。実機動作の確認は `/pio` スキルでのビルド・書き込みに頼る。

## 実行方法

Windows/WSL いずれにも `native` platform に必要な `gcc`/`g++` が入っていない前提で、Dockerコンテナ内で実行する。

```bash
cd esp32_iot_gateway
docker compose -f docker-compose.test.yml run --rm test
```

初回は `build-essential` のインストールとPlatformIOの依存取得が走るため数分かかる。

`native` platform・`tool-scons`・ArduinoJson等のPlatformIOパッケージは`Dockerfile.test`の**イメージビルド時**に`pio pkg install -e native`で先にインストールしている（`~/.platformio`に入るため`/work`へのbind mountの影響を受けない）。そのため`docker compose run --rm test`はコンテナを使い捨てても2回目以降は再ダウンロードが発生しない（`platformio.ini`か`test/lib/`を変更した時だけそのレイヤーが再ビルドされる）。

## CI

`esp32_iot_gateway/src/**`・`test/**`・`platformio.ini`・`Dockerfile.test`・`docker-compose.test.yml` に変更があるPRで [.github/workflows/esp32-tests.yml](../.github/workflows/esp32-tests.yml) が自動実行される（`*.md`等ドキュメントだけの変更では走らない）。失敗するとPRのチェックがREDになる。2つのジョブが並列で動く:

- **native-test**: 本ドキュメントで説明しているdomain層のnativeユニットテスト
- **firmware-build**: 実機向けファームウェアが実際にビルドできるかの確認（`esp32-s3-devkitc-1-v1-release`/`v2-release`を`strategy.matrix`で並列ビルド）。native testは`domain/`層しかカバーできないため、`device/`/`service/`/`main.cpp`のコンパイルエラーはこちらでしか検知できない。releaseのみ対象で、developはreleaseと`-D DEBUG_MODE`程度の差しかないため対象外にしている

GitHub-hosted runnerは毎回まっさらな環境なので、ローカルのDockerイメージキャッシュは引き継がれない。そのため `docker/build-push-action` の `cache-from`/`cache-to: type=gha` でDockerレイヤーをGitHub Actions Cacheに保存・再利用し、`Dockerfile.test`のビルド（`pio pkg install -e native`を含む）が変更されていない限りCI側でも再ダウンロードが起きないようにしている。テストの実行自体は `docker compose` ではなく、ビルド済みイメージに対する `docker run` で行っている（`cache-from type=gha` はbuildx経由のビルドでのみ機能し、`docker compose build` からは使えないため）。

**`type=gha` キャッシュはブランチ（PRのhead ref）ごとにスコープが分かれる**。`pull_request` イベントで書き込まれたキャッシュはそのPRのmerge ref専用で、`main` にも他のPRにも引き継がれない。一方ワークフローは「自分のブランチ」と「デフォルトブランチ（`main`）」のキャッシュは読める。そのため `main` へのpushでもこのワークフローを走らせて `main` 用キャッシュを書いておき、そこから枝分かれする新規PRブランチが初回からキャッシュを継承できるようにしている（このリポジトリはPublicなのでActionsの実行時間は無料・無制限）。

`test/` 配下の各 `test_domain_*/` ディレクトリが個別のテストスイートとしてビルド・実行される（`pio test` が自動収集する）。

## 新しいdomainファイルのテストを追加する

1. `test/test_domain_<name>/test_<name>.cpp` を作成し、Unityで書く（既存ファイルを参考に）
2. `platformio.ini` の `[env:native]` の `build_src_filter` に対象の `.cpp` を追加する

```ini
build_src_filter =
    -<*>
    +<domain/obd.cpp>
    +<domain/foo.cpp>   ; ← 追加
```

**注意**: `test_build_src = true` により、`build_src_filter` で指定した全ファイルが `[env:native]` 内の**全テストスイートに共通で**ビルド・リンクされる。そのため、追加したファイルが未解決のシンボル（実機依存のグローバル関数等）に依存していると、そのファイルを直接使わない他のテストスイートまでリンクエラーになる。

## 実機依存の解決（スタブライブラリ）

`domain/telemetry.cpp` は以下の実機依存を持つが、`test/lib/` 配下にnativeテスト専用のスタブライブラリを置いて解決している（`test/lib/` はPlatformIOが自動でライブラリ探索する場所ではないため、`[env:native]` の `lib_extra_dirs = test/lib` で明示的に指定している）。

| 依存 | 実機側 | スタブ | 備考 |
|---|---|---|---|
| `<esp_rom_crc.h>` | ESP-IDF ROM関数 | `test/lib/rom_crc_stub/` | 標準CRC-32のビット単位実装。実機ROMとのビット一致は未検証。この関数を使う`MsgPackTelemetryEncoder`はテスト対象外にして影響を局所化している |
| `config.h` の設定値ゲッター（`getAhOffset()`等） | NVS実装（`config.cpp`、ESP-IDF依存） | `test/lib/config_stub/` | 固定値+テストから差し替え可能なsetterで代替 |

`<esp_rom_crc.h>` は山括弧includeなのでLDF（ライブラリ依存検出）がヘッダ名から自動的に `test/lib/rom_crc_stub` を見つけるが、`config.h` は相対パスのクォートincludeで既に解決済みのためLDFの自動検出が効かない。そのため `config_stub` は `[env:native]` の `lib_deps` に明示的に加えて強制リンクしている。

同様の実機依存を持つファイルを新たにテスト対象へ加える場合は、この2つと同じパターン（スタブライブラリ化 + 必要なら`lib_deps`へ明示追加）で解決する。

## 対象外にしているdomainファイル

- `sensor_filter.cpp` — `BLE_MEDIAN_FILTER` ビルドフラグ内で完結し `esp_sleep.h`（ESP-IDF）に依存。RTCメモリ経由のスリープ復帰判定を含み、モック投資が大きいため未対応
- `ble_targets.cpp` — `Preferences.h`（ESP32 NVSラッパー）に直接依存。config_stubと同様のスタブ化は可能だが未着手

## ASan / UBSan

`[env:native]` は `-fsanitize=address -fsanitize=undefined` を有効化している。バッファオーバーフロー等はメモリレイアウト次第でASanのスタック赤帯検知に掛からないことがある（`test_domain_thermometer` の off-by-one バグがまさにこのケースだった。構造体末尾のパディング領域に着地したためクラッシュせず、値のズレとしてassertが検知した）。ASanが沈黙していても値のassertは別途書くこと。

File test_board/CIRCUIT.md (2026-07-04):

# m5atom_power_adc 回路詳細

KiCad プロジェクト `m5atom_power_adc.kicad_sch` の回路定数・設計根拠をまとめたドキュメント。

---

## ブロック図

```text
[12V サブバッテリー / J4]
        |
        F1（ポリヒューズ 1.5A）
        |
        D1（SMAJ16A TVS）── GND  ← サージクランプ
        |
     +12V バス ─────────────────────────────────────────────────
        |                  |              |               |
   LM2596S-5           リレー制御      バッテリー電圧測定    リレー出力
   （DC-DC）           Q3/Q4/Q7       R_div 分圧         J7/J8/J10
        |                  |              |
      +5V バス ─────────   RelayXSense   ADS1115
        |       |           R27-R32        |
   FB1（フェライトビーズ）               I2C (SCL/SDA)
        |       |                          |
        |   USB-C J1                  ESP32-S3-MINI-1 (U2)
        |   D_ESD + D7                     |
        |                            GPIO → リレー制御
   U5 AMS1117-3.3（+3.3VA）          GPIO → パワースイッチ
        |                            UART → J3（デバッグ）
   ADS1115（VDD,SDA,SCL）
        |
   U3 AMS1117-3.3（+3.3V）
        |
   ESP32-S3-MINI-1
        |
   パワースイッチ Q1/Q5（AO3401A）
        ├── J2（LTE / SIM7080G）
        └── J9（Grove 2）
```

---

## 電源回路

### 保護回路

| 部品 | 値 | 動作 |
| ---- | -- | ---- |
| F1 | ポリヒューズ 1.5A | 過電流で抵抗増大、自己復帰 |
| D1 | SMAJ16A TVS | クランプ電圧 18.2V（typ）、車サージ吸収。逆接保護なし |

> **変更点**: 旧設計の TVS1（P6KE18A）＋ D1（SB360 逆接保護）から SMAJ16A（TVS のみ）に変更。逆接保護ダイオードは削除。

### LM2596S-5（12V → 5V）

固定 5V 出力品（FB ピンを出力に直結）。

| 定数 | 値 | 備考 |
| ---- | -- | ---- |
| VIN | 12V（8〜40V 動作） | |
| VOUT | 5V | 固定出力品 |
| 動作周波数 | 150kHz | 内部固定 |
| L1 | 68μH / 1.5A | Würth PSPMAA0605H-680M-IGF |
| D2 | SS34 ショットキー 3A/40V | フリーホイールダイオード |
| C1 | 220μF / 35V 電解 | 入力平滑 |
| C2 | 220μF / 10V 電解 | 出力平滑 |
| R15 | 10kΩ | ON/OFF ピン → +12V プルアップ（常時 ON） |
| FB1 | 500mA / 600Ω@100MHz フェライトビーズ | +5V バスとアナログ電源（U5 入力）の分離 |

**設計計算：**

```text
デューティ比:  D = VOUT / VIN = 5/12 ≒ 0.42（42%）
インダクタ電流リップル: ΔIL = (VIN − VOUT) × D / (f × L)
  = (12 − 5) × 0.42 / (150kHz × 68μH) ≒ 0.29A
ピーク電流: Iout(max) + ΔIL/2 ≒ 0.5A + 0.145 ≒ 0.65A（< L1 定格 1.5A ✓）
効率: 約 80%（typ）
```

### USB-C 受電（OR 接続）

| 部品 | 値 | 備考 |
| ---- | -- | ---- |
| J1 | USB_C_Receptacle_USB2.0_14P | USB 2.0、SBU1/SBU2 = NC |
| R2, R3 | 5.1kΩ | CC1/CC2 → GND（UFP = 受電側 識別） |
| D3 | LESD5D5.0CT1G | VBUS-GND 間 TVS 保護 |
| D5, D6 | LESD5D5.0CT1G | USB D−/D+ ESD 保護 |
| D7 | SSL36 ショットキー | VBUS → +5V バスへの OR ダイオード、逆流防止 |

LM2596 出力と USB-C VBUS をショットキー D7 で OR 接続。電圧の高い方が優先的に +5V バスを供給する。

### AMS1117-3.3 × 2

#### U3（デジタル系 +3.3V）

ESP32-S3-MINI-1 へ 3.3V を供給。

| 定数 | 値 | 備考 |
| ---- | -- | ---- |
| VIN | +5V | |
| VOUT | +3.3V | |
| C3 | 100nF | 入力パスコン |
| C4 | 10μF | 出力安定化 |

#### U5（アナログ系 +3.3VA）

ADS1115 専用アナログ電源。FB1 でデジタルノイズを分離した +5V から生成。

| 定数 | 値 | 備考 |
| ---- | -- | ---- |
| VIN | +5V（FB1 経由） | フェライトビーズでスイッチングノイズ除去 |
| VOUT | +3.3VA | ADS1115 VDD、I2C プルアップ（R6/R7）、ALERT プルアップ（R14） |
| C7 | 10μF | 入力デカップリング（FB1 出力側） |
| C8 | 10μF | 出力デカップリング（ADS1115 直近） |
| C9 | 100nF | 出力パスコン |

---

## 電圧測定回路（ADS1115）

ADS1115 は +3.3VA で駆動。I2C プルアップ（R6/R7/R14）も +3.3VA に接続。

### 分圧回路

サブバッテリー（BATT0）とメインバッテリー（BATT1）を各 2 ピンコネクタで接続。バッテリー両端の電圧差を差動測定。

| 定数 | 値 | 備考 |
| ---- | -- | ---- |
| R_upper (R8, R4) | 680kΩ 1% | BATT+側の直列分圧抵抗 |
| R_lower (R9, R5) | 22kΩ 1% | BATT−側の直列抵抗（GND へ） |
| 分圧比 | 22/(680+22) = 0.03134 | |
| ADS1115 ゲイン | GAIN_EIGHT（±0.512V） | |
| 分解能 | 15.625μV/LSB | 16bit、±0.512V 範囲 |
| バッテリー端換算 | 0.498mV/LSB | |

**電圧変換式：**

```text
V_battery = ADC_raw × (0.512 / 32768) / (22 / 702) × 1000  [mV]
           = ADC_raw × 0.498  [mV]
```

**測定範囲：**

| 電池種別 | 電圧範囲 | ADS1115 入力 |
| --- | --- | --- |
| 鉛 12V | 10.5〜14.7V | 0.329〜0.461V |
| LiFePO4 4S | 10.0〜14.6V | 0.313〜0.457V |
| 最大（FSR） | 16.3V | 0.512V |

### AIN 入力保護・フィルタ

各 AIN ピンに直列保護抵抗（100Ω）と RC アンチエイリアシングフィルタを追加。

| 部品 | 接続先 | 備考 |
| ---- | --- | ---- |
| R13（100Ω） | BATT0_P → AIN0 | 直列保護 |
| R12（100Ω） | BATT0_N → AIN1 | 直列保護 |
| R11（100Ω） | BATT1_P → AIN2 | 直列保護 |
| R10（100Ω） | BATT1_N → AIN3 | 直列保護 |
| C10（220nF C0G） | AIN0-AIN1 差動 | 差動ノイズ除去、fc ≈ 7.2kHz |
| C13（220nF C0G） | AIN2-AIN3 差動 | 差動ノイズ除去、fc ≈ 7.2kHz |
| C11, C12（22nF C0G） | AIN1, AIN0 → GNDA | コモンモード除去、fc ≈ 72kHz |
| C14, C15（22nF C0G） | AIN3, AIN2 → GNDA | コモンモード除去、fc ≈ 72kHz |

### ADS1115 設定

| 項目 | 値 |
| ---- | -- |
| I2C アドレス | 0x48（ADDR → GND） |
| ゲイン | GAIN_EIGHT（±0.512V） |
| チャンネル ch0 | AIN0/AIN1 差動（サブバッテリー J5） |
| チャンネル ch1 | AIN2/AIN3 差動（メインバッテリー J6） |
| VDD | +3.3VA（U5 出力） |
| R6, R7 | 10kΩ SDA/SCL プルアップ → +3.3VA |
| R14 | 100kΩ ALERT/RDY プルアップ → +3.3VA |
| ADC_RDY | ESP32 GPIO へ接続（変換完了割り込み） |

---

## リレー制御回路

### NPN BJT ドライバ（Q3/Q4/Q7）

外部リレーコイル（12V / 46mA 以上）を GPIO で駆動。3 チャンネル共通構成。

| 部品 | 値 | 備考 |
| ---- | -- | ---- |
| Q3/Q4/Q7 | MMBT2222A NPN | hFE ≥ 100、Vceo = 40V、SOT-23 |
| R19/R20/R25（ベース） | 1kΩ | ベース電流 Ib = (3.3−0.7)/1k = 2.6mA |
| D11/D12/D17（フライバック） | 1N4148WS | コイル逆起電力吸収 |
| R23/R24/R26（LED 並列） | 5.1kΩ | リレー LED 電流制限 |

**飽和確認：**

```text
Ib = (3.3 − 0.7) / 1kΩ = 2.6mA
Ic（リレーコイル 46mA）
hFE × Ib = 100 × 2.6 = 260mA >> 46mA → 飽和動作 ✓
```

### チャンネル構成

| ch | BJT | ベース R | フライバック D | LED R | リレー出力 J | 外部 SW J |
| -- | --- | --- | --- | ----- | --- | --- |
| 0 | Q3 | R19 | D11 | R23 | J7 | J11 |
| 1 | Q4 | R20 | D12 | R24 | J8 | J12 |
| 2 | Q7 | R25 | D17 | R26 | J10 | J13 |

外部スイッチ（J11/J12/J13）と ESP32 GPIO の OR 動作：

- J11/J12/J13 に手動スイッチを接続するとコレクタを直接プルダウンできる
- ESP32 GPIO と手動スイッチのどちらかが ON であればリレーが駆動

### リレー LED（D15/D16/D18）

リレーコイルと並列に接続。コレクタに引き込まれることで点灯。

```text
+12V ─── リレーコイル ─── Collector
  └──── R(5.1kΩ) + LED ─── Collector  ← コイルと並列
```

```text
If = (12 − Vce_sat − Vf) / 5.1kΩ
   = (12 − 0.2 − 2.1) / 5100 ≈ 1.9mA
```

LED: Würth 150060YS75000（黄、Vf=2.1V typ）

### リレーコイルセンシング（RelayXSense）

外部スイッチによるリレー ON を検出する分圧回路。コレクタノードを監視。

```text
+12V ─── 100kΩ ─── Vsense(GPIO 入力) ─── 27kΩ ─── GND
```

| ch | R_top | R_bottom | センス信号 |
| -- | ----- | --- | --- |
| 0 | R31（100kΩ） | R32（27kΩ） | Relay0Sense |
| 1 | R29（100kΩ） | R30（27kΩ） | Relay1Sense |
| 2 | R27（100kΩ） | R28（27kΩ） | Relay2Sense |

| 状態 | Vsense | GPIO |
| ---- | --- | ---- |
| リレー OFF（Collector 開放） | 12 × 27/127 = **2.55V** | HIGH（VIH = 2.475V ✓） |
| リレー ON（Collector ≈ 0V） | **≈ 0V** | LOW |

**負論理**（HIGH = OFF）。コイル未接続時も 0V になる。

---

## パワースイッチ回路

GU1（J2、筐体都合でLTEモジュール/SIM7080G）と GU0（J9、未使用の予備）への +5V 電源を ESP32 GPIO でスイッチ。2 系統独立。

### 回路構成（AO3401A + MMBT2222A）

```text
+5V ─── AO3401A(S) ── AO3401A(D) ── 負荷
              |
           Gate ── R(100kΩ) ── +5V   ← Gate プルアップ（FET OFF 方向）
              |
           MMBT2222A(C)
           MMBT2222A(B) ── R(1kΩ?) ── ESP32 GPIO（GU1_EN / GU0_EN）
           MMBT2222A(E) → GND
```

| ch | P-MOSFET | NPN | Gate R | 負荷 | GPIO 信号 |
| -- | --- | --- | --- | ---- | --- |
| GU1 | Q1 | Q6 | R18（100kΩ） | J2（GU1、筐体都合でLTE/SIM7080G） | GU1_EN |
| GU0 | Q5 | Q2 | R21（100kΩ） | J9（GU0、未使用の予備） | GU0_EN |

| GPIO | MMBT2222A | AO3401A Gate | FET | 出力 |
| ---- | --- | --- | --- | ---- |
| HIGH | ON | ≈ 0V（Vgs < −Vth） | ON | +5V 出力 |
| LOW | OFF | ≈ +5V（Vgs = 0V） | OFF | 遮断 |

---

## 信号 ESD 保護

外部コネクタへ出る信号ラインに SD03（低容量 TVS ダイオードアレイ）を配置。

| 部品 | 値 | 保護信号 |
| ---- | -- | --- |
| D9 | SD03 | GU1_0（J2 → U2、筐体都合でLTE_RX） |
| D10 | SD03 | GU1_1（U2 → J2、筐体都合でLTE_TX） |
| D13 | SD03 | GU0_1（J9 ↔ U2） |
| D14 | SD03 | GU0_0（J9 ↔ U2） |

---

## 電源 LED（D8）

| 項目 | 値 |
| ---- | -- |
| 供給電圧 | +5V |
| 直列抵抗 R16 | 1kΩ |
| LED | Würth 150060GS75000（緑、Vf=3.2V typ） |
| 動作電流 | (5.0 − 3.2) / 1kΩ = **1.8mA** |

---

## ブート・リセット回路

| 部品 | 信号 | 機能 |
| ---- | ---- | ---- |
| SW1 | GPIO0/BOOT | GND 押下で BOOT モード（ファームウェア書き込み用） |
| SW2 | EN | GND 押下でリセット |
| R1 | 10kΩ | EN プルアップ → +3.3V |
| C5 | 1μF | EN デバウンス RC（fc ≈ 15.9Hz） |

---

## テストポイント

TP1〜TP16（TestPoint_Pad_D1.5mm）を主要信号に配置。デバッグ・電流測定用。

---

## 暗電流（ディープスリープ時）

ESP32-S3-MINI-1 がディープスリープ、パワースイッチで LTE / Grove を遮断した状態。

| 部位 | 電流 | 供給元 | 備考 |
| ---- | ---- | --- | ---- |
| LM2596 Iq | **5mA** | 12V バス | 支配的。ディープスリープ時の主消費源 |
| AMS1117-3.3 U3 Iq | ~5mA | 5V バス | |
| AMS1117-3.3 U5 Iq | ~5mA | 5V バス（FB1 経由） | |
| ESP32-S3 ディープスリープ | ~10μA | 3.3V | |
| ADS1115 スタンバイ | ~0.1μA | 3.3VA | |
| 電源 LED D8 | 1.8mA | 5V | 常時点灯 |
| 分圧回路（R8+R9、R4+R5） | ~17μA × 2 = 34μA | 12V バス | 680k+22k = 702kΩ、12V 時 |
| **合計（12V 換算）** | **≈ 13mA** | | |

12V / 100Ah サブバッテリーで連続放置時：100Ah / 13mA ≈ **320 時間（約 13 日）**で放電。

スリープ電流を下げるには LM2596 の代わりに低 Iq DC-DC への変更、または LDO × 2 のシャットダウンが有効。

---

## コネクタ一覧

| Ref | 種別 | ピン数 | 用途 |
| --- | ---- | --- | ---- |
| J4 | Conn_01x02 | 2 | 12V 電源入力（+BATT/GND） |
| J5 | Conn_01x02 | 2 | サブバッテリー電圧入力（P/N） |
| J6 | Conn_01x02 | 2 | メインバッテリー電圧入力（P/N） |
| J7 | Conn_01x02 | 2 | リレー ch0 出力（+12V/COM） |
| J8 | Conn_01x02 | 2 | リレー ch1 出力（+12V/COM） |
| J10 | Conn_01x02 | 2 | リレー ch2 出力（+12V/COM） |
| J11 | Conn_01x02 | 2 | リレー ch0 外部スイッチ入力 |
| J12 | Conn_01x02 | 2 | リレー ch1 外部スイッチ入力 |
| J13 | Conn_01x02 | 2 | リレー ch2 外部スイッチ入力 |
| J1 | USB_C_Receptacle_USB2.0_14P | 14 | USB-C 5V 受電（補助電源） |
| J2 | GROVE-CONNECTOR | 4 | 基板シルク表記「GU1」。筐体都合でLTEモジュール（SIM7080G）5V/GND/TX/RXを接続（GPIO7/8/9） |
| J9 | GROVE-CONNECTOR | 4 | 基板シルク表記「GU0」。未使用の予備コネクタ（GPIO4/5/6） |
| J3 | Conn_01x04_Pin | 4 | UART デバッグ（TXD0/RXD0/3.3V/GND） |
| J107 | Conn_01x04_Socket | 4 | I2C拡張コネクタ（v2のみ。GP11/GP12 + 3.3V/GND2） |
| J108 | Conn_01x04_Socket | 4 | I2C拡張コネクタ（v2のみ。GP2/GP3 + 3.3V/GND1） |

---

## GPIO ピンアサイン（U103 ESP32-S3-MINI-1）

### m5atom_power_adc v1

> 基板シルクは Grove コネクタを「GU0」「GU1」と表記する（`board_pins.h` の `gu00/gu01/gu0EnPin` = GU0、`gu10/gu11/gu1EnPin` = GU1 に対応）。GU1（J2）は筐体都合でLTEモジュール専用として使われており、GU0（J9）は未使用の予備。

| GPIO | 信号名 | 方向 | 用途 |
| ---- | --- | ---- | ---- |
| IO0 | GPIO0/BOOT | IN | ブートモード切替（LOW でダウンロードモード） |
| IO1 | — | — | NC |
| IO2 | — | — | NC |
| IO3 | — | — | NC |
| IO4 | GU0_0 | IN/OUT | GU0（J9、未使用の予備コネクタ）信号線1 |
| IO5 | GU0_1 | IN/OUT | GU0（J9、未使用の予備コネクタ）信号線2 |
| IO6 | GU0_EN | OUT | GU0（J9）パワースイッチ制御（HIGH = ON） |
| IO7 | GU1_0 | IN | GU1（J2）信号線1。LTE使用時: SIM7080G UART TX → ESP32 RX |
| IO8 | GU1_1 | OUT | GU1（J2）信号線2。LTE使用時: ESP32 TX → SIM7080G UART RX |
| IO9 | GU1_EN | OUT | GU1（J2）パワースイッチ制御。LTE使用時: SIM7080G電源制御（HIGH = ON） |
| IO10 | RelaySense0 | IN | リレー ch0 外部スイッチ検出（負論理、J11） |
| IO11 | Relay0 | OUT | リレー ch0 駆動（HIGH = ON） |
| IO12 | RelaySense1 | IN | リレー ch1 外部スイッチ検出（負論理、J12） |
| IO13 | Relay1 | OUT | リレー ch1 駆動（HIGH = ON） |
| IO14 | RelaySense2 | IN | リレー ch2 外部スイッチ検出（負論理、J13） |
| IO15 | Relay2 | OUT | リレー ch2 駆動（HIGH = ON） |
| IO16 | ADC_READY | IN | ADS1115 ALERT/RDY（変換完了割り込み） |
| IO17 | SDA | IN/OUT | I2C データ（ADS1115） |
| IO18 | SCL | OUT | I2C クロック（ADS1115） |
| IO21 | CHG_ON | OUT | 充電制御 |
| IO26 | Btn0 | IN | ボタン 0 |
| IO33 | Btn1 | IN | ボタン 1 |
| IO34 | SPEAKER | OUT | ブザー / スピーカー |
| IO43 | TXD0 | OUT | UART0 デバッグ出力（J3） |
| IO44 | RXD0 | IN | UART0 デバッグ入力（J3） |

### m5atom_power_adc v2

自己保持回路（PWR_HOLD）とI2C拡張コネクタ（J107/J108）を追加。リレー外部スイッチ検出（RelaySense0/1/2、v1のIO10/12/14）はGPIOでの直接検出を廃止し、削除した（J11/J12/J13コネクタ自体は存置）。

| GPIO | 信号名 | 方向 | 用途 |
| ---- | --- | ---- | ---- |
| IO0 | GPIO0/BOOT | IN | ブートモード切替（LOW でダウンロードモード） |
| IO1 | — | — | NC |
| IO2 | GP2 | IN/OUT | I2C拡張コネクタ（J108）信号線 |
| IO3 | GP3 | IN/OUT | I2C拡張コネクタ（J108）信号線 |
| IO4 | GU0_0 | IN/OUT | GU0（J9、未使用の予備コネクタ）信号線1 |
| IO5 | GU0_1 | IN/OUT | GU0（J9、未使用の予備コネクタ）信号線2 |
| IO6 | GU0_EN | OUT | GU0（J9）パワースイッチ制御（HIGH = ON） |
| IO7 | GU1_0 | IN | GU1（J2）信号線1。LTE使用時: SIM7080G UART TX → ESP32 RX |
| IO8 | GU1_1 | OUT | GU1（J2）信号線2。LTE使用時: ESP32 TX → SIM7080G UART RX |
| IO9 | GU1_EN | OUT | GU1（J2）パワースイッチ制御。LTE使用時: SIM7080G電源制御（HIGH = ON） |
| IO10 | PWR_HOLD | OUT | 自己保持回路の電源保持ピン |
| IO11 | GP11 | IN/OUT | I2C拡張コネクタ（J107）信号線 |
| IO12 | GP12 | IN/OUT | I2C拡張コネクタ（J107）信号線 |
| IO13 | Relay0 | OUT | リレー ch0 駆動（HIGH = ON） |
| IO14 | Relay1 | OUT | リレー ch1 駆動（HIGH = ON） |
| IO15 | Relay2 | OUT | リレー ch2 駆動（HIGH = ON） |
| IO16 | ADC_READY | IN | ADS1115 ALERT/RDY（変換完了割り込み） |
| IO17 | SDA | IN/OUT | I2C データ（ADS1115） |
| IO18 | SCL | OUT | I2C クロック（ADS1115） |
| IO21 | CHG_ON | OUT | 充電制御（v1と同じ） |
| IO26 | Btn0 | IN | ボタン 0（v1と同じ） |
| IO33 | Btn1 | IN | ボタン 1（v1と同じ） |
| IO34 | SPEAKER | OUT | ブザー / スピーカー（v1と同じ） |

### m5atom_iot_gateway（旧基板 / M5Atom S3）

`m5atom_iot_gateway/src/` 内の定義値。

| GPIO | 信号名 | 定義箇所 | 備考 |
| ---- | --- | --- | ---- |
| IO5 | LTE_TX | `infra/lte.h` | G2 → U128 RXD |
| IO6 | LTE_RX | `infra/lte.h` | G1 ← U128 TXD |
| IO41 | BTN | `config.h` | M5Atom S3 ボタン（Active-LOW） |

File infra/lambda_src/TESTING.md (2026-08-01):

# Lambda ユニットテスト

`lambda_src/*/index.py` のユニットテストを、ホストに Python を入れずに Docker で実行する。
S3 依存部分は [moto](https://github.com/getmoto/moto) でモックし、実 AWS には一切繋がない。

## 実行方法

`infra/lambda_src/` ディレクトリで実行する。

```bash
# 全Lambda分のテストを実行（ビルド込み）
docker compose -f docker-compose.test.yml run --build --rm test

# 特定のLambdaだけ実行（pytestへの引数をそのまま渡せる）
docker compose -f docker-compose.test.yml run --build --rm test pytest compact/tests -v
```

`--build` を付けることで、`requirements-test.txt` やソースの変更を毎回反映してから実行する
（pip install 部分は Docker のレイヤーキャッシュが効くので、依存関係が変わらない限り速い）。

## 構成

```text
lambda_src/
├── Dockerfile.test          python3.12-slim（Lambdaランタイムと同じ）+ requirements-test.txt
├── docker-compose.test.yml  docker compose run --build 用の定義
├── requirements-test.txt    pytest / moto[s3] / boto3
├── pytest.ini               --import-mode=importlib（後述）
└── {lambda名}/
    ├── index.py
    └── tests/
        ├── conftest.py       fixtureでmotoモック+index.pyのロードを行う
        └── test_index.py
```

新しい Lambda にテストを追加する場合は、既存の `tests/conftest.py` を1つコピーして
バケット名・環境変数・fixture名を対象の Lambda に合わせて書き換えるのが早い。

## 設計上のポイント（ハマりどころ）

### 1. `index.py` は毎回 `spec_from_file_location` で一意な名前としてロードする

全 Lambda 分のテストが同一 pytest プロセス内で動くため、素朴に `sys.path` を通して
`import index` すると、`sys.modules["index"]` が Lambda 間で衝突し、片方のテストが
別の Lambda の `index.py` を見てしまう（実際に発生した）。

`conftest.py` の fixture では `importlib.util.spec_from_file_location("<lambda名>_index", ...)`
で毎回フレッシュなモジュールオブジェクトとしてロードする。これにより:

- Lambda 間の名前衝突を回避
- `s3 = boto3.client("s3")` のようなモジュールレベルのクライアント生成を、
  `mock_aws()` コンテキストの中で確実に発生させられる（先に一度でも素の状態でロードされて
  `sys.modules` にキャッシュされてしまう心配がない）

### 2. `pytest.ini` で `--import-mode=importlib` を指定する

Lambda ごとに同名の `test_index.py` が並ぶため、pytest のデフォルトの import 方式だと
ファイルパスの違いを無視して同一モジュールとして衝突する
（`import file mismatch` エラーになる）。`__init__.py` を追加してパッケージ化する方法もあるが、
Lambda の zip に不要なファイルが混ざるため、`--import-mode=importlib` で回避している。

### 3. moto の `iot-data`（Device Shadow）は一部未実装

`update_thing_shadow` は moto でサポートされておらず、`get_thing_shadow` も安定して
動かせなかった（admin/status/shadow_guard Lambda で遭遇）。この2つの API を使う箇所は
`mock_aws()` に頼らず、`monkeypatch.setattr(module.iot_data, "get_thing_shadow", ...)` の
ように個別に差し替える。`mock_aws()` 自体は「本物の AWS に誤って繋がらないための安全網」
としてそのまま残す。

### 4. Athena も実 SQL 実行まではモックされない

moto は `start_query_execution` / `get_query_execution` 等の API 呼び出し自体はモックするが、
投げた SQL を実際に実行して結果を返すことはしない。`delete`/`query` Lambda では
`_get_partitions` や `athena.get_query_results` を `monkeypatch` で差し替え、クエリの
**組み立てロジック**（WHERE句・UNION ALLの構成等）と、**結果のパース処理**を分けてテストする。

### 5. `datetime.now()` に依存する関数は `_FrozenDateTime` サブクラスで固定する

`freezegun` 等の追加ライブラリは入れず、次のパターンで十分:

```python
class _FrozenDateTime(datetime):
    @classmethod
    def now(cls, tz=None):
        return datetime(2026, 3, 1, 10, 0, tzinfo=tz)

def test_xxx(module, monkeypatch):
    monkeypatch.setattr(module, "datetime", _FrozenDateTime)
    ...
```

対象モジュールが `from datetime import datetime` で束縛した名前を直接差し替えるので、
モジュール内の `datetime.now(...)` 呼び出し全てに効く。

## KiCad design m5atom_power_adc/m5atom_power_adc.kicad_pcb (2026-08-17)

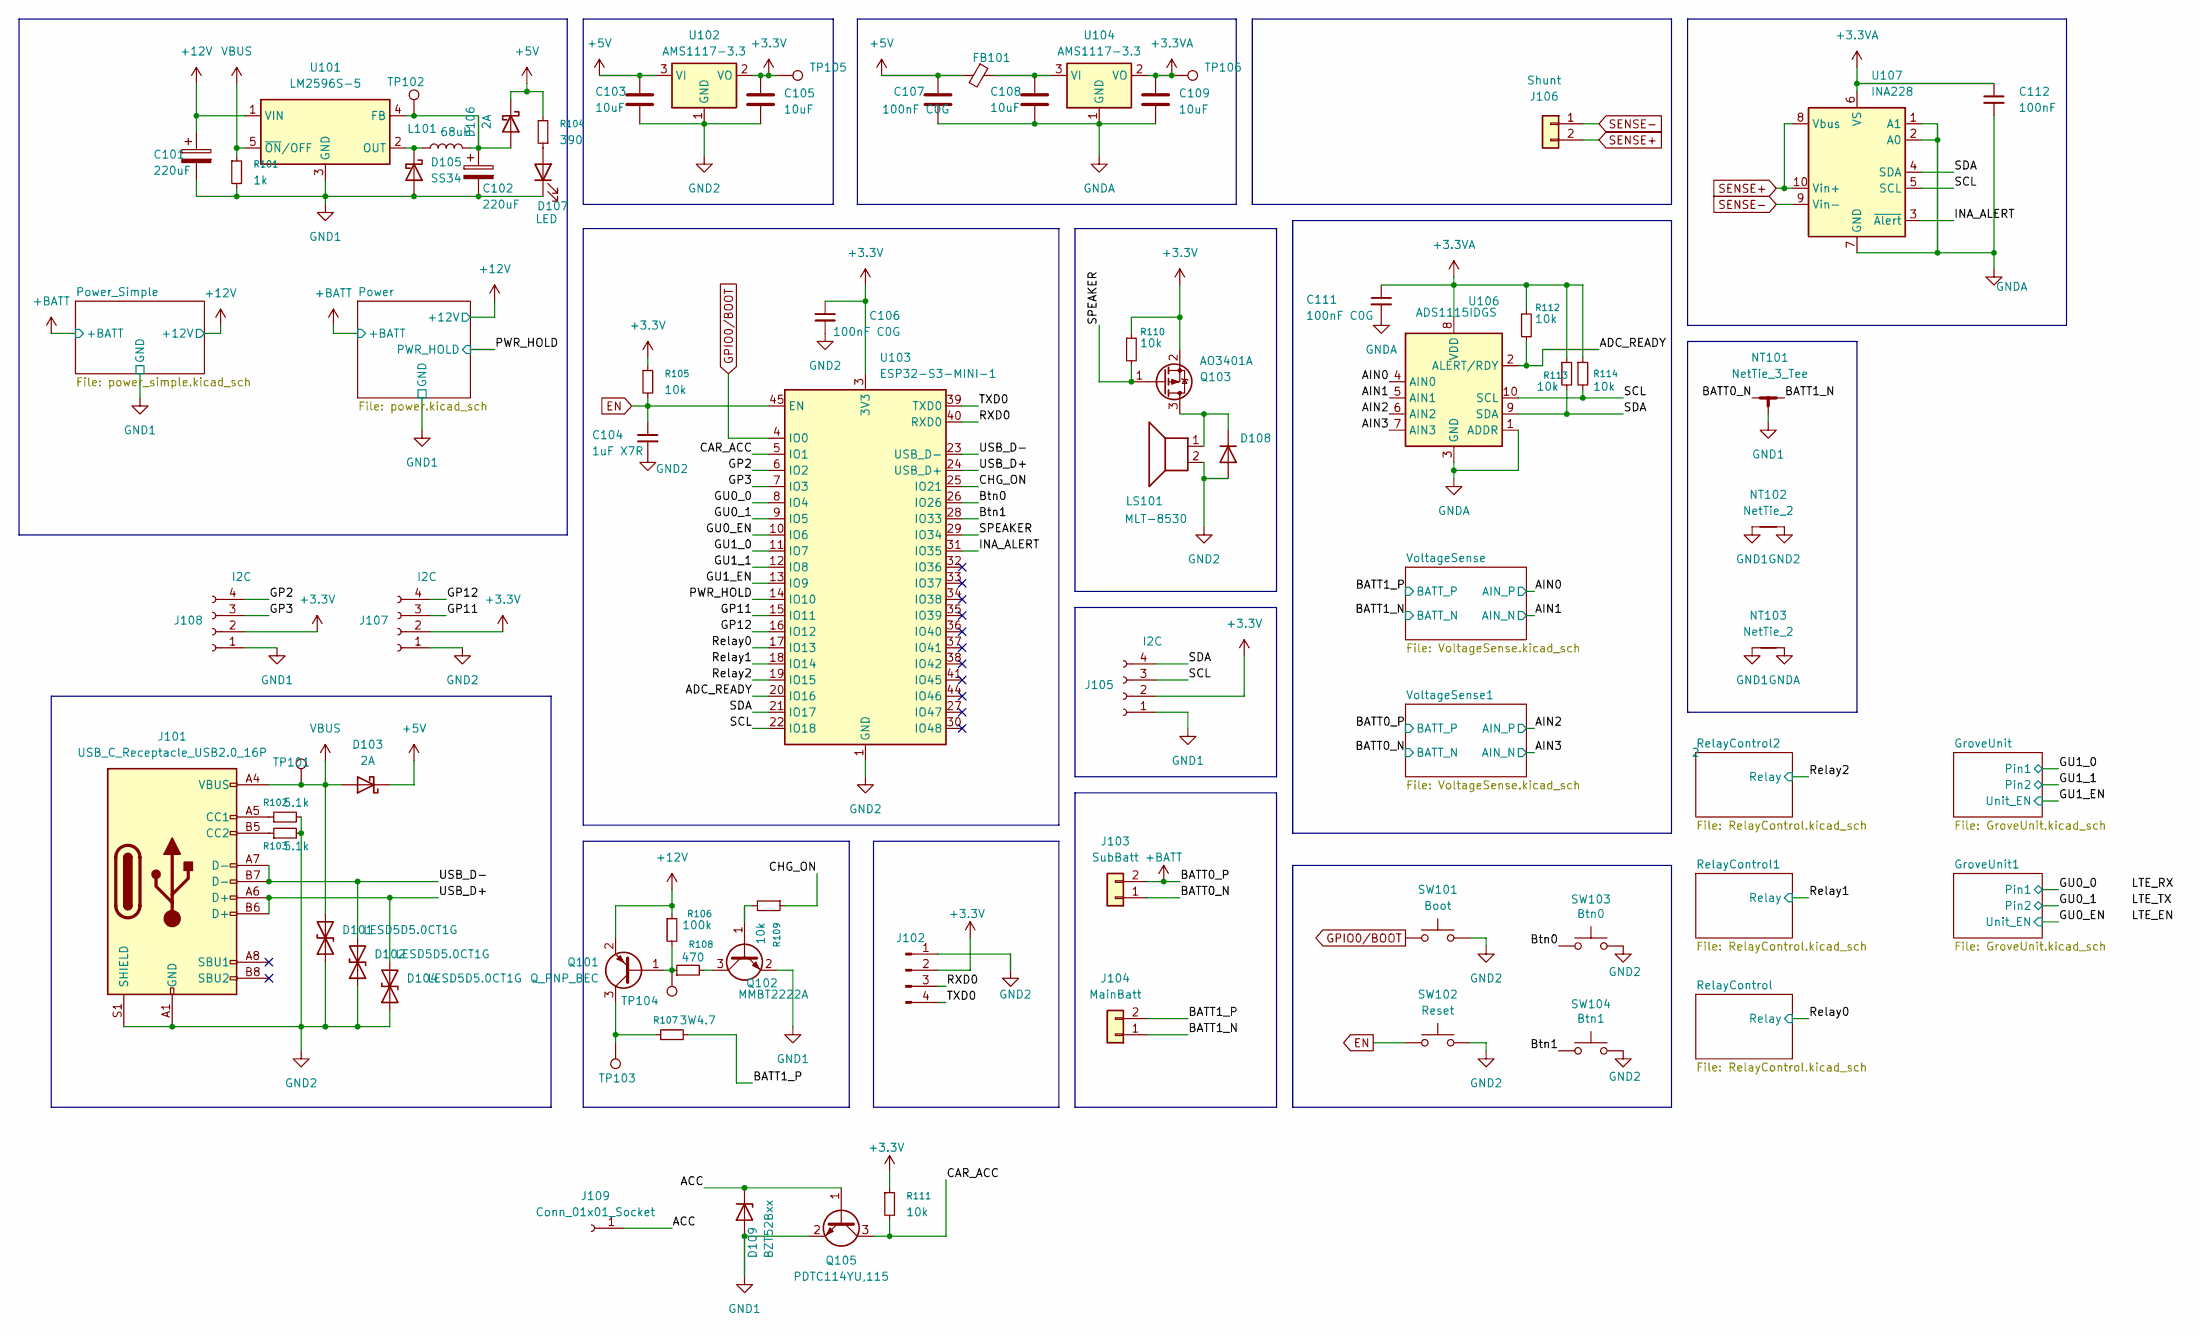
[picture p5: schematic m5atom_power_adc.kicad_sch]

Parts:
C101, C102: 220uF; CP_Elec_10x10; LCSC C125976
C103, C105, C108, C109: 10uF; C_0805_2012Metric; LCSC C32635
C104: 1uF X7R; C_0603_1608Metric; LCSC C5199872
C106, C107, C111: 100nF C0G; C_1206_3216Metric; LCSC C2168319
C112: 100nF; C_0603_1608Metric; LCSC C14663
D101, D102, D104: LESD5D5.0CT1G; D_SOD-523; LCSC C5199850
D103, D106: 2A; D_SOD-123F; LCSC C496544
D105: SS34; D_SMA; LCSC C8678
D107: LED; LED_0603_1608Metric; LCSC C965804
D108: 1N4148WS; D_SOD-323; LCSC C2128
D109: BZT52Bxx; D_SOD-123; LCSC C2932746
FB101: 500mA 600Ω@100MHz; L_0805_2012Metric; LCSC C1017
J101: USB_C_Receptacle_USB2.0_16P; USB_C_Receptacle_HRO_TYPE-C-31-M-12; LCSC C2765186
J102: Conn_01x04_Pin; PinHeader_1x04_P2.54mm_Vertical
J103: SubBatt; JST_XH_B2B-XH-A_1x02_P2.50mm_Vertical; LCSC C158012
J104: MainBatt; JST_XH_B2B-XH-A_1x02_P2.50mm_Vertical; LCSC C158012
J105: I2C; JST_XH_B4B-XH-A_1x04_P2.50mm_Vertical; LCSC C144395
J106: Shunt; JST_XH_B2B-XH-A_1x02_P2.50mm_Vertical; LCSC C158012
J107, J108: I2C; HY2.0-4PZZ; LCSC C144395
J109: Conn_01x01_Socket; PinHeader_1x01_P2.54mm_Vertical
L101: 68uH; PSPMAA0605H-680M-IGF; LCSC C2983094
LS101: MLT-8530; LCSC C94599
NT101: NetTie_3_Tee; NetTie-3_SMD_Pad2.0mm
NT102: NetTie_2; NetTie-2_SMD_Pad2.0mm
NT103: NetTie_2; NetTie-2_SMD_Pad0.5mm
Q101: Q_PNP_BEC; SOT-23; LCSC C7420371
Q102: MMBT2222A; SOT-23; LCSC C8512
Q103: AO3401A; SOT-23; LCSC C15127
Q105: PDTC114YU,115; SOT-323_SC-70; LCSC C80495
R101: 1k; R_0603_1608Metric; LCSC C21190
R102, R103: 5.1k; R_0603_1608Metric; LCSC C23186
R104: 390; R_0603_1608Metric; LCSC C23151
R105, R109, R110, R111, R112, R113, R114: 10k; R_0603_1608Metric; LCSC C25804
R106: 100k; R_0603_1608Metric; LCSC C25803
R107: 3W4.7; R_2512_6332Metric; LCSC C3924519
R108: 470; R_0603_1608Metric; LCSC C25803
SW101: Boot; SW_SPST_PTS810; LCSC C221897
SW102: Reset; SW_SPST_PTS810; LCSC C221897
SW103: Btn0; SW_SPST_PTS810; LCSC C221897
SW104: Btn1; SW_SPST_PTS810; LCSC C221897
TP101, TP102, TP103, TP104, TP105, TP106: TestPoint; TestPoint_Pad_D1.5mm
U101: LM2596S-5; TO-263-5_TabPin3; LCSC C5349985
U102, U104: AMS1117-3.3; SOT-223-3_TabPin2; LCSC C6186
U103: ESP32-S3-MINI-1; ESP32-S2-MINI-1; LCSC C2913206
U106: ADS1115IDGS; VSSOP-10_3x3mm_P0.5mm; LCSC C468683
U107: INA228; VSSOP-10_3x3mm_P0.5mm; LCSC C2887910

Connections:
+3.3V: C105.1, C106.1, J102.2, J105.2, J107.2, J108.2, Q103.2 (S), R105.1, R110.1, R111.1, TP105.1, U102.2 (VO), U103.3 (3V3)
+3.3VA: C109.1, C111.1, C112.1, R112.1, R113.1, R114.1, TP106.1, U104.2 (VO), U106.8 (VDD), U107.6 (VS)
+5V: C103.1, C107.1, D103.1 (K), D106.1 (K), FB101.2, R104.2, U102.3 (VI); also elsewhere on the board
+12V: C101.1, Q101.2 (E), R106.1, U101.1 (VIN); also elsewhere on the board
+BATT: J103.2; also elsewhere on the board
/ACC: D109.1 (K), J109.1, Q105.1 (B)
/ADC_READY: R112.2, U103.20 (IO16), U106.2 (ALERT/RDY)
/AIN0: U106.4 (AIN0); also elsewhere on the board
/AIN1: U106.5 (AIN1); also elsewhere on the board
/AIN2: U106.6 (AIN2); also elsewhere on the board
/AIN3: U106.7 (AIN3); also elsewhere on the board
/BATT0_N: J103.1, NT101.1; also elsewhere on the board
/BATT1_N: J104.1, NT101.2; also elsewhere on the board
/BATT1_P: J104.2, R107.2; also elsewhere on the board
/Btn0: SW103.1, U103.26 (IO26)
/Btn1: SW104.1, U103.28 (IO33)
/CAR_ACC: Q105.3 (C), R111.2, U103.5 (IO1)
/CHG_ON: R109.1, U103.25 (IO21)
/GP2: J108.4, U103.6 (IO2)
/GP3: J108.3, U103.7 (IO3)
/GP11: J107.3, U103.15 (IO11)
/GP12: J107.4, U103.16 (IO12)
/GU0_0: U103.8 (IO4); also elsewhere on the board
/GU0_1: U103.9 (IO5); also elsewhere on the board
/GU0_EN: U103.10 (IO6); also elsewhere on the board
/GU1_0: U103.11 (IO7); also elsewhere on the board
/GU1_1: U103.12 (IO8); also elsewhere on the board
/GU1_EN: U103.13 (IO9); also elsewhere on the board
/INA_ALERT: U103.31 (IO35), U107.3 (~Alert)
/PWR_HOLD: U103.14 (IO10); also elsewhere on the board
/RXD0: J102.3, U103.40 (RXD0)
/Relay0: U103.17 (IO13); also elsewhere on the board
/Relay1: U103.18 (IO14); also elsewhere on the board
/Relay2: U103.19 (IO15); also elsewhere on the board
/SCL: J105.3, R114.2, U103.22 (IO18), U106.10 (SCL), U107.5 (SCL)
/SDA: J105.4, R113.2, U103.21 (IO17), U106.9 (SDA), U107.4 (SDA)
/SPEAKER: Q103.1 (G), R110.2, U103.29 (IO34)
/TXD0: J102.4, U103.39 (TXD0)
/USB_D+: D104.2 (A2), J101.A6 (D+), J101.B6 (D+), U103.24 (USB_D+)
/USB_D-: D102.2 (A2), J101.A7 (D-), J101.B7 (D-), U103.23 (USB_D-)
EN: C104.1, R105.2, SW102.1, U103.45 (EN)
GND1: C101.2, C102.2, D105.2 (A), D107.1 (K), D109.2 (A), J105.1, J108.1, NT101.3, NT102.1, NT103.1, Q102.2 (E), Q105.2 (E), R101.2, U101.3 (GND); also elsewhere on the board
GND2: C103.2, C104.2, C105.2, C106.2, D101.1 (A1), D102.1 (A1), D104.1 (A1), D108.2 (A), J101.A1 (GND), J101.A12 (GND), J101.B1 (GND), J101.B12 (GND), J101.S1 (SHIELD), J102.1, J107.1, LS101.2, NT102.2, R102.2, R103.2, SW101.2, SW102.2, SW103.2, SW104.2, U102.1 (GND), U103.1 (GND), U103.2 (GND), U103.42 (GND), U103.43 (GND), U103.46 (GND), U103.47 (GND), U103.48 (GND), U103.49 (GND), U103.50 (GND), U103.51 (GND), U103.52 (GND), U103.53 (GND), U103.54 (GND), U103.55 (GND), U103.56 (GND), U103.57 (GND), U103.58 (GND), U103.59 (GND), U103.60 (GND), U103.61 (GND), U103.62 (GND), U103.63 (GND), U103.64 (GND), U103.65 (GND)
GNDA: C107.2, C108.2, C109.2, C111.2, C112.2, NT103.2, U104.1 (GND), U106.1 (ADDR), U106.3 (GND), U107.1 (A1), U107.2 (A0), U107.7 (GND); also elsewhere on the board
GPIO0/BOOT: SW101.1, U103.4 (IO0)
unnamed: D105.1 (K), L101.1, U101.2 (OUT)
unnamed: C102.1, D106.2 (A), L101.2, TP102.1, U101.4 (FB)
unnamed: D107.2 (A), R104.1
unnamed: D108.1 (K), LS101.1, Q103.3 (D)
unnamed: J101.A5 (CC1), R102.1
unnamed: J101.B5 (CC2), R103.1
unnamed: Q101.1 (B), R106.2, R108.1, TP104.1
unnamed: Q101.3 (C), R107.1, TP103.1
unnamed: Q102.1 (B), R109.2
unnamed: Q102.3 (C), R108.2
unnamed: C108.1, FB101.1, U104.3 (VI)
SENSE+: J106.2, U107.8 (Vbus), U107.10 (Vin+)
SENSE-: J106.1, U107.9 (Vin-)
VBUS: D101.2 (A2), D103.2 (A), J101.A4 (VBUS), J101.A9 (VBUS), J101.B4 (VBUS), J101.B9 (VBUS), R101.1, TP101.1, U101.5 (~ON/OFF)

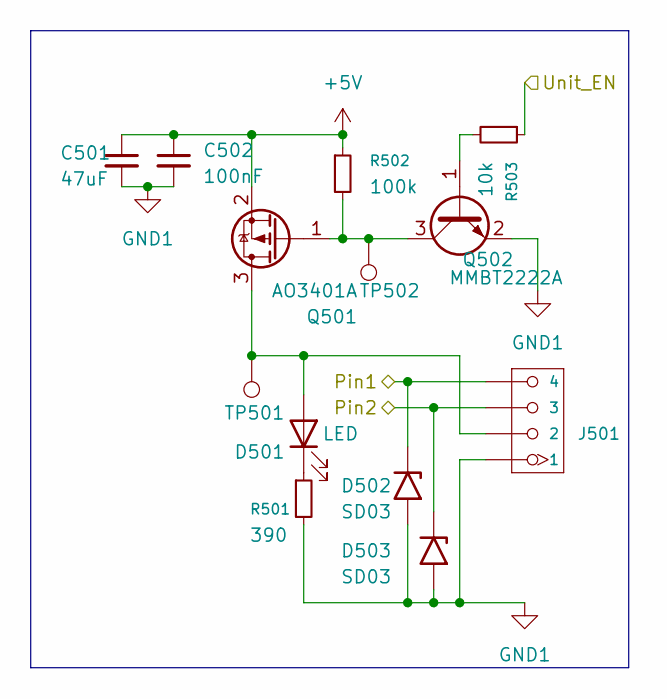
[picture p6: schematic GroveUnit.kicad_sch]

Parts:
C501: 47uF; C_1206_3216Metric; LCSC C22367835
C502: 100nF; C_0603_1608Metric; LCSC C14663
D501: LED; LED_0603_1608Metric; LCSC C965804
D502, D503: SD03; D_SOD-323; LCSC C502526
J501: GROVE-CONNECTOR; HY2.0-4PZZ; LCSC C7429580
Q501: AO3401A; SOT-23; LCSC C15127
Q502: MMBT2222A; SOT-23; LCSC C8512
R501: 390; R_0603_1608Metric; LCSC C23151
R502: 100k; R_0603_1608Metric; LCSC C25803
R503: 10k; R_0603_1608Metric; LCSC C25804
TP501, TP502: TestPoint; TestPoint_Pad_D1.5mm

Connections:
+5V: C501.1, C502.1, Q501.2 (S), R502.1; also elsewhere on the board
/GU1_0: D502.1 (A1), J501.4; also elsewhere on the board
/GU1_1: D503.1 (A1), J501.3; also elsewhere on the board
/GU1_EN: R503.1; also elsewhere on the board
GND1: C501.2, C502.2, D502.2 (A2), D503.2 (A2), J501.1, Q502.2 (E), R501.2; also elsewhere on the board
unnamed: D501.2 (A), J501.2, Q501.3 (D), TP501.1
unnamed: D501.1 (K), R501.1
unnamed: Q501.1 (G), Q502.3 (C), R502.2, TP502.1
unnamed: Q502.1 (B), R503.2

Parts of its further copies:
C601: 47uF; C_1206_3216Metric; LCSC C22367835
C602: 100nF; C_0603_1608Metric; LCSC C14663
D601: LED; LED_0603_1608Metric; LCSC C965804
D602, D603: SD03; D_SOD-323; LCSC C502526
J601: GROVE-CONNECTOR; HY2.0-4PZZ; LCSC C7429580
Q601: AO3401A; SOT-23; LCSC C15127
Q602: MMBT2222A; SOT-23; LCSC C8512
R601: 390; R_0603_1608Metric; LCSC C23151
R602: 100k; R_0603_1608Metric; LCSC C25803
R603: 10k; R_0603_1608Metric; LCSC C25804
TP601, TP602: TestPoint; TestPoint_Pad_D1.5mm

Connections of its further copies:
+5V: C601.1, C602.1, Q601.2 (S), R602.1; also elsewhere on the board
/GU0_0: D602.1 (A1), J601.4; also elsewhere on the board
/GU0_1: D603.1 (A1), J601.3; also elsewhere on the board
/GU0_EN: R603.1; also elsewhere on the board
GND1: C601.2, C602.2, D602.2 (A2), D603.2 (A2), J601.1, Q602.2 (E), R601.2; also elsewhere on the board
unnamed: D601.2 (A), J601.2, Q601.3 (D), TP601.1
unnamed: D601.1 (K), R601.1
unnamed: Q601.1 (G), Q602.3 (C), R602.2, TP602.1
unnamed: Q602.1 (B), R603.2

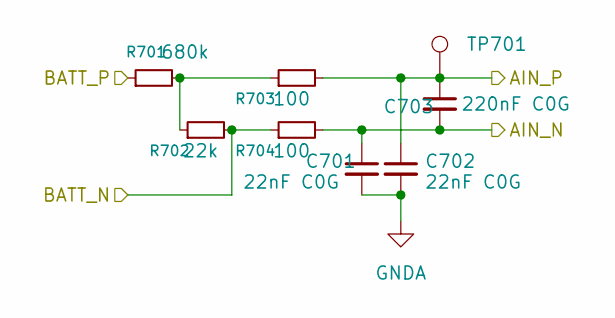
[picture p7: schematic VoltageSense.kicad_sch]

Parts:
C701, C702: 22nF C0G; C_0805_2012Metric; LCSC C77069
C703: 220nF C0G; C_1206_3216Metric; LCSC C464977
R701: 680k; R_0402_1005Metric; LCSC C2909377
R702: 22k; R_0402_1005Metric; LCSC C326601
R703, R704: 100; R_0402_1005Metric; LCSC C705627
TP701: TestPoint; TestPoint_Pad_D1.5mm

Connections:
/AIN0: C702.1, C703.1, R703.2, TP701.1; also elsewhere on the board
/AIN1: C701.1, C703.2, R704.2; also elsewhere on the board
/BATT1_N: R702.2, R704.1; also elsewhere on the board
/BATT1_P: R701.1; also elsewhere on the board
GNDA: C701.2, C702.2; also elsewhere on the board
unnamed: R701.2, R702.1, R703.1

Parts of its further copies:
C801, C802: 22nF C0G; C_0805_2012Metric; LCSC C77069
C803: 220nF C0G; C_1206_3216Metric; LCSC C464977
R801: 680k; R_0402_1005Metric; LCSC C2909377
R802: 22k; R_0402_1005Metric; LCSC C326601
R803, R804: 100; R_0402_1005Metric; LCSC C705627
TP801: TestPoint; TestPoint_Pad_D1.5mm

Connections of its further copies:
+BATT: R801.1; also elsewhere on the board
/AIN2: C802.1, C803.1, R803.2, TP801.1; also elsewhere on the board
/AIN3: C801.1, C803.2, R804.2; also elsewhere on the board
/BATT0_N: R802.2, R804.1; also elsewhere on the board
GNDA: C801.2, C802.2; also elsewhere on the board
unnamed: R801.2, R802.1, R803.1

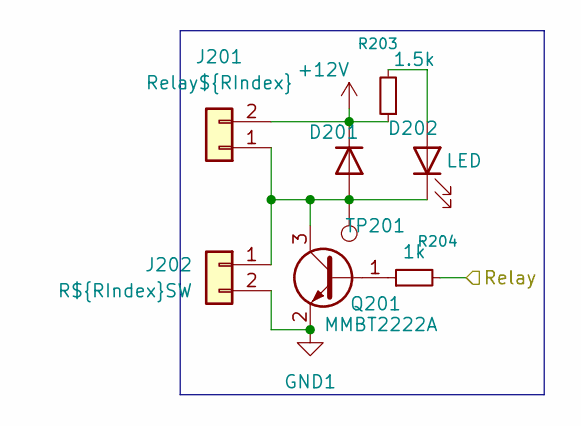
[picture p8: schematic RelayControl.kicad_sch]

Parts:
D201: 1N4148WS; D_SOD-323; LCSC C2128
D202: LED; LED_0603_1608Metric; LCSC C965799
J201: Relay${RIndex}; JST_XH_B2B-XH-A_1x02_P2.50mm_Vertical; LCSC C158012
J202: R${RIndex}SW; JST_XH_B2B-XH-A_1x02_P2.50mm_Vertical; LCSC C158012
Q201: MMBT2222A; SOT-23; LCSC C8512
R203: 1.5k; R_1206_3216Metric; LCSC C114929
R204: 1k; R_0603_1608Metric; LCSC C21190
TP201: TestPoint; TestPoint_Pad_D1.5mm

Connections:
+12V: D201.1 (K), J201.2, R203.1; also elsewhere on the board
/Relay0: R204.2; also elsewhere on the board
GND1: J202.2, Q201.2 (E); also elsewhere on the board
unnamed: D201.2 (A), D202.1 (K), J201.1, J202.1, Q201.3 (C), TP201.1
unnamed: D202.2 (A), R203.2
unnamed: Q201.1 (B), R204.1

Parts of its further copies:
D301, D401: 1N4148WS; D_SOD-323; LCSC C2128
D302, D402: LED; LED_0603_1608Metric; LCSC C965799
Q301, Q401: MMBT2222A; SOT-23; LCSC C8512
R303, R403: 1.5k; R_1206_3216Metric; LCSC C114929
R304, R404: 1k; R_0603_1608Metric; LCSC C21190
TP301, TP401: TestPoint; TestPoint_Pad_D1.5mm

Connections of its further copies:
+12V: D301.1 (K), D401.1 (K), R303.1, R403.1; also elsewhere on the board
/Relay1: R304.2; also elsewhere on the board
/Relay2: R404.2; also elsewhere on the board
GND1: Q301.2 (E), Q401.2 (E); also elsewhere on the board
unnamed 54: D301.2 (A), D302.1 (K), Q301.3 (C), TP301.1; also elsewhere on the board
unnamed: D302.2 (A), R303.2
unnamed 56: D401.2 (A), D402.1 (K), Q401.3 (C), TP401.1; also elsewhere on the board
unnamed: D402.2 (A), R403.2
unnamed: Q301.1 (B), R304.1
unnamed: Q401.1 (B), R404.1

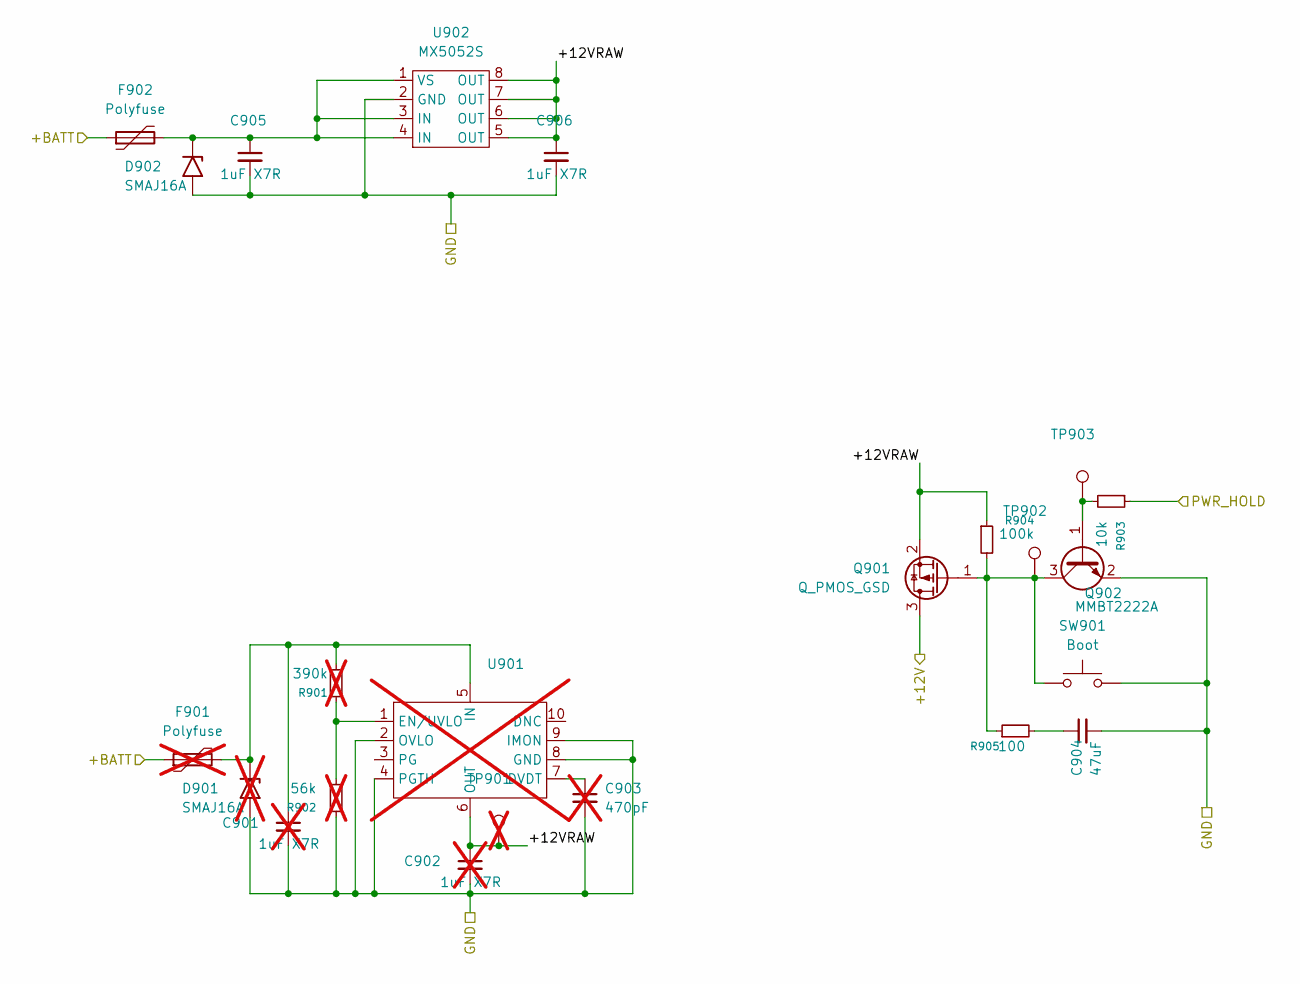
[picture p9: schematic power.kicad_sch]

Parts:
C901, C902: 1uF X7R; C_0603_1608Metric; LCSC C5199872; not fitted
C903: 470pF; C_0603_1608Metric; LCSC C1620; not fitted
C904: 47uF; C_1206_3216Metric; LCSC C22367835
C905, C906: 1uF X7R; C_0603_1608Metric; LCSC C5199872
D901: SMAJ16A; D_SMB; LCSC C19077571; not fitted
D902: SMAJ16A; D_SMB; LCSC C19077571
F901: Polyfuse; Fuse_1812_4532Metric; LCSC C18198333; not fitted
F902: Polyfuse; Fuse_1812_4532Metric; LCSC C18198333
Q901: Q_PMOS_GSD; SOT-23; LCSC C52437601
Q902: MMBT2222A; SOT-23; LCSC C8512
R901: 390k; R_0603_1608Metric; not fitted
R902: 56k; R_0603_1608Metric; not fitted
R903: 10k; R_0603_1608Metric; LCSC C25804
R904: 100k; R_0603_1608Metric; LCSC C25803
R905: 100; R_0402_1005Metric; LCSC C705627
SW901: Boot; SW_SPST_PTS810; LCSC C221897
TP901: 12VRAW; TestPoint_Pad_D1.5mm; not fitted
TP902: PWRCTL; TestPoint_Pad_D1.5mm
TP903: PWRHLD; TestPoint_Pad_D1.5mm
U901: VQFN-10-HR(2x2); LCSC C3210761; not fitted
U902: MX5052S; SOIC-8_3.9x4.9mm_P1.27mm; LCSC C5875696

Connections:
+12V: Q901.3 (D); also elsewhere on the board
+BATT: F901.1, F902.1; also elsewhere on the board
/PWR_HOLD: R903.1; also elsewhere on the board
/Power/+12VRAW: C902.1, C906.1, Q901.2 (S), R904.1, TP901.1, U901.6 (OUT), U902.5 (OUT), U902.6 (OUT), U902.7 (OUT), U902.8 (OUT)
GND1: C901.2, C902.2, C903.2, C904.2, C905.2, C906.2, D901.2 (A2), D902.2 (A2), Q902.2 (E), R902.1, SW901.2, U901.2 (OVLO), U901.4 (PGTH), U901.8 (GND), U901.9 (IMON), U902.2 (GND); also elsewhere on the board
unnamed: C904.1, R905.2
unnamed: C905.1, D902.1 (A1), F902.2, U902.1 (VS), U902.3 (IN), U902.4 (IN)
unnamed: C901.1, D901.1 (A1), F901.2, R901.2, U901.5 (IN)
unnamed: Q901.1 (G), Q902.3 (C), R904.2, R905.1, SW901.1, TP902.1
unnamed: Q902.1 (B), R903.2, TP903.1
unnamed: C903.1, U901.7 (DVDT)
unnamed: R901.1, R902.2, U901.1 (EN/UVLO)

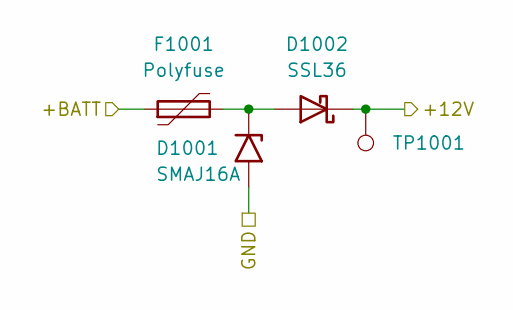
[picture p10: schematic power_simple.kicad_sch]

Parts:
D1001: SMAJ16A; D_SMB; LCSC C19077571
D1002: SSL36; D_SMA; LCSC C28646286
F1001: Polyfuse; Fuse_1812_4532Metric; LCSC C18198333
TP1001: TestPoint; TestPoint_Pad_D1.5mm

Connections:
unnamed: D1001.1 (A1), D1002.2 (A), F1001.2
unnamed: D1002.1 (K), TP1001.1

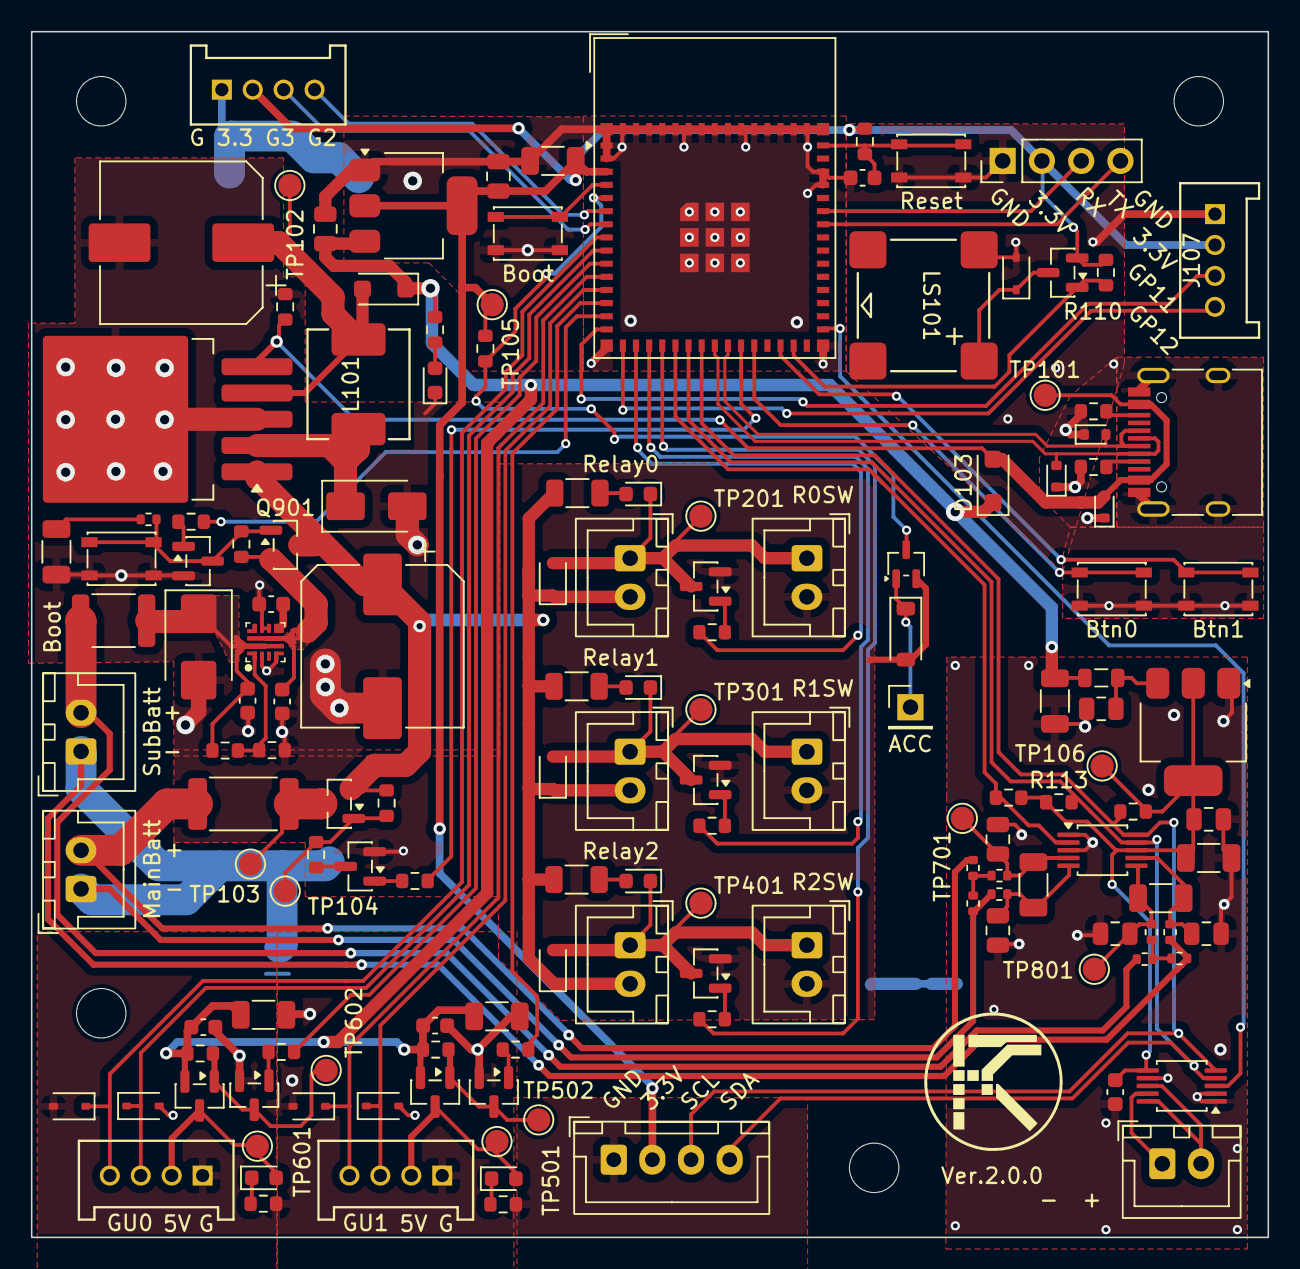
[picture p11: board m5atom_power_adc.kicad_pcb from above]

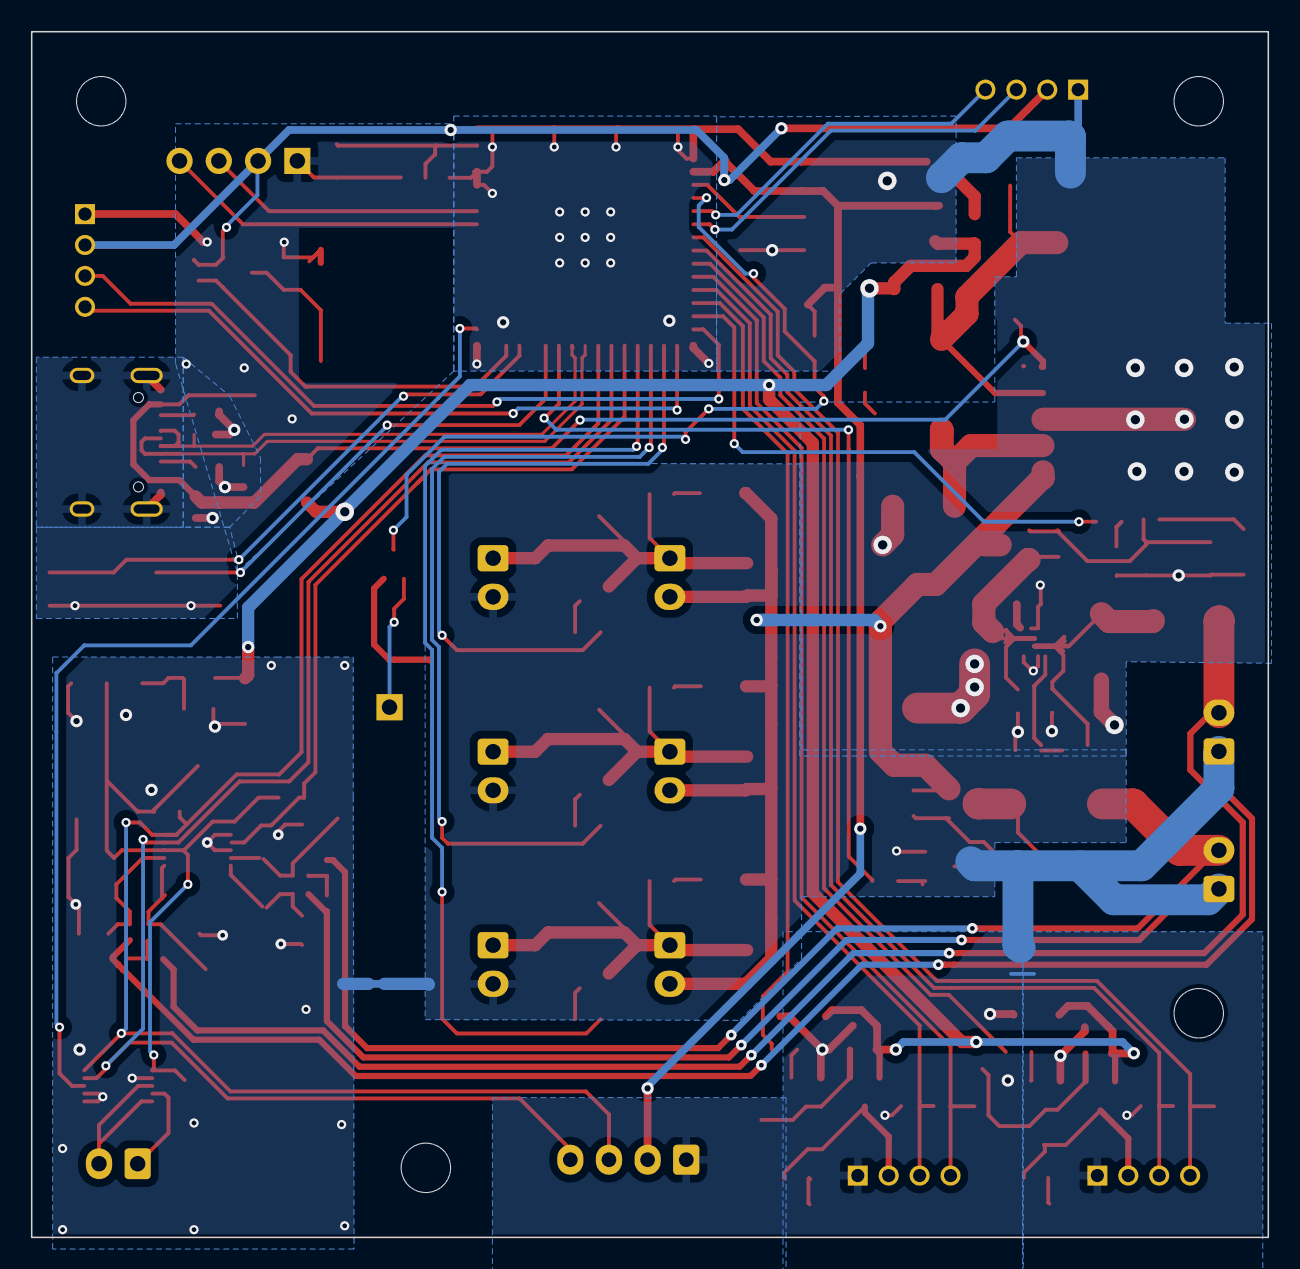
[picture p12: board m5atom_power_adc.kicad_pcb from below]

Board: 2 copper layers, 80.0 x 78.0 mm, 150 parts (3 on the bottom side), 85 nets.

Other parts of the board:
J301: Relay1; JST_XH_B2B-XH-A_1x02_P2.50mm_Vertical
J302: R1SW; JST_XH_B2B-XH-A_1x02_P2.50mm_Vertical
J401: Relay2; JST_XH_B2B-XH-A_1x02_P2.50mm_Vertical
J402: R2SW; JST_XH_B2B-XH-A_1x02_P2.50mm_Vertical

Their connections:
+12V: J301.2, J401.2; also elsewhere on the board
GND1: J302.2, J402.2; also elsewhere on the board
unnamed 54: J301.1, J302.1; also elsewhere on the board
unnamed 56: J401.1, J402.1; also elsewhere on the board

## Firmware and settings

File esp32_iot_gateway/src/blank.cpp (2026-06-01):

#include <Arduino.h>
#include "driver/twai.h"

#define CAN_RX_PIN 8 // MCP2562FD RXD
#define CAN_TX_PIN 7 // MCP2562FD TXD
#define CAN_EN_PIN 9 // AO3401A パワースイッチ: HIGH=電源ON
#define BTN0_PIN 26
#define BTN1_PIN 33

// フェーズ切り替え:
//   PHASE_LISTEN (デフォルト): LISTEN_ONLY でバス上の全フレームを受信
//   コメントアウトすると TWAI_MODE_NORMAL + OBD-II PID スキャンに切り替わる
// #define PHASE_LISTEN

#ifdef PHASE_LISTEN
#define CAN_MODE TWAI_MODE_LISTEN_ONLY
#else
#define CAN_MODE TWAI_MODE_NORMAL
#define RUN_PID_SCAN
#endif

static bool twaiReady = false;

// ----------------------------------------------------------------
// OBD-II ヘルパー（TWAI_MODE_NORMAL 時のみ有効）
// ----------------------------------------------------------------

static bool sendObdRequest(uint8_t pid)
{
  twai_message_t tx = {};
  tx.identifier = 0x18DB33F1; // 29-bit functional addressing (van/truck)
  tx.extd = 1;
  tx.data_length_code = 8;
  tx.data[0] = 0x02; // PCI: Single Frame, length=2
  tx.data[1] = 0x01; // Mode 01
  tx.data[2] = pid;
  // data[3..7] はゼロ初期化済み（ISO 15765-4 パディング）
  return twai_transmit(&tx, pdMS_TO_TICKS(10)) == ESP_OK;
}

// CAN ID=0x7E8 の応答を受信（timeoutMs 内）
static bool receiveObdResponse(uint8_t *data, uint8_t *dlc, uint32_t timeoutMs)
{
  unsigned long deadline = millis() + timeoutMs;
  while (millis() < deadline)
  {
    twai_message_t rx = {};
    if (twai_receive(&rx, pdMS_TO_TICKS(10)) == ESP_OK)
    {
      bool is29bit = rx.extd && (rx.identifier & 0xFFFFFF00) == 0x18DAF100;
      bool is11bit = !rx.extd && rx.identifier == 0x7E8;
      if (is29bit || is11bit)
      {
        memcpy(data, rx.data, 8);
        *dlc = rx.data_length_code;
        return true;
      }
    }
  }
  return false;
}

// PID 0x00/0x20/0x40 を送信し、サポートビットマスク(32bit)を返す
// base=0x00 → PIDs 0x01-0x20, base=0x20 → 0x21-0x40, base=0x40 → 0x41-0x60
static uint32_t getSupportedPidMask(uint8_t supportPid)
{
  twai_message_t txMsg = {};
  esp_err_t txErr;
  txMsg.identifier = 0x18DB33F1; // 29-bit functional addressing
  txMsg.extd = 1;
  txMsg.data_length_code = 8;
  txMsg.data[0] = 0x02;
  txMsg.data[1] = 0x01;
  txMsg.data[2] = supportPid;
  txErr = twai_transmit(&txMsg, pdMS_TO_TICKS(10));
  Serial.printf("[DBG] TX 0x18DB33F1 pid=0x%02X: %s (0x%x)\n",
                supportPid, txErr == ESP_OK ? "OK" : "FAIL", txErr);
  if (txErr != ESP_OK)
    return 0;

  // 応答待ち: 0x7E8 以外のフレームも全部表示する
  unsigned long deadline = millis() + 500;
  while (millis() < deadline)
  {
    twai_message_t rx = {};
    if (twai_receive(&rx, pdMS_TO_TICKS(10)) == ESP_OK)
    {
      Serial.printf("[DBG] RX id=0x%08lX ext=%d len=%d data=", rx.identifier, rx.extd, rx.data_length_code);
      for (int i = 0; i < rx.data_length_code; i++)
        Serial.printf("%02X ", rx.data[i]);
      Serial.println();
      bool is29bit = rx.extd && (rx.identifier & 0xFFFFFF00) == 0x18DAF100;
      bool is11bit = !rx.extd && rx.identifier == 0x7E8;
      if ((is29bit || is11bit) && rx.data[1] == 0x41 && rx.data[2] == supportPid)
      {
        return ((uint32_t)rx.data[3] << 24) | ((uint32_t)rx.data[4] << 16) | ((uint32_t)rx.data[5] << 8) | rx.data[6];
      }
    }
  }
  Serial.printf("[DBG] TX pid=0x%02X: no response\n", supportPid);
  return 0;
}

// MSB = base+1 に対応（例: mask bit31 = PID(base+1)）
static bool isPidSupported(uint32_t mask, uint8_t pid, uint8_t base)
{
  if (pid <= base || pid > base + 32)
    return false;
  uint8_t bit = pid - base - 1;
  return (mask >> (31 - bit)) & 1;
}

// PID をポーリングして応答を返す。サポートされていない場合は false
static bool queryPid(uint8_t pid, uint8_t *data, uint8_t *dlc)
{
  return sendObdRequest(pid) && receiveObdResponse(data, dlc, 300) && data[1] == 0x41 && data[2] == pid;
}

// 各 PID のデコードとシリアル出力
static void printPidResult(uint8_t pid, const char *name,
                           uint32_t mask0, uint32_t mask1, uint32_t mask2,
                           uint32_t mask3 = 0, uint32_t mask4 = 0)
{
  // サポート確認
  bool supported = false;
  if (pid >= 0x01 && pid <= 0x20)
    supported = isPidSupported(mask0, pid, 0x00);
  else if (pid >= 0x21 && pid <= 0x40)
    supported = isPidSupported(mask1, pid, 0x20);
  else if (pid >= 0x41 && pid <= 0x60)
    supported = isPidSupported(mask2, pid, 0x40);
  else if (pid >= 0x61 && pid <= 0x80)
    supported = isPidSupported(mask3, pid, 0x60);
  else if (pid >= 0x81 && pid <= 0xA0)
    supported = isPidSupported(mask4, pid, 0x80);

  if (!supported)
  {
    Serial.printf("[0x%02X] %-20s -- (not supported)\n", pid, name);
    return;
  }

  uint8_t data[8] = {};
  uint8_t dlc = 0;
  if (!queryPid(pid, data, &dlc))
  {
    Serial.printf("[0x%02X] %-20s !! (no response)\n", pid, name);
    return;
  }

  uint8_t A = data[3];
  uint8_t B = data[4];

  switch (pid)
  {
  case 0x04:
    Serial.printf("[0x04] %-20s OK -> %d%%\n", name, (int)(A * 100 / 255));
    break;
  case 0x05:
    Serial.printf("[0x05] %-20s OK -> %d degC\n", name, (int)A - 40);
    break;
  case 0x0A:
    Serial.printf("[0x0A] %-20s OK -> %d kPa\n", name, A * 3);
    break;
  case 0x0B:
    Serial.printf("[0x0B] %-20s OK -> %d kPa (boost: %d kPa)\n",
                  name, A, (int)A - 101);
    break;
  case 0x0C:
    Serial.printf("[0x0C] %-20s OK -> %d rpm\n", name,
                  (int)((A * 256 + B) / 4));
    break;
  case 0x0D:
    Serial.printf("[0x0D] %-20s OK -> %d km/h\n", name, A);
    break;
  case 0x0E:
    Serial.printf("[0x0E] %-20s OK -> %.1f deg BTDC\n",
                  name, A / 2.0f - 64.0f);
    break;
  case 0x0F:
    Serial.printf("[0x0F] %-20s OK -> %d degC\n", name, (int)A - 40);
    break;
  case 0x10:
    Serial.printf("[0x10] %-20s OK -> %.2f g/s\n",
                  name, (A * 256 + B) / 100.0f);
    break;
  case 0x11:
    Serial.printf("[0x11] %-20s OK -> %d%%\n", name, (int)(A * 100 / 255));
    break;
  case 0x2F:
    Serial.printf("[0x2F] %-20s OK -> %d%%\n", name, (int)(A * 100 / 255));
    break;
  case 0x33:
    Serial.printf("[0x33] %-20s OK -> %d kPa\n", name, A);
    break;
  case 0x42:
    Serial.printf("[0x42] %-20s OK -> %.3f V\n", name, (A * 256 + B) / 1000.0f);
    break;
  case 0x5C:
    Serial.printf("[0x5C] %-20s OK -> %d degC\n", name, (int)A - 40);
    break;
  case 0x5E:
    Serial.printf("[0x5E] %-20s OK -> %.2f L/h\n",
                  name, (A * 256 + B) * 0.05f);
    break;
  case 0x61:
  case 0x62:
    Serial.printf("[0x%02X] %-20s OK -> %d%%\n", pid, name, (int)A - 125);
    break;
  case 0x63:
    Serial.printf("[0x63] %-20s OK -> %d Nm\n", name, (int)(A * 256 + B));
    break;
  case 0x66:
  {
    // B*256+C = sensor1 rate in 1/32 g/s units
    uint8_t C = data[5];
    Serial.printf("[0x66] %-20s OK -> sensors=0x%02X MAF1=%.2f g/s\n",
                  name, A, (B * 256 + C) / 32.0f);
    break;
  }
  case 0x67:
    // A=bitmap(bit0=S1,bit1=S2), B=S1 temp, C=S2 temp
    Serial.printf("[0x67] %-20s OK -> sensors=0x%02X S1=%d degC S2=%d degC\n",
                  name, A, (int)B - 40, (int)data[5] - 40);
    break;
  case 0x68:
  {
    // A=bitmap, B=charge air cooler inlet temp, C=outlet temp
    Serial.printf("[0x68] %-20s OK -> sensors=0x%02X in=%d degC out=%d degC\n",
                  name, A, (int)B - 40, (int)data[5] - 40);
    break;
  }
  case 0x70:
  {
    // A=control support bitmap, B*256+C=reference boost, D*256+E=actual boost
    uint8_t D = data[6];
    Serial.printf("[0x70] %-20s OK -> ctrl=0x%02X ref=%d kPa act=%d kPa\n",
                  name, A,
                  (int)(B * 256 + data[5]) - 32767,
                  (int)(D * 256 + data[7]) - 32767);
    break;
  }
  case 0x72:
  {
    // A=sensor bitmap, B*256+C=turbo1 RPM (*2), D*256+E=turbo2 RPM (*2)
    uint8_t C = data[5];
    Serial.printf("[0x72] %-20s OK -> sensors=0x%02X T1=%d rpm\n",
                  name, A, (B * 256 + C) * 2);
    break;
  }
  case 0x7F:
    Serial.printf("[0x7F] %-20s OK -> %lu sec\n",
                  name, ((uint32_t)A << 16) | ((uint32_t)B << 8) | data[5]);
    break;
  default:
    Serial.printf("[0x%02X] %-20s OK -> A=0x%02X B=0x%02X\n",
                  pid, name, A, B);
    break;
  }
}

// ----------------------------------------------------------------
// Arduino エントリポイント
// ----------------------------------------------------------------

static bool twaiInit(twai_mode_t mode)
{
  twai_general_config_t gConfig = TWAI_GENERAL_CONFIG_DEFAULT(
      (gpio_num_t)CAN_TX_PIN, (gpio_num_t)CAN_RX_PIN, mode);
  twai_timing_config_t tConfig = TWAI_TIMING_CONFIG_500KBITS();
  twai_filter_config_t fConfig = TWAI_FILTER_CONFIG_ACCEPT_ALL();
  if (twai_driver_install(&gConfig, &tConfig, &fConfig) != ESP_OK)
    return false;
  if (twai_start() != ESP_OK)
  {
    twai_driver_uninstall();
    return false;
  }
  return true;
}

void setup()
{
  Serial.begin(115200);
  delay(5000);

  pinMode(BTN0_PIN, INPUT_PULLUP);
  pinMode(BTN1_PIN, INPUT_PULLUP);

  // AO3401A パワースイッチ HIGH → MCP2562FD 電源 ON
  pinMode(CAN_EN_PIN, OUTPUT);
  digitalWrite(CAN_EN_PIN, HIGH);
  delay(50);

#ifndef PHASE_LISTEN
  // ---- TX テスト（NO_ACK、オシロ確認用）----
  // PHASE_LISTEN 時はスキップ（実車バスに不要な送信を行わない）
  Serial.println("=== TX test (500kbps, 5sec) ===");
  if (!twaiInit(TWAI_MODE_NO_ACK))
  {
    Serial.println("TWAI init failed (TX phase)");
    return;
  }
  unsigned long txStart = millis();
  uint32_t txCount = 0;
  while (millis() - txStart < 5000)
  {
    twai_message_t tx = {};
    tx.identifier = 0x123;
    tx.data_length_code = 4;
    tx.data[0] = (txCount >> 24) & 0xFF;
    tx.data[1] = (txCount >> 16) & 0xFF;
    tx.data[2] = (txCount >> 8) & 0xFF;
    tx.data[3] = txCount & 0xFF;
    esp_err_t err = twai_transmit(&tx, pdMS_TO_TICKS(10));
    Serial.printf("TX %s cnt=%lu\n", err == ESP_OK ? "ok" : "fail", txCount);
    txCount++;
    delay(2000);
  }
  twai_stop();
  twai_driver_uninstall();
  Serial.println("TX test done. Switching to receive mode...");
  delay(100);
#endif

  // ---- 受信モード（LISTEN_ONLY or NORMAL）----
  if (!twaiInit(CAN_MODE))
  {
    Serial.println("TWAI init failed (RX phase)");
    return;
  }

  twaiReady = true;

#ifdef RUN_PID_SCAN
  Serial.println("=== OBD-II PID Scan (Step B) ===");
  Serial.println("Fetching support bitmasks...");

  uint32_t mask0 = getSupportedPidMask(0x00); // PIDs 0x01-0x20
  delay(1000);
  uint32_t mask1 = getSupportedPidMask(0x20); // PIDs 0x21-0x40
  delay(1000);
  uint32_t mask2 = getSupportedPidMask(0x40); // PIDs 0x41-0x60
  delay(1000);
  uint32_t mask3 = getSupportedPidMask(0x60); // PIDs 0x61-0x80
  delay(1000);
  uint32_t mask4 = getSupportedPidMask(0x80); // PIDs 0x81-0xA0
  delay(1000);
  Serial.printf("Mask[0x00]=0x%08lX  Mask[0x20]=0x%08lX\n", mask0, mask1);
  Serial.printf("Mask[0x40]=0x%08lX  Mask[0x60]=0x%08lX\n", mask2, mask3);
  Serial.printf("Mask[0x80]=0x%08lX\n", mask4);

  Serial.println("--- Priority 1 ---");
  printPidResult(0x04, "Engine Load", mask0, mask1, mask2);
  printPidResult(0x05, "Coolant Temp", mask0, mask1, mask2);
  printPidResult(0x0B, "MAP", mask0, mask1, mask2);
  printPidResult(0x0C, "RPM", mask0, mask1, mask2);
  printPidResult(0x0D, "Speed", mask0, mask1, mask2);
  printPidResult(0x11, "Throttle", mask0, mask1, mask2);

  Serial.println("--- Priority 2 ---");
  printPidResult(0x0A, "Fuel Pressure", mask0, mask1, mask2);
  printPidResult(0x0E, "Ignition Adv", mask0, mask1, mask2);
  printPidResult(0x0F, "Intake Temp", mask0, mask1, mask2);
  printPidResult(0x10, "MAF", mask0, mask1, mask2);
  printPidResult(0x2F, "Fuel Level", mask0, mask1, mask2);
  printPidResult(0x33, "Baro", mask0, mask1, mask2);
  printPidResult(0x42, "ECU Voltage", mask0, mask1, mask2);
  printPidResult(0x5C, "Oil Temp", mask0, mask1, mask2);
  printPidResult(0x5E, "Fuel Rate", mask0, mask1, mask2);

  Serial.println("--- Priority 3 (0x61-0x80) ---");
  printPidResult(0x61, "Torque Demand", mask0, mask1, mask2, mask3);
  printPidResult(0x62, "Torque Actual", mask0, mask1, mask2, mask3);
  printPidResult(0x63, "Torque Ref", mask0, mask1, mask2, mask3);
  printPidResult(0x66, "MAF Alt", mask0, mask1, mask2, mask3);
  printPidResult(0x67, "Coolant Temp Alt", mask0, mask1, mask2, mask3);
  printPidResult(0x68, "Charge Air Temp", mask0, mask1, mask2, mask3);
  printPidResult(0x6C, "Throttle Actuator", mask0, mask1, mask2, mask3);
  printPidResult(0x6E, "Boost Ctrl", mask0, mask1, mask2, mask3);
  printPidResult(0x70, "Boost Pressure", mask0, mask1, mask2, mask3);
  printPidResult(0x72, "Turbo RPM", mask0, mask1, mask2, mask3);
  printPidResult(0x7F, "Engine Run Time", mask0, mask1, mask2, mask3);

  Serial.println("--- Priority 4 (0x81-0xA0) ---");
  printPidResult(0x83, "NOx Sensor", mask0, mask1, mask2, mask3, mask4);
  printPidResult(0x84, "Manifold Surf Temp", mask0, mask1, mask2, mask3, mask4);
  printPidResult(0x87, "MAP Alt", mask0, mask1, mask2, mask3, mask4);
  printPidResult(0x8C, "EGT Bank1", mask0, mask1, mask2, mask3, mask4);
  printPidResult(0x98, "EGT Bank2", mask0, mask1, mask2, mask3, mask4);
  printPidResult(0x9D, "Fuel Inj Timing", mask0, mask1, mask2, mask3, mask4);
  printPidResult(0x9E, "Engine Fuel Rate", mask0, mask1, mask2, mask3, mask4);
  printPidResult(0x9F, "Emission Req", mask0, mask1, mask2, mask3, mask4);

  {
    twai_status_info_t sts;
    twai_get_status_info(&sts);
    Serial.printf("TWAI: state=%d txerr=%lu rxerr=%lu bus_err=%lu arb_lost=%lu\n",
                  (int)sts.state, sts.tx_error_counter, sts.rx_error_counter,
                  sts.bus_error_count, sts.arb_lost_count);
  }
  Serial.println("=== Scan complete. Entering receive-only mode. ===");
#else
  Serial.println("=== Step A: LISTEN_ONLY 500kbps ===");
  Serial.println("Waiting for CAN frames from vehicle...");
  Serial.println("Turn on ignition (IGN ON) and observe frames below.");
#endif
}

#ifdef RUN_PID_SCAN
static void pollObd()
{
  uint8_t data[8];
  uint8_t dlc;

  // --- エンジン基本 ---
  uint16_t rpm     = 0; if (queryPid(0x0C, data, &dlc)) rpm     = (data[3] * 256 + data[4]) / 4;
  uint8_t  spd     = 0; if (queryPid(0x0D, data, &dlc)) spd     = data[3];
  uint8_t  load    = 0; if (queryPid(0x04, data, &dlc)) load    = data[3] * 100 / 255;
  uint8_t  absLoad = 0; if (queryPid(0x43, data, &dlc)) absLoad = (uint32_t)(data[3] * 256 + data[4]) * 100 / 255;
  uint8_t  mapKpa  = 0; if (queryPid(0x0B, data, &dlc)) mapKpa  = data[3];
  uint8_t  tps     = 0; if (queryPid(0x11, data, &dlc)) tps     = data[3] * 100 / 255;
  uint8_t  tpsB    = 0; if (queryPid(0x47, data, &dlc)) tpsB    = data[3] * 100 / 255;
  uint8_t  appD    = 0; if (queryPid(0x49, data, &dlc)) appD    = data[3] * 100 / 255;
  uint8_t  appE    = 0; if (queryPid(0x4A, data, &dlc)) appE    = data[3] * 100 / 255;
  float    ign     = 0; if (queryPid(0x0E, data, &dlc)) ign     = data[3] / 2.0f - 64.0f;
  uint8_t  baro    = 0; if (queryPid(0x33, data, &dlc)) baro    = data[3];
  float    ecuV    = 0; if (queryPid(0x42, data, &dlc)) ecuV    = (data[3] * 256 + data[4]) / 1000.0f;
  uint16_t runTime = 0; if (queryPid(0x1F, data, &dlc)) runTime = data[3] * 256 + data[4];

  // --- 燃料・空燃比 ---
  float   maf     = 0; if (queryPid(0x66, data, &dlc)) maf     = (data[4] * 256 + data[5]) / 32.0f;
  float   stft    = 0; if (queryPid(0x06, data, &dlc)) stft    = (data[3] - 128.0f) * 100.0f / 128.0f;
  float   ltft    = 0; if (queryPid(0x07, data, &dlc)) ltft    = (data[3] - 128.0f) * 100.0f / 128.0f;
  float   lambda  = 0; if (queryPid(0x44, data, &dlc)) lambda  = (data[3] * 256 + data[4]) * 2.0f / 65536.0f;
  uint8_t evap    = 0; if (queryPid(0x2E, data, &dlc)) evap    = data[3] * 100 / 255;

  // --- O2 センサー ---
  // 0x15: A=電圧(A/200 V), B=燃料トリム((B-128)*100/128 %)
  float   o2v     = 0; float o2ft = 0;
  if (queryPid(0x15, data, &dlc)) { o2v = data[3] / 200.0f; o2ft = (data[4] - 128.0f) * 100.0f / 128.0f; }
  // 0x24: A*256+B = lambda×2/65536, C*256+D = 電圧×8/65536 V
  float   wbLambda = 0; float wbV = 0;
  if (queryPid(0x24, data, &dlc)) {
    wbLambda = (data[3] * 256 + data[4]) * 2.0f / 65536.0f;
    wbV      = (data[5] * 256 + data[6]) * 8.0f / 65536.0f;
  }
  float   stft2   = 0; if (queryPid(0x55, data, &dlc)) stft2 = (data[3] - 128.0f) * 100.0f / 128.0f;
  float   ltft2   = 0; if (queryPid(0x56, data, &dlc)) ltft2 = (data[3] - 128.0f) * 100.0f / 128.0f;

  // --- 温度 ---
  int16_t clt     = 0; if (queryPid(0x67, data, &dlc)) clt     = (int16_t)data[4] - 40;
  // 0x3C: (A*256+B)/10 - 40 °C
  float   catTemp = 0; if (queryPid(0x3C, data, &dlc)) catTemp = (data[3] * 256 + data[4]) / 10.0f - 40.0f;

  // --- 走行累積 ---
  uint16_t milDist  = 0; if (queryPid(0x21, data, &dlc)) milDist  = data[3] * 256 + data[4];
  uint8_t  warmups  = 0; if (queryPid(0x30, data, &dlc)) warmups  = data[3];
  uint16_t clrDist  = 0; if (queryPid(0x31, data, &dlc)) clrDist  = data[3] * 256 + data[4];
  uint8_t  fuelType = 0; if (queryPid(0x51, data, &dlc)) fuelType = data[3];

  Serial.println("--- OBD poll ---");
  Serial.printf(" Engine : RPM:%4d SPD:%3dkm/h LOAD:%3d%% ABS:%3d%% MAP:%3dkPa IGN:%+5.1fdeg BARO:%3dkPa\n",
                rpm, spd, load, absLoad, mapKpa, ign, baro);
  Serial.printf(" Throttle: TPS:%3d%% TPSB:%3d%% APP-D:%3d%% APP-E:%3d%%\n",
                tps, tpsB, appD, appE);
  Serial.printf(" Fuel/AFR: MAF:%.2fg/s STFT:%+.1f%% LTFT:%+.1f%% Lambda:%.4f Evap:%3d%%\n",
                maf, stft, ltft, lambda, evap);
  Serial.printf(" O2      : NB=%.3fV(%+.1f%%) WB-L=%.4f WB-V=%.3fV STFT2:%+.1f%% LTFT2:%+.1f%%\n",
                o2v, o2ft, wbLambda, wbV, stft2, ltft2);
  Serial.printf(" Temp    : CLT:%3dC CAT:%.1fC\n", (int)clt, catTemp);
  Serial.printf(" Misc    : ECU:%.3fV RunTime:%us MIL-dist:%ukm Warmups:%u ClrDist:%ukm FuelType:%u\n",
                ecuV, runTime, milDist, warmups, clrDist, fuelType);
}
#endif

void loop()
{
  if (digitalRead(BTN0_PIN) == LOW || digitalRead(BTN1_PIN) == LOW)
  {
    Serial.println("Button pressed, restarting...");
    delay(100);
    ESP.restart();
  }

  if (!twaiReady)
    return;

#ifdef RUN_PID_SCAN
  static unsigned long lastPollMs = 0;
  if (millis() - lastPollMs >= 2000)
  {
    lastPollMs = millis();
    pollObd();
  }
#else
  twai_message_t rx = {};
  if (twai_receive(&rx, pdMS_TO_TICKS(10)) == ESP_OK)
  {
    Serial.printf("RX id=0x%08lX ext=%d len=%d data=", rx.identifier, rx.extd, rx.data_length_code);
    for (int i = 0; i < rx.data_length_code; i++)
      Serial.printf("%02X ", rx.data[i]);
    Serial.println();
  }
#endif

  static unsigned long lastStsMs = 0;
  if (millis() - lastStsMs >= 10000)
  {
    lastStsMs = millis();
    twai_status_info_t sts;
    twai_get_status_info(&sts);
    Serial.printf("[STS] state=%d txerr=%lu rxerr=%lu bus_err=%lu arb_lost=%lu\n",
                  (int)sts.state, sts.tx_error_counter, sts.rx_error_counter,
                  sts.bus_error_count, sts.arb_lost_count);
    if (sts.state == TWAI_STATE_BUS_OFF)
    {
      Serial.println("[STS] BUS_OFF detected, initiating recovery...");
      twai_initiate_recovery();
    }
  }
}

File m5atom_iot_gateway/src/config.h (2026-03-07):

#pragma once
#include <stdint.h>

#ifndef GIT_HASH
#define GIT_HASH "00000000"
#endif
#define FIRMWARE_VERSION "1.0.0+" GIT_HASH

static const uint16_t SWITCHBOT_COMPANY_ID = 0x0969;
static const int SCAN_TIME = 10; // BLE スキャン時間（秒）
static const int QUEUE_SIZE = 20;
static const int MAX_TARGETS = 10;
static const int MAX_FOUND = 20;
static const uint8_t BTN_PIN = 41; // M5Atom S3 ボタン (Active-LOW)
static const uint32_t LONG_PRESS_MS = 1000;
static const uint32_t DEBOUNCE_MS = 50;
static const uint32_t SLEEP_INTERVAL_SEC  = 300; // Deep Sleep 間隔（秒）
static const int      PAYLOAD_BATTERY_SIZE = 128; // battery ペイロードバッファ
static const int      PAYLOAD_SENSOR_SIZE  = 256; // sensor ペイロードバッファ（mf hex 込み）

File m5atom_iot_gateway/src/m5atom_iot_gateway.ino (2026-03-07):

/*
 * M5Stamp Lite 統合スケッチ
 * 機能:
 *   1. ADS1115 電圧測定（差動 AIN1-AIN0 / 分圧回路）
 *   2. SwitchBot 防水温湿度計 BLE スキャン
 *   3. SORACOM Harvest Data (LTE/SIM7080G) への HTTP POST
 *
 * ハードウェア:
 *   - M5Atom S3 (ESP32-S3)
 *   - ADS1115 on Port A (SDA=G38, SCL=G39, ADDR=0x49)
 *   - M5Stack U128 (SIM7080G): RX=G1(GPIO1), TX=G2(GPIO2)  ※ラベル逆注意
 *
 * LTE 注意事項:
 *   - APN は CFUN=0 → CGDCONT → CFUN=1 の順で設定（必須）
 *   - modem.restart() は使わず modem.init() を使う
 *   - SORACOM SIM グループで Harvest Data を有効化すること
 */

// デバッグモード: 有効時 → 待機ループ＋登録モード、無効時 → DeepSleep
#define DEBUG_MODE

// M5Unified は BLE より先に include（必須 - ARCHITECTURE.md 参照）
#include "app/view.h"
#include "config.h"
#include "certs.h"
#include "domain/targets.h"
#include "infra/ble_scan.h"
#include "infra/button.h"
#include "app/register_mode.h"

#include <Wire.h>
#include <Adafruit_ADS1X15.h>
#include "infra/lte.h"
#include "infra/logger.h"
#include "app/bypass_mode.h"

// ─── ADS1115 ─────────────────────────────────────────────────────────────
// 分圧回路（差動）: +/− → R1(680kΩ) → AIN0/AIN1 → R2(11kΩ) → GND
// GAIN_EIGHT(±0.512V) で最大 ±32V 測定可能
static const uint8_t SDA_PIN = 38;
static const uint8_t SCL_PIN = 39;
static const float R1 = 680000.0f;
static const float R2 = 11000.0f;
static const float DIV_RATIO = R2 / (R1 + R2);

Adafruit_ADS1115 ads;

// ─── モード管理 ───────────────────────────────────────────────────────────
enum Mode
{
  MODE_SCAN,
  MODE_REGISTER
};
static Mode gMode = MODE_SCAN;

// ─── ユーティリティ ───────────────────────────────────────────────────────

// ISO8601 UTC タイムスタンプを生成する（RTC 未同期なら空文字列）
static void buildTimestamp(char *buf, size_t size)
{
  time_t now = time(nullptr);
  if (now < 1000000000L)
  {
    buf[0] = '\0';
    return;
  }
  strftime(buf, size, "%Y-%m-%dT%H:%M:%SZ", gmtime(&now));
}

// ADS1115 から電圧を読み取る（分圧回路換算）
static float readVoltage()
{
  int16_t raw = ads.readADC_Differential_0_1();
  float adcV = ads.computeVolts(raw);
  return -adcV / DIV_RATIO;
}

// ─── 初期化関数 ───────────────────────────────────────────────────────────

static void initAds()
{
  Wire.begin(SDA_PIN, SCL_PIN);
  ads.setGain(GAIN_EIGHT);
  if (!ads.begin(0x49))
  {
    view.message("[ADS] ADS1115 not found!");
    while (1)
      delay(1000);
  }
  view.message("[ADS] OK");
}

static void initButton()
{
  pinMode(BTN_PIN, INPUT_PULLUP);
  button.setup();
}

static void initBle()
{
  targets.load();
  scanner.setup();
  view.message("[BLE] OK  [長押し: 登録モード]");
}

// ─── setup / loop ─────────────────────────────────────────────────────────

void setup()
{
  M5.begin();
  logger.init();
  view.clear();
  view.message("=== セットアップ中 ===");
  delay(1000);
  view.clear();
  initButton();

  // bypassMode.run();

  initAds();
  initBle();
  lte.setup();

  view.message("=== セットアップ完了 ===");
}

#ifdef DEBUG_MODE
time_t prevLoopTime = 0;
#endif

void loop()
{
#ifdef DEBUG_MODE
  // バイパスモード: スキャン・MQTT 送信・登録モード遷移を行わずシリアル転送のみ行う
  if (Serial.available())
  {
    bypassMode.run();
    button.check(); // バイパス中に蓄積したボタンイベントを破棄
    return;
  }
#endif

  // 登録モード（前ループで長押し検出済みの場合）
  if (button.check() == BTN_LONG)
  {
    regMode.run();
    return;
  }

#ifdef DEBUG_MODE
  if (time(nullptr) < prevLoopTime + SEND_INTERVAL_SEC)
  {
    delay(100);
    return;
  }

  prevLoopTime = time(nullptr);
#endif

  // BLE スキャン（スキャン中も ISR がボタンイベントを記録する）
  logger.printf("\n--- BLE スキャン (%d秒) ---\n", SCAN_TIME);
  scanner.start(SCAN_TIME);
  scanner.clearResults();

  // GPRS 接続確認・再接続
  if (!lte.isConnected())
  {
    logger.println("[LTE] 切断検出 → 再接続...");
    lte.disconnect();
    delay(1000);
    if (lte.connect())
      lte.syncTime();
  }

  // タイムスタンプを1回取得して全 payload で共用
  char ts[25];
  buildTimestamp(ts, sizeof(ts));
  char tsField[32] = "";
  if (ts[0])
    snprintf(tsField, sizeof(tsField), ",\"ts\":\"%s\"", ts);

  SensorVariant v;

#ifdef DEBUG_MODE
  // ─── デバッグモード: 送信 → 待機 ─────────────────────────────────────
  {
    float voltage = readVoltage();
    logger.printf("[ADS] 電圧: %.2f V\n", voltage);
    char payload[PAYLOAD_BATTERY_SIZE];
    snprintf(payload, sizeof(payload),
             "{\"type\":\"battery\",\"id\":\"voltage_%d\",\"voltage\":%.2f,\"fw\":\"" FIRMWARE_VERSION "\"%s}", 1, voltage, tsField);
    lte.publish(MQTT_TOPIC_DATA, payload);
  }
  while (xQueueReceive(scanner.queue, &v, 0) == pdTRUE)
  {
    std::visit([&](auto &d)
               {
      if (!d.parsed) return;
      char payload[PAYLOAD_SENSOR_SIZE];
      using T = std::decay_t<decltype(d)>;
      if constexpr (std::is_same_v<T, ThermometerData>)
      {
        view.thermometerData(d);
        snprintf(payload, sizeof(payload),
                 "{\"type\":\"thermometer\",\"addr\":\"%s\",\"temp\":%.1f,\"humidity\":%d,\"battery\":%d,\"rssi\":%d,\"mf\":\"%s\",\"fw\":\"" FIRMWARE_VERSION "\"%s}",
                 d.address, d.temp, d.humidity, d.battery, d.rssi, d.mfHex, tsField);
      }
      else
      {
        view.co2Data(d);
        snprintf(payload, sizeof(payload),
                 "{\"type\":\"co2meter\",\"addr\":\"%s\",\"temp\":%.1f,\"humidity\":%d,\"co2\":%d,\"battery\":%d,\"rssi\":%d,\"mf\":\"%s\",\"fw\":\"" FIRMWARE_VERSION "\"%s}",
                 d.address, d.temp, d.humidity, d.co2, d.battery, d.rssi, d.mfHex, tsField);
      }
      lte.publish(MQTT_TOPIC_DATA, payload); }, v);
  }
  // 待機中も長押しを監視
  logger.printf("[WAIT] %d秒待機... [長押し: 登録モード]\n", SEND_INTERVAL_SEC);
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

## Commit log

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2026-03-07 fix: SQL インジェクション・S3 パストラバーサルの対策を追加
    - query Lambda: addr（MACアドレス形式）・device_id（英数字/ハイフン）・type（ホワイトリスト）・hours（1〜720）の入力バリデーションを追加
    - delete Lambda: s3_keys に raw/year=/month=/day=/hour=/ プレフィックス正規表現検証を追加し、範囲外オブジェクトの削除を防止
2026-03-07 fix: hours の int 変換エラーを 400 で返すよう修正、delete の従来パスに入力バリデーション追加
    - query/delete Lambda: hours パラメータが整数でない場合に 500 でなく 400 を返すよう修正
    - delete Lambda: 従来の addr/id+hours パスにも addr（MAC形式）・sensor_id 検証を追加
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2026-03-10 fix: ble_scan の dangling pointer 修正、Web に LiFePO4 残量% 表示を追加
    - ble_scan.cpp: getAddress().toString().c_str() の一時オブジェクト破棄による
    dangling pointer を std::string で保持する形に修正
    - web/index.html: 電圧グラフに残量%（右Y軸・破線）を追加
    LiFePO4 4S OCV-SOC テーブルで線形補間、テーブル行にも色付き残量%を表示
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2026-03-21 USB接続時にDCDCをoffにするように修正
    [m5atom_power_adc.kicad_sch]
2026-03-21 chore: ADC周辺回路の修正（フェライトビーズ追加・分圧抵抗変更）
    - FB1（フェライトビーズ 600Ω@100MHz）を5V→AMS1117間に追加
    - C16（100nF）をフェライトビーズ前段に追加
    - C7を10uF→47uFに増量
    - R9・R5を11k→22kに変更（ADC分圧比改善）
    [m5atom_power_adc.kicad_sch]
2026-03-23 fix: 必須な外部接続系を追加
    [m5atom_power_adc.kicad_sch]
2026-03-23 fix: リレー駆動用回路テンプレ追加
    [m5atom_power_adc.kicad_sch]
2026-03-24 fix: いろいろ更新
    [m5atom_power_adc.kicad_sch]
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2026-03-26 fix: トランジスタの向きを修正、外部スイッチ用コネクタ追加
    [m5atom_power_adc.kicad_sch]
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2026-04-16 chore: 回路図更新・カスタムフットプリント追加
    - USB-C受電回路（CC1/CC2プルダウン、ESD保護、ORダイオード）追加
    - リレーコイルセンシング回路追加（100k+27k分圧）
    - 電源インジケーターLED（D8）を+5Vラインから取るよう変更
    - リレー制御BJTベース抵抗を10kΩ→1kΩに修正
    - Groveコネクタ・インダクタのカスタムフットプリント追加
    - フットプリントライブラリテーブル追加
    [m5atom_power_adc.kicad_sch]
2026-04-16 docs: HARDWARE.md更新・CIRCUIT.md新規作成
    HARDWARE.md:
    - 分圧抵抗R2/R4を11kΩ→22kΩに修正（BOMと計算式の不整合を解消）
    - 対応電圧範囲を22kΩ分圧比で再計算
    - リレー制御BOMをN-ch FET→MMBT2222A NPN BJTに修正
    - パワースイッチ・リレーセンシング回路の説明を追加
    - USB-C受電回路セクションを追加
    - LED選定を更新（リレーLED色：赤→黄、部品型番追記、電流値修正）
    CIRCUIT.md（新規）:
    - 全回路ブロックの定数・計算式・設計根拠をまとめたリファレンス
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2026-04-16 fix: 部品選定を進めた。あとはSWだけ。
    [m5atom_power_adc.kicad_sch]
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2026-04-18 fix: PCBレイアウトに合わせて回路図・PCBを微修正
    [m5atom_power_adc.kicad_pcb, m5atom_power_adc.kicad_sch]
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2026-04-19 fix: MLT-8530直下のベタGNDを除外（うず電流対策）
    フットプリントにkeeputゾーンを追加し、PCBのベタ銅をLS101 courtyard範囲から除外。
    [m5atom_power_adc.kicad_pcb]
2026-04-20 chore: PCBレイアウト・回路図の細部修正
    - GNDプレーン追加・整理（表裏、スターグラウンド構成）
    - サーマルビア追加（ESP32、LM2596）
    - 孤立GND島の除去
    - 各種配線修正
    [m5atom_power_adc.kicad_pcb, m5atom_power_adc.kicad_sch]
2026-04-20 chore: PCBネジ穴追加・シルク整理・ロゴ追加・フットプリント修正
    - ネジ穴を追加
    - シルク文字・ロゴを整理・追加（k_icon フットプリント）
    - HY2.0-4PZZ コネクタフットプリントを追加
    - 各サブシートのフットプリント修正
    - production/ を .gitignore に追加
    [GroveUnit.kicad_sch, RelayControl.kicad_sch, VoltageSense.kicad_sch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]
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2026-04-21 chore: KiCadプロジェクト更新（回路図・PCBレイアウト各種修正）
    [GroveUnit.kicad_sch, m5atom_power_adc.kicad_pcb, m5atom_power_adc.kicad_sch]
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2026-04-26 chore: m5atom_iot_gateway ビルドエラー修正・フォーマット統一
    - ble_scan.cpp: addr を std::string から const char* に変換（API合わせ）
    - lte.cpp: 証明書の毎回アップロードをコメントアウト（SIM7080Gフラッシュ劣化対策）
    - オートフォーマット適用
    [lte.cpp]
2026-04-26 feat: esp32_iot_gateway 初期実装
    - AWS IoT Jobs による OTA トリガー（$next/get ポーリング）
    - OTA ロールバック（CONFIG_BOOTLOADER_APP_ROLLBACK_ENABLE）
    - Jobs ジョブ状態管理（IN_PROGRESS / SUCCEEDED / FAILED）
    - 証明書 CRC32 管理（SIM7080G フラッシュ劣化対策）
    - ArduinoJson による JSON パース・バージョン一致チェック
    - extra_scripts で firmware.bin を QIO にパッチ（esptool 経由）
    - OTA.md 仕様ドキュメント
    - CLAUDE.md に Python 実行方法を追記
    [partitions_two_ota.csv]
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2026-04-26 docs: ドキュメントを現状に合わせて更新
    - ARCHITECTURE.md: esp32_iot_gateway をデバイス層に追加、S3 firmwareバケット・IoT Jobs をインフラ表に追加
    - CONTEXT.md: esp32_iot_gateway ディレクトリ構成を追加、provision/deploy スクリプトを追加、OTA を実装済みとして更新
    - README.md: esp32_iot_gateway・新スクリプトをリポジトリ構成に追加、lint 警告を修正
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2026-05-02 docs: ARCHITECTURE.md / CONTEXT.md をリファクタリング後の実態に更新
    ARCHITECTURE.md:
    - domain/ テーブルから未実装の battery.h を削除
    - 解決済みの「現状の課題」セクションを削除
    CONTEXT.md:
    - ファイル構成を 3層アーキテクチャ（device/domain/service）に全面更新
    - MQTT ペイロード形式を Shadow 形式と Jobs トピックに更新
    - 主要クラスを実在するインスタンス（lte/mqtt/ota/logger）に修正
    - ドメイン型を VoltageReading / PowerReading に更新
    - 不存在の設計決定（M5Unified、BLE、ボタン ISR）を削除
    - OLED を「将来」→「実装済み」に更新
    - NVS namespace を "d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
2026-05-02 chore: CLAUDE.md にソース構造・include規則・ビルド確認ルールを追加
    - esp32_iot_gateway の 3層ソース構造（device/domain/service）を追記
    - include パスの書き方を明記（src/ 基準・相対パスの使い分け）
    - ファイル移動後のビルド確認をワークフロールールとして追加
    - 「ボード設定は別ツール」削除（曖昧で actionable でなかったため）
    - ピン番号の型を実態（static const uint8_t / #define）に修正
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2026-05-02 fix: SIM7080G の MQTT URC フォーマット対応で OTA を疎通
    pollMqtt を実際の +SMSUB フォーマット（length なし、ペイロード引用符囲み）に
    合わせて書き直し。subscribe 後 delay(500) を追加して Jobs レスポンス取得を安定化。
    バージョンを 1.1.0 に更新。BLE 送信は OTA 確認のため一時無効化。
    [config.h, main.cpp]
2026-05-02 fix: deploy_ota.ps1 の jobID・BOM・英語翻訳を修正
    job-id のドットをアンダースコアに変換（AWS制約対応）、
    Set-Content の BOM 付き UTF-8 を WriteAllText BOM なしに変更、
    コメント・メッセージを全て英語に統一。
2026-05-02 feat: AT+SH* を使った HTTPS/ファイル操作を実装
    SIM7080G の AT+CA* 系が MQTT 接続後にブロックされる問題を回避するため、
    独立した AT+SH* スタックで HTTPS GET・ダウンロード・ファイル読み取りを実装。
    lte.readFile / https.get / https.download を追加。ota.apply の setPendingJobId を
    書き込み成功後に移動し、接続失敗時に Job が FAILED にならないよう改善。
    [lte.cpp, main.cpp]
2026-05-02 fix: readFile のエラー時 CFSTERM 漏れを修正、テストコードを削除
    [lte.cpp, main.cpp]
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2026-05-02 feat: OTA ダウンロードフローを AT+HTTPTOFS+CFSRFILE に刷新・Job 状態報告を修正
    - apply(): https.get() ストリーミングを廃止し AT+HTTPTOFS でSIM FSにDL後
    CFSRFILE でチャンク読み取りして OTA 書き込みに変更
    （AT+SHCONF URL 64 バイト制限を回避）
    - CFSRFILE チャンクサイズ 512 → 4096 バイトに拡大（書き込み高速化）
    - reportPendingJobResult(): ロールバック判定を next パーティションの
    ABORTED 状態で行うよう修正。MQTT 失敗時は job_id を残してリトライ
    - FIRMWARE_VERSION を 1.2.0 に更新・ota.check() を有効化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
    [config.h, lte.cpp, main.cpp]
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2026-05-02 docs: ドキュメントを現状に更新
    - FIRMWARE_VERSION を 1.3.0 に更新（CONTEXT.md × 2）
    - lte: deleteFile 追加を反映（ARCHITECTURE.md・CONTEXT.md × 2）
    - https: AT+HTTPTOFS ダウンロードの記述に修正（ARCHITECTURE.md・CONTEXT.md × 2）
    - ファイル構成に ble_scan・https・domain BLE ファイル群・lib/uzlib を追記
    - インスタンス表に https・bleScanner・bleTargets を追記
    - 将来の拡張候補: BLE スキャンを「基盤実装済み」に更新
    - README: ハードウェア表に OLED を追加
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2026-05-03 feat: OLED+2ボタン設定メニューを実装
    - service/menu: BLE登録・削除・センサー確認・再起動のステートマシン
    - device/button: デバウンス・長押し検出（ButtonEvent）
    - device/oled: メニュー描画関数追加（Menu/Message/Confirm/SensorData）
    - device/ble_scan: registrationMode フラグで未登録機器もスキャン可能に
    - device/speaker: bootStart メロディ追加・playMelody のセンチネル方式修正
    - main: BTN0 長押し起動でメニューモードへ、button.begin を setup に移動
    - docs: MENU.md・DUAL_CORE.md を追加
    [button.cpp, button.h, main.cpp]
2026-05-03 docs: ドキュメントの重複・散在を整理
    - ARCHITECTURE.md: m5atom 固有部分を削除、システム全体構成図のみに縮小
    - CONTEXT.md: esp32 重複セクション（HW・定数・ビルド環境等）と m5atom_power_adc 設計メモを削除
    - HARDWARE.md: ルートから m5atom_power_adc/ に移動、GPIO 確定値・INA228 詳細を統合
    - m5atom_iot_gateway/ARCHITECTURE.md: 新規作成（ルートから移植）
    - esp32_iot_gateway/CONTEXT.md: 完了済み TODO 削除・フェーズ4実装済みに更新・参照リンク修正
    - CLAUDE.md: 参照先リストを実態に合わせて更新
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2026-05-03 fix: BTN1 長押しで CONTINUOUS↔DEEP_SLEEP をトグル切り替えに変更
    [main.cpp]
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2026-05-03 fix: setup() に bleTargets.load() を追加（通常起動時もフィルタが機能するように）
    [main.cpp]
2026-05-03 fix: DeepSleep 前に 1500ms 待機して MQTT 送信完了を保証
    SIM7080G の AT+SMPUB は内部バッファへの書き込み完了で OK を返すが、
    TCP 送信は非同期のため直後に AT+SMDISC を呼ぶとパケットが破棄される。
    1500ms の待機を挟み、IoT Core への到達を保証する。
    [main.cpp]
2026-05-03 docs: CONTEXT.md のデータフローを実態に合わせて修正
    shadow/update は Shadow 更新のみ。BLE センサーデータは
    sensors/{device_id}/data トピックを使用し、
    Topic Rule SQL も topic(2) AS device_id で正しく記載。
2026-05-03 feat: GitHub Actions でファームウェアリリースを自動化
    v* タグ push をトリガーに以下を自動実行:
    - release env でビルド（DEBUG_MODE なし）
    - firmware.bin を S3 にアップロード
    - IoT Job ドキュメントを生成・S3 にアップロード
    - esp32-gw-* の全 Thing に OTA ジョブを作成
    - GitHub Release を作成して firmware.bin を添付
    必要な GitHub Secrets: AWS_ACCESS_KEY_ID / AWS_SECRET_ACCESS_KEY / FIRMWARE_BUCKET
    あわせて deploy_ota.ps1 のビルドディレクトリを
    esp32-s3-devkitc-1-release に修正。
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2026-05-04 refactor: INA228ドライバをIna228クラスに移行、設定値・符号を修正
    - ina228.h/.cpp を Ina228 クラスに変更（定数・ヘルパーを private に収容）
    - SHUNT_CAL を 255 → 4096 に修正（ADCRANGE=1 のため×4 の計算が漏れていた）
    - CONFIG に変換時間（4120us）・平均化（1024 samples）設定を追加
    - readCurrent() の符号を反転（レジスタの増減方向が直感と逆）
    - main.cpp に DEBUG_SKIP_NETWORK マクロを追加（LTE/BLE処理をスキップ可能に）
    [ina228.cpp, main.cpp]
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2026-05-04 docs: INA228クラス化に合わせてCONTEXT・ARCHITECTUREを更新
    - CONTEXT.md: ina228インスタンスを主要クラス表に追加
    - CONTEXT.md: CONFIG レジスタ設定値（VBUSCT/VSHCT/VTCT/AVG）の表を追加
    - CONTEXT.md: ADCRANGE ビット番号を bit2 → bit4 に修正
    - CONTEXT.md: SHUNT_CAL の実際の設定値を 255 → 4096 に修正
    - CONTEXT.md: readCurrent() 符号反転の注意事項を追加
    - ARCHITECTURE.md: INA228 ドライバの説明をクラス化・積算電荷量対応に更新
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2026-05-11 fix: R1を100kΩから1kΩに変更（SBD逆方向漏れによる/EN誤動作対策）
    SBDの逆方向電流はVR=5V付近でも最大500μAに達するフラット特性のため、
    100kΩではV_/EN=5Vとなり/ENしきい値を超えてDCDCが発振する。
    1kΩに変更することでV_/EN≤0.5V（25°C）を確保。
    LCSC部品番号をC25803→C21190に更新。
    [m5atom_power_adc.kicad_sch]
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2026-05-13 fix: addr/id フィルタを大文字小文字を無視して一致させる
    - LOWER(addr) = LOWER(...) でケース非依存の addr フィルタに変更
    - id フィルタ（params.get("id")）を新たに読み取り、battery クエリに LOWER(id) = LOWER(...) で適用
    - _validate_inputs / _build_query に id_filter 引数を追加し _VALID_ID で入力バリデーション
2026-05-13 fix: ラベルの addr/id を小文字に統一して大文字小文字を無視
    - addLabel() でキーを toLowerCase() して保存
    - getLabel() で key.toLowerCase() を使ってルックアップ
    - renderChart() の hidden 判定4箇所を toLowerCase() で参照に変更
2026-05-13 fix: blank.cpp を release/develop ビルドから除外してリンクエラーを修正
    blank env 専用のエントリポイントが main.cpp と同時にビルドされ
    setup()/loop() の多重定義エラーが発生していた
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2026-05-13 docs: v1/v2 → main/sub リネーム・ah 追加・Shadow→S3 TODO を反映
    - Shadow ペイロードのフィールド名変更（v1/v2 → main/sub、ah 追加）を反映
    - ADC ch0/ch1 とバッテリー対応の記述を修正
    - PowerReading・SensorReading の型定義説明を更新
    - Shadow データを S3/Athena に流す方針（Topic Rule 追加）を TODO として追記
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2026-05-13 feat: 起動時 Ah リセットを廃止し、メニューから手動リセットできるように変更
    - main.cpp: 起動時の ina228.resetCharge() を削除
    - menu.cpp: System メニューに Ah Reset 項目を追加（Yes/No 確認ダイアログ付き）
    [main.cpp]
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2026-05-13 fix: shadowPollDelta のタイムアウトを修正・起動時に pending な desired を即適用
    0ms タイムアウトではポーリングループが実行されないため、
    デフォルト 2000ms に変更。起動時は 3000ms で desired を即時適用する。
    [main.cpp]
2026-05-13 fix: delta 適用後に desired:null を publish して desired をクリア
    AWS IoT Shadow は desired を明示的に null にしないと残り続けるため、
    delta 適用時の shadowPublishConfig() に clearDesired=true を渡す。
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2026-05-13 feat: charge_main_batt コマンドを追加（Jobs 経由でリモート充電）
    ジョブドキュメント例:
    {"operation":"charge_main_batt","timeout_sec":1200}
    - V_sub <= V_main のとき FAILED（理由に電圧を含める）
    - 充電中は 5 秒ごとに OLED 更新とシリアルログ出力
    - 完了後に SUCCEEDED を報告
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2026-05-14 fix: queue.flush() 後に delay を追加、低電圧時の自動充電開始を追加
    - queue.flush() 直後に 500ms 待機を追加（SIM7080G 送信バッファ安定化）
    → jobsReport("SUCCEEDED") の MQTT publish 失敗を防ぐ
    - vMain < 11.7V 時に充電 DeepSleep を自動開始（残り30分設定）
    [main.cpp]
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2026-05-14 fix: admin ルートを ANY → GET/PUT/POST 分割（CORS プリフライト 401 修正）
    ANY /admin/{proxy+} が OPTIONS を捕捉して JWT 認証が走り 401 になっていた。
    メソッド別ルートに分割して OPTIONS は API GW の CORS ハンドラーに委ねる。
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2026-05-14 fix: jobs.cpp の受信バッファを 1024 → 4096 に拡張
    presigned URL を含む upload_log ジョブが 1024 バイトを超えて切り捨てられていた。
2026-05-14 revert: upload_log 送信機能を削除（ログ保持は継続）
    SIM7080G の MQTT 受信上限（1024バイト）により presigned URL が届かず断念。
    SPIFFS へのログ記録・debug_log トグルは引き続き有効。
    - command.cpp: upload_log ハンドラ削除
    - log_storage: logStorageUpload() 削除（https.h 依存も解消）
    - jobs.cpp: バッファを 1024 に戻す
    - s3.tf: debug_logs バケット削除
    - admin Lambda / lambda.tf / iam.tf: upload_log・LOG_BUCKET 関連を削除
    - admin.html: 「ログ取得」ボタン削除
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2026-05-14 docs+fix: gzip/HTTPS 実機検証の知見をドキュメント化・コード修正
    SIM7080G.md:
    - AT+SMSSL/AT+SHSSL はどちらもインデックス規則が同じ（0=無効, 1-6=ctindex 0-5）
    - MQTT は AT+SMSSL=1 → ctindex 0 を使用
    - HTTPS は AT+SHSSL=2 → ctindex 1 を使用（MQTT と競合しないため SMDISC 不要）
    - TLS 1.2 は ctindex 1 に AT+CSSLCFG="sslversion",1,3 で設定
    - AT+SHBOD の使い方（'>'プロンプト待ち、バイナリ時は len_body 指定）
    - HTTPS PUT/GET フローを追記
    esp32_iot_gateway/CONTEXT.md:
    - uzlib 圧縮 API の正しい使い方（zlib_start_block+compress+finish_block）
    - writeDestByte コールバック必須、gzip フ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
2026-05-14 docs: 引き継ぎ事項を更新
    - ファイル構成: service/ の不足ファイル（jobs, command, shadow, log_storage, gz_test 等）を追記
    - FIRMWARE_VERSION を 1.10.0 に修正
    - NVS テーブルに debug_log キーを追加
    - OTA gzip TODO に実機検証済みの注記を追加
    CONTEXT.md（ルート）:
    - データフローに admin コンソール（admin.html）を追記
    ops/POWERSHELL.md:
    - $PSScriptRoot を使ったパス解決パターンを追記
    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
2026-05-15 fix: 緊急充電機能を一時的に無効化（動作不安定のため）
    initCharge() をアーリーリターンで無効化し、loop() および
    setup() の充電ロジック・完了報告ブロックをコメントアウト。
    [main.cpp]
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2026-05-17 fix: 充電制御の shadow publish タイミングと NVS 永続化
    - charging を RTC_DATA_ATTR から NVS に変更（電源断をまたいで保持）
    - 充電判定・shadowPublishConfig() を LTE 切断前に移動（モデムオフ後の publish 失敗を修正）
    - 充電制御の有効電圧下限を v>0 → v>=10.0V に変更（未接続時の誤作動防止）
    [main.cpp]
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2026-05-17 docs: esp32_iot_gateway ドキュメントを現状に合わせて更新
    MENU.md:
    - System サブメニューから GZ Test を削除
    - ステートマシンから GZ_TEST 遷移を削除
    - System サブメニューの記述を修正（Info/Device QR/Relay Mode/NVS Clear）
    DUAL_CORE.md:
    - 起動シーケンスを setup+loop 分離の現アーキテクチャに更新
    - BLE スキャンが本番モードでも動作することを明記
    RELEASE.md:
    - firmware.bin.gz 生成ステップを追加
    - S3・OTA Job・GitHub Release が .bin.gz を使うことを明記
    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
2026-05-31 docs: main.cpp 先頭コメントの関数名を現状に合わせて修正
    measureAndPublish() → measure() + publish()
    [main.cpp]
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2026-05-31 fix: エンジン始動後の LTE 切断・タイムスタンプ異常・BLE スキャン欠落を修正
    - CONTINUOUS モードで LTE 切断時に lte.connect() で再接続を試みる
    - MQTT 接続失敗時に GPRS を確認し必要なら再接続してリトライ
    - syncTime() で RTC が正常な場合はモデムの過去時刻で上書きしない
    - BLE 接続時にコネクションインターバルを 500ms〜1000ms に延長してスキャンと共存
    - enterMenuMode() が CONTINUOUS を返した際に g_bleUpgradedToContinuous をセット
    [lte.cpp, main.cpp]
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2026-06-01 feat: 新基板での CAN/OBD 動作確認・全対応 PID ポーリング実装
    - blank.cpp: GPIO を新基板仕様（TX=7/RX=8/EN=9）に変更、ボタンリセット追加、
    pollObd() で全対応 PID（STFT/LTFT/O2/Lambda/CAT 等）を 2 秒周期で出力
    - can_minimal.cpp: MCP2562FD 単体確認用の最小 TX テスト（125kbps NO_ACK）
    - platformio.ini: can_minimal env を追加
    - OBD.md: フェーズ1.5 完了（OBD-II ポートでは生 F-CAN 不可と判明）、
    確定 PID 一覧を実機確認済み全 PID に拡充、GPIO ピン番号を実機値に修正
    - CAN_TEST.md: フェーズ1.5・新基板確認・pollObd 確認を完了済みに更新
    - main.cpp: GU0_EN ピン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
    [blank.cpp, can_minimal.cpp, main.cpp]
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2026-07-04 refactor(esp32_iot_gateway): 全デバイス層のピン参照をboard_pins経由に移行
    - oled.cpp: SDA_PIN/SCL_PIN を boardPins().sdaPin/sclPin に置換
    - speaker.cpp: BUZZER_PIN を boardPins().buzzerPin に置換
    - button.h/.cpp: static const BTN0/1_PIN を非staticメンバに変更し、begin()でboardPins()から初期化
    - lte.h/.cpp: LTE_RX/TX/EN_PIN の宣言をlte.hからlte.cppへ移し、boardPins()から初期化
    - config.h/service/menu.cpp/main.cpp: CHG_ON_PIN(#define)をboardPins().chgOnPinに置換
    - main.cpp: RELAY_0/1/2_PIN, GU0_EN(#define)をboardPins()参照に置換
    [button.cpp, button.h, config.h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]
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2026-07-04 feat(esp32_iot_gateway): m5atom_power_adc v2基板のピン設定を追加
    - board_pins_v2.cppを新設し、v2基板の実ピン値を設定
    （LTE=4/5/6, GU=7/8/9, PWR_HOLD=10, GP2/GP3=2/3, GP11/GP12=11/12,
    Relay=13/14/15, SDA/SCL=17/18、Btn/Buzzer/ChgOnはv1と同一）
    - board_pins.cppにBOARD_VERSION==2の分岐を追加
    - platformio.iniにesp32-s3-devkitc-1-v2-develop環境を追加
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2026-07-04 docs(esp32_iot_gateway): board_pins・PWR_HOLD実装をARCHITECTURE/CONTEXTに反映
    - ARCHITECTURE.md: srcツリーにboard_pins.h/.cpp/_v1.cpp/_v2.cppを追加、
    button.h/.cppの説明・依存ルール図を更新
    - CONTEXT.md:
    - config.h/lte.hの定数一覧からCHG_ON_PIN/LTE_RX/TX/EN_PINを削除
    （board_pins.h経由に変更されたため）
    - LTEピンの実配線（GPIO7/8/9、基板シルクとの不一致）を修正
    - 「board_pins.h / 基板バージョン切り替え」節を新設（v1/v2ピン対応表）
    - ビルド環境にenv名一覧（v1-develop/v2-develop/release）を追加
    - v2.0.0自己保持回路TODOをファームウェア実装済みに更新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
2026-07-04 docs(m5atom_power_adc): CIRCUIT.mdのGPIOピンアサインを実態に修正
    - v1のLTE/GU信号がIO4-6とIO7-9で逆に記載されていたのを修正
    （ファームウェアのboard_pins_v1.cppを正とする。筐体都合による実配線）
    - SPEAKERピンをIO35からIO34に修正（firmware実値と一致させる）
    - v2セクションを新設（PWR_HOLD, GP2/GP3, GP11/GP12を追加）
    - RelaySense0/1/2（GPIOによる直接検出）がv2で廃止されたことを明記
    （J11/J12/J13コネクタ自体は存置）
    - コネクタ一覧にv2のI2C拡張コネクタJ107/J108を追加
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2026-07-28 docs: telemetryエンコーダ・corruptedバケット等、実装との乖離を修正
    - ARCHITECTURE.md: corruptedバケット（破損データ退避用）を追加
    - esp32_iot_gateway/ARCHITECTURE.md: telemetry.h/.cppの説明をITelemetryEncoder構成に更新、
    抜けていたsensor_filter.h/.cpp・log_storage.h/.cppを追加
    - esp32_iot_gateway/CONTEXT.md: ファイル構成ツリー・ドメイン型テーブルを同様に更新
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2026-07-30 fix: 継続モード中も1秒ティックでShadow deltaをポーリングする
    continuousLoopCore()は5分待機ループの間loop()に戻らないため、
    CONTINUOUS/CONTINUOUS_OBD/ONE_SHOT_CONTINUOUS中はshadowPollDelta()が
    最大5分間呼ばれず、override_next_mode等のリモート設定変更の反映が
    遅延していた。1秒ティックにshadowPollDelta()を追加し、継続モード中
    でも実質的に即時反映されるようにした。
    [main.cpp]
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2026-07-30 fix: BLEペアリング失敗・設定Characteristic読み取り不可を修正
    スマホとのペアリングがPasskey入力後に失敗する不具合と、設定サービス
    （Ah Offset等）がREADできない不具合を修正。
    - onConnect直後のコネクションパラメータ変更（500〜1000msへの延長）が
    ペアリングのSecurity Managerハンドシェイクと競合し認証が失敗していた。
    onAuthenticationComplete後（認証確定後）に変更するよう順序を入れ替えた
    - 設定サービスの4Characteristic（Ah Offset/Chg Timeout/Chg Start/Chg Stop）に
    READ_AUTHEN/WRITE_AUTHENのみ指定していたが、これは認証要件のビ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
2026-07-30 fix: CANピン割当修正・診断ログ追加・バルクポーリング削除・CONTINUOUS_OBD統合
    - CAN RX/TXピン割当を修正（GPIO4=RX/GPIO5=TXに、ドキュメント通りに是正）
    - CAN/OBD周りに診断ログを追加（TWAI状態・エラーカウンタ、送受信失敗、未一致フレーム受信）
    - 未検証・未対応と判明したOBDバルクポーリング機能一式を削除
    - CAN init/deinitを起動直後〜DeepSleep突入時のみのライフサイクルに変更
    - CONTINUOUS_OBDモードをCONTINUOUSに統合（OBDポーリングは常時バックグラウンドで実行）
    [can.cpp, config.h, main.cpp]
2026-07-31 fix: DeepSleep起床時にBLE接続を待つ猶予を追加
    スマホアプリの接続ボタンとデバイスの5分周期起床のタイミングが
    合わないと接続できない問題への対応。起床時にBLE未接続なら
    BLE_WAKE_WINDOW_SEC(15秒)だけ接続を待ってからDeepSleepに入る。
    [config.h, main.cpp]
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2026-08-01 feat: S3 rawデータの定期compaction Lambdaを追加
    Shadow reportedの不正キーを自動検知・修正するLambdaを追加した流れの続き。
    GrafanaがAthena経由で1hourパーティションあたり平均約29件の小さいJSONファイルを
    15分おきに繰り返し開いており、これがS3リクエスト課金（Tier1/Tier2）の主因。
    - infra/lambda_src/compact/index.py: 確定済みhourパーティション内の小ファイルを
    改行区切りJSON(_merged.json)にまとめるLambda。冪等（stragglerが無ければ何もしない）。
    ThreadPoolExecutorでGet/Copy/Delete並列化。マージ元はarchiveバケットへ退避してから削除
    - inf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
2026-08-01 fix: compact Lambdaのマージファイル名がAthenaから見えない不具合を修正
    _merged.json という命名がHadoop系InputFormat（このGlueテーブルのTextInputFormat含む）
    の「先頭が_/.のファイルは隠しファイルとして無視する」慣習に該当し、圧縮済みパーティション
    のデータがAthena/Grafanaから丸ごと見えなくなっていた（S3上には残っておりデータ消失はなし）。
    merged.json に変更。既存72件の_merged.jsonはaws s3 mvで手動リネーム済み。
    あわせてレビューで見つかった3点も修正:
    - 全stragglerが不正JSON等で有効な行0件の場合もarchive+削除するよう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
2026-08-01 fix: compact Lambdaの同時実行レースとコネクションプール枯渇を修正
    カナリア実行で以下2点が判明したため対応:
    - マージ書き込み後・元ファイル削除完了前に別実行が同じパーティションを読むと、
    未削除のstragglerがmerged.jsonの既存内容と二重に数えられ重複行が発生しうる。
    reserved_concurrent_executions=1でこの関数の同時実行を構造的に1つに制限し、
    レースそのものを起こらなくする（スケジュール実行と手動バックフィルが鉢合わせても
    EventBridge Schedulerのデフォルトリトライで後追いされるだけで実害なし）
    - Thr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
2026-08-01 test: delete Lambdaにユニットテストを追加、複数Lambda同時実行時の名前衝突を修正
    _parse_records（単一JSON/NDJSON両対応）・_delete_from_partition・_delete_by_keys・
    handlerの権限/バリデーション/分岐を計24ケースでカバー。Athenaは実SQL実行までは
    motoで面倒を見られないため、_get_partitionsをmonkeypatchして迂回。
    追加時に判明した問題2点を合わせて修正:
    - compact/delete両方のconftest.pyが"import index"という共通モジュール名で
    ロードしていたため、同一pytestプロセス内でsys.modulesが衝突し、片方の
    テストがもう片方のindex.pyを見てしまってい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
2026-08-04 feat: ISO-TPマルチフレーム受信の最小実装
    canReceiveObdResponse() をFirst Frame/Consecutive Frameに対応させ、
    Flow Control自動送信込みでマルチフレーム応答を組み立てられるようにした。
    SF/FF/CFの判定はPCIバイト（data[0]&0xF0）で分岐し、SFの長さもdlc-1固定
    ではなくPCI宣言長（data[0]&0x0F）から正しく取るよう修正。
    FC宛先IDは受信した応答IDの下位バイト（ECUアドレス）から都度導出し、
    ハードコードしない。CF間タイムアウトは50ms固定。BS>0/STmin対応など
    全二重の作り込みは行わない（HANDOFF_isotp_multipid.md タスク1準拠）。
    maxLen引数を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
    [can.cpp]
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2026-08-08 fix: INA228のADC_CONFIGレジスタ書き込み先の取り違えを修正
    VBUSCT/VSHCT/VTCT/AVGビットはADC_CONFIG(0x01)用のレイアウトだが、
    CONFIGレジスタ(0x00)に書き込んでいたため平均化1024サンプルが
    実際には効いておらず、CONFIG側の予約ビット・CONVDLY・TEMPCOMPが
    意図せず設定されていた。CONFIG/ADC_CONFIGを別定数に分離し、
    それぞれ正しいレジスタに書き込むよう修正。
    [ina228.cpp]
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2026-08-08 fix: BTN1長押しでのDEEP_SLEEP強制がBLE接続中に即座に上書きされる不具合を修正
    BLE接続でCONTINUOUSに自動昇格した後、BTN1長押しで手動DEEP_SLEEPへ
    切り替えても、continuousLoopCore()のwhileループはモード変更を見ずに
    最大waitMs（5分境界まで）走り続け、戻ってきたloop()冒頭の
    「BLE接続 && DEEP_SLEEP」判定がBLE接続を理由に即CONTINUOUSへ
    昇格し直してしまい、ユーザーの選択が事実上効かなかった。
    - continuousLoopCore(): whileループの継続条件にg_mode==hooks.selfModeを
    追加し、モードが変わったら即座にmodeManagerへ制御を返すようにした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
    [main.cpp]
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2026-08-09 fix: モデム応答サイズをバッファ容量でクランプせず書き込むバグを修正
    Lte::fileReadChunk()（device/lte.cpp）とwaitShreadHeader()
    （service/https.cpp）が、SIM7080Gの+CFSRFILE/+SHREAD応答から読み取った
    サイズ(actual)を呼び出し側バッファの容量と突き合わせずにそのまま
    書き込んでいた。モデムが誤応答（化け等）でactualを実際より大きく
    返した場合、OTA中に固定サイズバッファ（s_gz.buf/chunk[]）を越えて
    書き込む可能性があった。
    actualが容量を超えていたらエラー（-1）として扱うよう修正
    （超過分の破棄ではなくエラー扱い。誤応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
    [lte.cpp]
2026-08-09 fix: センサー/CAN初期化失敗をログ出力するよう修正
    setup()内のadsInit()/ina228.init()/canInit()はいずれもbool戻り値で
    初期化失敗を伝える設計だが、戻り値が確認されておらず異常を検知する
    手段がなかった。失敗時にlogger.println()で警告ログを出すよう修正
    （SPIFFSログにも永続化されるため事後調査可能）。
    CONTEXT.mdのTODOをCONTEXT_ARCHIVE.mdへ実装済みとして移動。
    [main.cpp]
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2026-08-09 fix: main.cppのGPIO_NUM_0をWAKE_PIN定数として定義
    enterDeepSleepMode()内でGPIO_NUM_0が4箇所生の値のまま使われており、
    CLAUDE.mdの「ピン番号は定数化する」規約に反していた。ESP32-S3モジュール
    内蔵のBOOTボタンで基板（v1/v2）によらず固定のピンのため、board_pins.h
    ではなくmain.cpp側（アプリ層）で#define WAKE_PIN GPIO_NUM_0とし、
    CLAUDE.mdの「アプリ層: #define」規約に対応した。
    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
    [main.cpp]
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2026-08-09 fix: CONTINUOUSモード5分境界でのBLEスキャンによるOBDポーリング停止を解消
    measure()が呼ぶbleScanner.start()がNimBLEの同期ブロッキング版で、
    5分境界ごとに最大10秒間continuousLoopCore()のOBDティック/ボタン監視を
    完全に止めていた問題を修正。
    - device/ble_scan.h/.cpp: 非同期版startAsync()/isScanning()/stop()を追加
    （既存のブロッキング版start()はmenu.cppのBLE登録画面用にそのまま残す）
    - service/monitor.cpp: publish()をpublishBattery()/publishBle()に分割し、
    スキャン完了時のみ収集するcollectBle()を追加
    - main.cpp: g_blePendingフラグとpollBleCollect()を追加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
    [main.cpp]
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2026-08-09 docs: CAN GPIOピン割当コメントを実装に合わせて修正
    can.cpp/can.h/OBD.mdのTX=GPIO4,RX=GPIO5というピン番号コメントが実装と逆だった
    （gu00Pin=4, gu01Pin=5が正）。実車動作確認済みのコードを正とし、コメント・文書側を修正。
    [can.cpp]
2026-08-09 fix: ISO-TP SF/FF長の異常値検証を追加
    SFのPCI下位ニブルは0-15を取りうるが正当な長さは1-7のみ。壊れたフレームでlen=15等が
    来るとrx.data（8バイト配列）の範囲外readが起きうるため、1-7の範囲外を明示的に弾く。
    FFのtotalLenも8バイト未満はISO-TP規格上SFで送られるはずのため不正値として弾く。
    [can.cpp]
2026-08-09 fix: CFの送信元IDをFF送信元に固定して別ECU混入を防ぐ
    機能アドレッシング（0x18DB33F1）はブロードキャストのため複数ECUが応答しうる。
    従来はisObdResponseFrame()で0x18DAF1xxを全て通していたため、FFを送ってきたECUと
    別のECUのCFが同一メッセージに混入する余地があった。FF受信時のrx.identifierを
    receiveConsecutiveFrames()にラッチして渡し、CF側で一致を要求するようにした。
    [can.cpp]
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2026-08-09 feat: 否定応答(0x7F)を認識できるようにする
    canReceiveObdResponse()の戻り値をboolからObdRecvResult（Ok/Timeout/NegativeResponse/
    Error）に変更。7F [SID] [NRC]（常にSFで収まる3バイト）を受信した場合はNegativeResponse
    を返し、nrcOut引数（省略可）にNRCを書き込む。Mode 01では実害が薄いが、将来のMode 22
    DIDスキャンでは7F 22 31（DID非対応）と7F 22 78（応答待ち延長）の識別が必須になるため、
    着手前に受信層のインターフェースを整えた。呼び出し側（obdpoll.cpp）は== Okへの書き換えのみ。
    [can.cpp]
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2026-08-09 fix: millis()比較をオーバーフロー安全な形に変更
    直接比較（millis() < deadline等）は約49.7日でmillis()がラップした際に誤動作する。
    減算イディオム（(int32_t)(millis()-deadline)）へ変更。CONTINUOUS_OBDは手動モードのため
    現状リスクは低いが、車両常時電源での長期稼働を見据えた対策。
    [can.cpp]
2026-08-09 fix: バッファ超過時にFC overflow(FS=2)を送信
    totalLen>maxLenで黙ってfalseを返すと、ECUはFC待ちのままN_Bsタイムアウト（規格上1秒）まで
    送信状態を保持し続ける。30 00 00（CTS）の代わりに32 00 00（FS=2, overflow）を返すことで
    ECUに即座の打ち切りを通知できる。sendFlowControl()にflowStatus引数（既定CTS）を追加した。
    [can.cpp]
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2026-08-17 fix: ACC検知回路にサージ制限抵抗を追加、J109をDNP化
    - R115(1kΩ)をD109アノード-GND1間に追加。ロードダンプサージ時のD109通過電流を制限しつつ、Q105ベース駆動経路（ACC→内蔵R1=10kΩ）には抵抗を挟まず通常動作への影響をゼロに保つ
    - J109(ACC入力ピンヘッダー)はスルーホールパッドとしてのみ使用し部品は実装しないため、DNP(Do Not Populate)を設定
    [m5atom_power_adc.kicad_sch]
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2026-08-18 fix: CONTINUOUS系モード中もOTA/コマンドJobsを定期確認するよう修正
    OTAチェックがsetup()内でしか呼ばれず、CONTINUOUS/TIMED_CONTINUOUSに
    留まり続けている間はJobsが永久に降ってこない問題があった。
    Jobs確認処理をcheckAndHandleJob()として切り出し、continuousLoopCore()が
    5分境界ごとに戻るタイミングでも呼ぶようにして解消した。
    [main.cpp]
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2026-08-20 feat: Mode22(UDS)実装とBLEパケットフォーマットの堅牢化 (#37)
    * docs: trip_analysis実装の引き継ぎ文章を追加、AI検証ログを分離
    ai-poc/DESIGN_LOG.md(gitignore対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
    [can.cpp]
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2026-08-21 fix: 圏外時のオフラインバッファ・再接続まわりの不具合を修正
    - LTE再接続にクールダウンを追加し、圏外中に複数箇所から60秒待ちが
    何重にも積み重なりDeepSleepの節電サイクルに戻れなくなる問題を解消
    - BLE切断検出をcontinuousLoopCore()の1秒ティックに移し、
    CONTINUOUSモードからの復帰が最大5分遅延する問題を解消
    - pubqueueのSPIFFSバックアップを再有効化。EN pinリセット
    （USBモニタ接続時の自動リセット回路含む）・ブラウンアウト等で
    RTCメモリが消えても圏外中の未送信データを復元できるようにした
    （実機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
    [lte.cpp, main.cpp]
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2026-08-23 chore: FIRMWARE_VERSION を更新（v1: 1.24.1, v2: 2.2.1）
    DeepSleep突入前のBLEデータ送信欠落修正（#41）を反映。
    [config.h]
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
